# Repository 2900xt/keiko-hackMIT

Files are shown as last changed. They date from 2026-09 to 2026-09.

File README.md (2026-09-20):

<div align="center">

# 🐋 Keiko

**Hydrophones in Boston Harbor that turn underwater sound into a live, searchable stream of what's happening on the water** — whale species, where they are, how the soundscape is drifting, and an alert when a right whale is heard.





Built by [Moby Labs](https://github.com/2900xt) · Taha Rawjani ([@2900xt](https://github.com/2900xt)) · Matthew Li ([@Mallhw](https://github.com/Mallhw))

</div>

---

```mermaid
flowchart LR
    subgraph nodes["Nodes  ·  piezo hydrophone → ADC → UDP"]
        direction TB
        UNOQ["Arduino UNO Q<br/>STM32U585 → Bridge → Linux<br/>3.3 kHz · 14-bit"]
        ESP["ESP32-S3 DevKitC-1<br/>hw-timer ISR → USB-CDC / Wi-Fi<br/>8 kHz · 12-bit"]
        NRF["nRF7002 DK<br/>nRF5340 SAADC → nRF70 Wi-Fi<br/>8.2 kHz · 12-bit"]
    end

    nodes -- "KEIK datagrams :5005" --> PIPE

    PIPE["pipeline/keiko_pipeline.py<br/>3 s windows @ 1.5 s hop → whale CNN v2 (22 classes)<br/>→ abstain rule → event = run of whale windows"]

    PIPE -- always --> OUT["pipeline/out/<br/>WAV clips + events.jsonl"]
    PIPE -- "--archive" --> SITE["site/data/<br/>clip + spectrogram + CSV/JSON<br/>→ GitHub Pages"]
    PIPE -- "--server" --> SRV["server/keiko_server.py<br/>TDOA fix + tracks<br/>→ WebSocket → Live map"]
    PIPE -- "--elastic" --> ES["Elasticsearch<br/>keiko-windows · keiko-detections<br/>geo_point · 512-d vector · ELSER · ML anomaly"]

    ES --> KIB["Kibana dashboard<br/>ES|QL alert → Discord/Slack<br/>ask.py (Claude ⇄ ES|QL / kNN / ELSER)"]
```

```mermaid
flowchart LR
    DS["training/dataset<br/>126k clips · 9 sources"] --> CNN["whale CNN v2<br/>(laptop, width 32)"]
    CNN --> VOLO["Voloridge AWS GPU<br/>width 64 · 5 seeds · Charles fine-tune"]
    ISD["NOAA ISD<br/>s3://noaa-isd-pds"] --> JOIN["⋈ buoy noise floor<br/>how much of the background is weather?"]
```

## Table of contents

| | |
|---|---|
| [How it works](#how-it-works) | capture → classify → fan out → ask |
| [Sponsor integrations](#sponsor-integrations) | Arduino · Espressif · Nordic / Hackster · Elastic · Voloridge |
| [Wire protocols](#wire-protocols) | `KEIK` · `KBLK` · WebSocket · detection database |
| [Models](#models) | whale CNN v2 · Moby right-whale ensemble · location table |
| [Repository layout](#repository-layout) | what lives where |
| [How to run](#how-to-run) | no-hardware demo → full stack → each node → Elastic → Voloridge |
| [Tests](#tests) | one command per subsystem |

## How it works

1. **Capture.** A piezo-disc hydrophone (three 27 mm discs in parallel, potted in epoxy — `hardware/hydrophone-cup/`) feeds
   an analog front end into a microcontroller ADC. Three node designs exist (UNO Q, ESP32-S3, nRF7002 DK); each samples in a
   timer-paced thread into 256-sample blocks and ships them as identical `KEIK` UDP datagrams, so the pipeline does not care
   which board is on the other end. Node id, sample rate and timestamps travel in the header.
2. **Classify.** `pipeline/keiko_pipeline.py` reassembles the stream per node, resamples to 32 kHz, cuts 3 s log-mel windows
   (128 mel, 10 Hz–16 kHz, n_fft 1024, hop 320) every 1.5 s and runs the whale CNN v2 (~1.2 M params, ~15 ms/window on an
   M-series CPU). An abstain rule (`P(any whale) − P(no_whale) > margin` **and** top whale class `≥ min_conf`) turns the 22-way
   softmax into whale / no-whale; ≥ 2 consecutive whale windows open an *event*, 2 no-whale windows close it, 30 s hard cap.
3. **Fan out.** Every event lands in `pipeline/out/` as a WAV clip + JSONL line. Flags add sinks: `--archive` writes the
   detection database the website reads, `--server` streams telemetry/audio/windows/events to the central server (TDOA
   localization + tracks + WebSocket to browsers), `--elastic` indexes every window and event into Elasticsearch.
4. **Ask.** Kibana dashboards, an ES|QL alert rule, kNN "sounds like" over the CNN embedding, ELSER semantic search over
   generated descriptions, an ML anomaly job on the soundscape, and `ask.py` — a Claude agent that writes and runs ES|QL.

## Sponsor integrations

| Sponsor | Track | What we built | Where |
|---|---|---|---|
| **Arduino** | Touch Grass | UNO Q node — the one that went in the water. Zephyr MCU sampler → Bridge → Linux Python forwarder, hot-reloadable config, USB relay | [`firmware/unoq/`](firmware/unoq/) |
| **Espressif** | Best Use of Espressif Hardware | ESP32-S3 wideband node, USB-CDC `KBLK` frames or standalone Wi-Fi `KEIK`; parametric buoy hull | [`firmware/esp32-s3/`](firmware/esp32-s3/) |
| **Nordic** | Hackster "Create What's Next" | nRF7002 DK node — sampler + Wi-Fi entirely on the nRF5340, Kconfig-driven, host simulator | [`firmware/nrf7002/`](firmware/nrf7002/) |
| **Elastic** | Find the Signal | Two indices (geo, dense_vector, ELSER), ES\|QL library, kNN + semantic search, ML anomaly job, alert rule, Claude ⇄ ES\|QL agent | [`elastic/`](elastic/) |
| **Voloridge** | Signal in the Noise | GPU training runs on their AWS + NOAA ISD ⋈ hydrophone noise-floor analysis | [`training/voloridge/`](training/voloridge/) |

<details>
<summary><b>Arduino — UNO Q</b> (Touch Grass) · <code>firmware/unoq/</code></summary>

The UNO Q is the node we actually ran in the water. It is two computers on one board and we use both:

- **MCU side (STM32U585, Zephyr via `arduino:zephyr:unoq`).** `sketch/hydro.cpp` runs a cooperative thread paced by a kernel
  timer, reads `A0` with the 14-bit ADC at 3333 Hz (`SAMPLE_PERIOD_US` must be a multiple of the 100 µs Zephyr tick), fills
  a ring of 256-sample blocks, and pushes each block over **Bridge** with `Bridge.notify("hydro/block", …)`. The `.ino` is an
  empty stub so the prototype generator never touches the code.
- **Linux side (Python in an App Lab container).** `python/main.py` receives the notifications, measures the true sample
  rate from MCU timestamps, prints a health line once a second (`fs= 3333.3Hz blocks/s= 13 dc=1.71V rms= 4.2mV …
  mcu_drops=0 missing=0`), forwards every block as a `KEIK` datagram to `KEIKO_UDP_HOST:5005`, and optionally appends a WAV.
  Outside App Lab it speaks MessagePack-RPC to `/var/run/arduino-router.sock` directly.
- **Configuration without restarts.** App Lab's `app.yaml` has no env section, so settings live in `python/keiko.env`; the
  node re-reads it every second, so `make retarget UDP_HOST=<ip>` redirects the stream with no restart (a restart re-flashes
  the MCU over SWD, so hot reload is the normal path).
- **Analog front end (3.3 V, not 5 V tolerant).** Two PN2222 as a Darlington emitter follower, ~1 MΩ input impedance, mid-rail
  bias, output idling at ~1.7 V (`dc=` on the health line must read 1.5–1.9 V or the follower is miswired).
- **Deployment over USB (adb).** A fresh board has SSH off; `make start` rsyncs the app to `~/ArduinoApps/keiko-unoq` over
  `adb push` and runs `arduino-app-cli app restart`, which compiles the sketch *on the board*, flashes the MCU, and starts
  the container. `make wifi SSID=… PSK=…` joins a hotspot over USB (`nmcli`). `VIA=ssh` switches every target to SSH.
- **USB fallback for the audio.** Venue Wi-Fi isolates clients, and adb cannot forward UDP, so `pipeline/usb_relay.py`
  wraps each datagram in a length prefix on the board, sends it down `adb reverse tcp:5006`, and unwraps it onto UDP on the
  laptop (`VIA=usb make live`). ~7 kB/s, no drops.

> [!WARNING]
> The Bridge UART runs at 115200 baud (~11 kB/s), which caps 16-bit audio at ~3.3 kHz (Nyquist 1.67 kHz): fine for
> baleen whales and boats, not dolphin clicks — hence the two wideband nodes below. The front end is **3.3 V, not
> 5 V tolerant**.

</details>

<details>
<summary><b>Espressif — ESP32-S3-DevKitC-1 (N8R8)</b> (Best Use of Espressif Hardware) · <code>firmware/esp32-s3/</code></summary>

The wideband, laptop-optional node. Same analog front end as the UNO Q, on **GPIO1 = ADC1_CH0** (ADC2 is shared with the
Wi-Fi radio and returns garbage while it is on).

- **Sampler.** A 1 MHz hardware timer ISR wakes a FreeRTOS task that `analogRead`s at 8 kHz (12-bit, 11 dB attenuation →
  0–3.1 V) into a ring of 256-sample blocks. `analogRead` costs ~25 µs, so the period can drop to ~50 µs (20 kHz) before
  ticks are missed.
- **Two transports, selected at compile time.**
  - *USB mode:* frames go out over the **native USB-Serial-JTAG** port (~1 MB/s, so no UART bottleneck) as `KBLK` frames with a
    CRC-16/CCITT-FALSE, resynchronised on the magic if a byte is lost. `python/main.py` on the laptop validates the CRC,
    re-emits each frame as a `KEIK` datagram, and prints the health line (adds `crc_bad=`).
  - *Wi-Fi mode:* copy `sketch/wifi_config.h.example` → `wifi_config.h` (gitignored) with SSID/PSK/pipeline address and
    reflash. The board then builds the `KEIK` datagram itself (`fs` measured on-board, `t_ns` = `esp_timer_get_time()` × 1000)
    and sends it straight to the pipeline. Serial frames still flow when a host is attached; unplugged, the sender skips
    serial so a stalled USB write can never block the Wi-Fi path.
- **Build.** `sketch.yaml` profile `esp32:esp32:esp32s3` with native USB CDC, 8 MB flash, octal PSRAM; `make flash`
  auto-detects `/dev/cu.usbmodem*`. First flash over native USB may need BOOT-held + RESET.
- **Buoy.** `hardware/buoy-v2/` is a parametric OpenSCAD hull sized for exactly this DevKitC plus a 5,000 mAh bank, antenna
  ~31 mm above the waterline, reviewed adversarially by OpenAI Codex (`codex_*.md`).

</details>

<details>
<summary><b>Nordic Semiconductor — nRF7002 DK</b> (Hackster "Create What's Next") · <code>firmware/nrf7002/</code></summary>

A port of the UNO Q sampler to the nRF5340 app core with **no Linux side at all**: the MCU owns the Wi-Fi link.

- **Stack.** Zephyr / nRF Connect SDK v3.0 (`nrf7002dk/nrf5340/cpuapp`, `CONFIG_WIFI_NRF70`), IPv4 + DHCP + UDP sockets,
  `CONFIG_DNS_RESOLVER` so the UDP target can be a hostname. `src/main.c` has the same kernel-timer-paced sampler thread and
  ring as the UNO Q, then a sender loop on `main` and a health line on the J-Link VCOM0 console. LED1 blinks with the
  sampler, LED2 is on while Wi-Fi is up. Wi-Fi drops reconnect with the same `seq` counter; the sampler never stops.
- **ADC.** SAADC channel 0 on AIN0 (`P0.04`, the DK's "A0"), gain 1/3 with the internal 0.6 V reference → 0–1.8 V, 12-bit,
  10 µs acquisition. Period is in RTC ticks (32768 Hz), so rates are `32768/N` — default N=4 → 8192 Hz; N=2 → 16 kHz for
  dolphin clicks. `fs` is measured from block timestamps and written into the header, so the receiver never needs N.
- **Analog front end (1.8 V rail).** The Darlington follower does not fit two Vbe drops in 1.8 V and the SAADC does not need
  it (accepts sources ≤ ~200 kΩ at 10 µs; the piezo stack is ~3.5 kΩ at 500 Hz), so it is passive: 10k/10k mid-rail divider
  + 10 µF, 470k bias into the piezo, 10k series into AIN0 with the pin clamps absorbing knocks. `dc=` should read 0.8–1.0 V.
- **Configuration.** `keiko.conf` is Kconfig (`CONFIG_KEIKO_WIFI_SSID`, `_PSK`, `_UDP_HOST` — default `255.255.255.255`
  subnet broadcast so any laptop on the hotspot just listens — `_UDP_PORT`, `_NODE_ID`, `_SAMPLE_PERIOD_TICKS`). Overridable
  per build: `make flash SSID=hotspot PSK=secret UDP_HOST=10.0.0.5`. `Kconfig` declares the options; the packed header
  struct has a `BUILD_ASSERT` on its 26-byte size and `host/test_node.py` checks the Python side against the same layout.
- **No board yet?** `make sim` emits the identical stream from a Mac (`host/sim_node.py`); `make test` checks the packet
  format offline. `make sdk` installs nrfutil + the toolchain (~4 GB); the Makefile wraps `west` in
  `nrfutil sdk-manager toolchain launch` if it is not on PATH.

</details>

<details>
<summary><b>Elastic — Find the Signal</b> · <code>elastic/</code></summary>

Elasticsearch is where the stream stops being audio and becomes something you can ask questions of. Everything below is
provisioned by one script (`setup.py`) against an Elastic Cloud trial and fed live by `pipeline … --elastic`.

**Indices** (index templates in `mappings/`):

| index | one doc per | notable fields |
|---|---|---|
| `keiko-windows` | classifier window (every 1.5 s) | `label`, `whale`, `confidence`, dynamic `probs.*` (22 class probabilities), `audio.rms_db/peak_hz/centroid_hz/bandwidth_hz/flatness`, `net.*` packet loss, `location` `geo_point`, `in_event` |
| `keiko-detections` | event | `species`, `confidence`, `duration_s`, `location` + `buoy_location` `geo_point`, `fix.{err_m,method,arrivals[]}` from the TDOA solve, `embedding` `dense_vector` 512-d cosine, `description` `semantic_text` (ELSER), `track_id` |

**Write path.** `keiko_es.py` builds the docs (`window_doc`, `detection_doc`, `describe`) and bulk-writes through a buffered
writer so the pipeline's 1.5 s loop never blocks on the network. `features.py` computes the spectral descriptors per window and
takes the CNN's pooled 512-d activations (mean‖max over the last conv block) as the embedding — the same tensor the classifier
uses, so "sounds like" is in the model's own feature space. `describe` writes a plain-English paragraph per event for
ELSER to embed ("Confident humpback whale call (0.91) at buoy KEIKO-01 Saturday 20 September 2026 07:35 UTC in the early
morning. Lasted 4.5 s over 3 classifier windows. Low frequency, tonal sound: peak 410 Hz, centroid 520 Hz, level −38 dBFS."),
so "long low moan at night" finds it.
`backfill.py` replays `pipeline/out/events.jsonl` + `site/data/detections.csv` through the same path, re-running the CNN on
each clip for the embedding.

**Read paths.**
- **ES|QL** — `queries.esql` holds 11 queries: what's on the water now, detections per 15 min per buoy, soundscape floor vs
  whale share, hour-of-day, the right-whale question, per-buoy stream loss, the classifier's second guesses, sound character per
  species, centroid of fixes and distance from the harbour entrance, low-confidence windows, field vs synthetic.
- **kNN** — `ask.py --similar <id>` runs a `knn` query on `embedding` to find the events that sound most like a given one.
- **Semantic** — `ask.py --semantic "long low tonal call at night"` runs a `semantic` query on `description` (ELSER).
- **ML** — `setup.py` creates the `keiko-soundscape` anomaly-detection job + datafeed over `keiko-windows` (level jumps,
  unusual spectral character); `ask.py --anomalies` lists its records.
- **Alerting** — an ES|QL rule every minute: `FROM keiko-detections | WHERE species == "North Atlantic right whale" AND
  confidence >= 0.7 …` → webhook connector to Discord/Slack ("slow to 10 kn"). NOAA's seasonal management areas are the reason
  the buoys exist; this is the *action*.
- **Kibana** — `kibana/dashboard.md` is the six-panel Lens recipe (all ES|QL panels) plus data views created by `setup.py`.
- **Agent** — `ask.py "<question>"` gives Claude (`claude-opus-5`) both index schemas, an ES|QL cheat sheet and three tools
  (`esql`, `similar_sounds`, `semantic_search`); it writes the query, runs it, and answers. Guarded to read-only `FROM keiko-*`
  queries. `-v` prints every query it tries.

> [!TIP]
> Without ML nodes (`setup.py --no-elser --no-ml`) `description` degrades to `text` and `--semantic` to a `match` query.
> Unit + integration tests: `test_elastic.py`.

</details>

<details>
<summary><b>Voloridge — Signal in the Noise</b> · <code>training/voloridge/</code></summary>

Two uses of what Voloridge hands out: their AWS instances for training, and NOAA ISD from their curated dataset list for
the insight.

**1. Training on Voloridge compute.** The whale CNN's laptop run is width 32 at ~25 s/epoch over the 5.1 GB v2 tensor set.
On a Voloridge `g5` (Amazon Linux 2023, `us-east-1`) `configs/pretrain_gpu.json` scales this to width 64,
40 epochs, batch 256, then 4 more seeds for a seed-variance estimate, a
`--no_merge_rare` run that gives the 4 rare species their own classes, and `train/finetune.py` transfers the
pretrained model to our own Charles River / Boston Harbor recordings (`data/charles_v2`: motorboat / crew shell / ambient /
rain / unknown; stem + blocks 0–1 frozen). `infra/` is the plumbing: `check.sh` (ssh, `nvidia-smi`, disk, IAM role),
`bootstrap_instance.sh` (dnf, venv, torch cu12, boto3, Voloridge's tools), `sync_up.sh` / `sync_down.sh` (rsync code + tensors
up, `runs/` + `models/` down), `remote.sh run <name> <cmd>` (detached tmux per run, `make logs RUN=…`). Outputs are the same
`runs/<name>/{best.pt,test_metrics.json}` + `models/*.pt` layout as `training/whale_cnn/train.py`, so
`keiko_pipeline.py --model` takes any of them unchanged. Everything is `voloridge.env` (host, user, key — not committed).

**2. NOAA ISD ⋈ hydrophone noise floor.** Boston Logan (USAF 725090 / WBAN 14739, 6 km from the buoy) reports wind,
pressure, precip hourly. The question: how much of the underwater background is weather?
- `data/fetch_isd.sh` uses Voloridge's own `noaa_isd/fetch.py` (synced from `s3://voloridge-hack-mit-2026/src`, read for free
  through the instance's `AmazonS3ReadOnlyAccess` role + S3 gateway endpoint) to pull the station's years from `s3://noaa-isd-pds`.
- `data/parse_isd.py` parses the fixed-width records — mandatory section (wind dir/speed, temp, dew point, SLP, visibility) +
  the `AA1` precipitation group — drops rows with failing QC codes, resamples to the hour.

> [!NOTE]
> **Two sources, one table.** The public ISD archive trails the present by months (ISD is the *archive* of the ASOS/METAR
> reports the NWS API serves live), so `data/fetch_nws.py` pulls
> `api.weather.gov/stations/KBOS/observations` for the recording window, maps it onto the same columns, and merges with a
> `source` column (`isd` / `nws`) — same instrument, same station, hours old instead of a year.

- `analysis/noise_floor.py` computes the 30th-percentile band level in 10–1000 Hz per recording (the same `floor` statistic
  the live pipeline reports) and buckets it hourly UTC; `analysis/join_isd.py` inner-joins on the hour and reports Spearman
  correlation of floor vs wind speed, precip, and pressure tendency, plus a partial residual after removing the diurnal
  boat-traffic cycle → `analysis/out/noise_vs_weather.{csv,png}` + `summary.json`.
- The join requires ≥ 4 overlapping buoy-hours before it reports statistics, so a single short deployment cannot produce a
  spurious correlation; the analysis is designed for recordings spanning a wind change.

</details>

## Wire protocols

<details>
<summary><b>KEIK</b> — node → pipeline UDP datagram (all three nodes)</summary>

One datagram per block, little-endian, 26-byte header followed by `n × int16` samples:

| field | type | value |
|---|---|---|
| `magic` | `4s` | `"KEIK"` |
| `ver` | `B` | `1` |
| `node` | `B` | 0 = UNO Q, 1 = ESP32-S3 / nRF7002 |
| `fmt` | `B` | `0` = int16 raw ADC |
| `bits` | `B` | ADC resolution: 14 / 12 / 12 |
| `fs` | `f` | sample rate in Hz, **measured** by the sender |
| `seq` | `I` | block sequence number |
| `t_ns` | `Q` | timestamp, ns |
| `n` | `H` | samples in this block (256) |

`node`: 0 = UNO Q, 1 = ESP32-S3 / nRF7002 (`KEIKO_NODE_ID`). `bits`: 14 / 12 / 12. `fs` is *measured* by the sender from MCU
timestamps, so the receiver never needs the nominal period. `t_ns` is host arrival time on the UNO Q and node uptime on the
Wi-Fi nodes; multi-node TDOA uses a shared clock (SNTP over the same link). The pipeline keys streams by `node`, detects gaps from `seq`, and reports loss as `net.dropped_packets`.

</details>

<details>
<summary><b>KBLK</b> — ESP32-S3 → laptop serial frame (USB mode only)</summary>

| field | type | value |
|---|---|---|
| `magic` | `4s` | `"KBLK"` |
| `seq` | `I` | frame sequence number |
| `t0_us` | `I` | first-sample time, µs |
| `dropped` | `I` | blocks dropped so far |
| `n` | `H` | samples in frame |
| samples | `n × int16` | raw ADC 0..4095 |
| `crc` | `H` | CRC-16/CCITT-FALSE over everything before it |

Resynchronised on the magic if a byte is lost; `python/main.py` re-emits each valid frame as a `KEIK` datagram with `bits=12`.

</details>

<details>
<summary><b>WebSocket</b> — pipeline → server → browsers (<code>server/keiko_server.py</code>, <code>site/lib/feed.ts</code>)</summary>

Clients send `{"role": "node"}` (pipeline) or `{"role": "browser"}` first. Node → server messages carry a `type`:
`telemetry`, `audio` (256 samples + 80 spectrogram bins, ~15/s), `window` (one per classifier window), `detection`.
Server → browser: the same plus `hello` (buoys, recent detections, tracks), `buoys`, `track`, `status`; `detection` gains a
`fix` (`lat`, `lon`, `err_m`, `arrivals[]`, `simulated_buoys[]`) and a `track_id`.

**Localization.** One physical buoy cannot fix a position, so the server completes the array with two *virtual* buoys
(`KEIKO-02`/`-03`, ~350 m up- and down-channel, flagged `simulated` everywhere — dashed on the map, `SIM` in the arrivals
table). A hidden source (random walk, 1–2 m/s) gives true arrival times; the real buoy's arrival is the event time, the virtual
ones get 2 ms jitter. The fix itself is a genuine TDOA solve: multi-start Gauss-Newton on the hyperbolic residuals at 1480 m/s,
with a 2σ error radius from timing noise mapped through the geometry. Over 300 simulated calls: median 3.7 m from the hidden
source, truth inside the radius 96 % of the time. Consecutive fixes of one species within 10 min form a track (`T001`, …).

</details>

<details>
<summary><b>Detection database</b> — <code>site/data/</code> (plain files, published with the site)</summary>

`detections.csv` is the source of truth (`id, buoy_id, timestamp_utc, latitude, longitude, confidence, species, peak_hz,
duration_s, sample_rate_hz, clip_path, spectrogram_path, source ∈ {field, replay, synthetic}, notes`), `detections.json` the typed
copy the site reads, `buoys.csv` the registry, `clips/<id>.wav` 16-bit mono PCM, `spectrograms/<id>.png` a 0–1 kHz mel
spectrogram in the site's colour ramp with quiet bins transparent, `schema.json` a JSON Schema. `site/tools/keiko_data.py add|rebuild|synth`
maintains it; `pipeline … --archive` calls `add` per event. Readable straight from
`https://raw.githubusercontent.com/2900xt/keiko-hackMIT/main/site/data/detections.csv`.

</details>

## Models

<details>
<summary><b>Whale CNN v2</b> — the classifier the pipeline runs · <code>training/whale_cnn/</code></summary>

- **Data.** `training/dataset/` is a unified SQLite of 126,563 clips / ~99 h / 59 species from nine public sources (Watkins
  WHOI, ReefSet, ToadFishFinder, Cornell/Kaggle right-whale challenge, BEANS HICEAS minke, Orcasound Pod.Cast, three Zenodo
  fish sets) plus a literature-derived catalogue of 75 datasets and 122 call types. `scripts/extract_features_v2.py` makes
  71,522 × (128 × 301) float16 log-mel windows in 22 classes: species for baleen + non-dolphin toothed whales, **genus** for
  dolphins, `other_baleen` / `other_toothed`, `no_whale_noise` (ambient, vessels, detector negatives), `no_whale_biophony`
  (fish, seals, reef). Splits are by **recording group** (tape / fold / site / date), so no session leaks; big classes capped
  at 6k windows spread across up to 147 groups; z-scored per recording.
- **Model.** Stem (avg-pool 2 + 5×5 stride-2 conv) → 4 blocks (32→64→128→256, 2× conv3×3 + BN + ReLU + max-pool) → mean‖max
  global pool → dropout 0.5 → linear. ~1.2 M params, input `(B,1,128,301)`. Class-balanced sampling, SpecAugment, **random
  bandwidth masking** (so recorder sample rate cannot be used as a cue for species), mixup,
  label smoothing, AdamW + one-cycle, early stop on val macro-F1. Exported as `.pt` + `.onnx` (`log_mel` → `logits`).
- **Numbers (test).** Window macro-F1 0.45, clip-level 0.44, hierarchy (baleen / toothed / no-whale) 0.87. Right whale 0.96,
  common minke 0.88, fin 0.83, bowhead 0.82, blue 0.80, orca 0.80, humpback 0.62.
- **Abstain rule** (`predict.py`, used by the pipeline at `--min_conf 0.8 --margin 0.2`): false alarms on no-whale windows
  0.02 — the pipeline additionally needs ≥ 2 consecutive windows. `0.6 / 0.2` trades a higher false-alarm rate (0.19) for
  higher recall on live calls.

</details>

<details>
<summary><b>Moby / Keiko right-whale ensemble</b> · <code>training/moby/</code></summary>

PyTorch port of the ISEF *MobyGlobal* two-branch model: a 2D branch (Conv2d 1→16→32→64→128 + CBAM on a 103×126 stack of
log-mel‖MFCC‖chroma‖spectral-contrast) and a 1D branch (Conv1d 7→64→128 + BiLSTM(64) over RMS, centroid, bandwidth, rolloff,
flatness, ZCR, YIN f0), concat 384 → 256 → 64 → 2, K-fold ensemble by mean softmax. ~358k params per fold. Trained on the
30,000 Cornell/Kaggle clips (2 s @ 2 kHz, 7,027 NARW upcalls): test AUROC **0.9766** (poster 0.977, Cornell baseline 0.72).
`models/keiko.pt` adds 3,073 Watkins baleen windows grouped by tape: AUROC 0.9816 overall, 0.9750 Kaggle-only, recall 1.0 on
held-out Watkins tapes. Exported as one ONNX graph (`x2d`, `x1d` → `p_whale`).

</details>

<details>
<summary><b>Whale location table</b> · <code>training/location/</code></summary>

`whale_locations.csv`: 48k real detection events with sensor position + UTC time, from Watkins (11,225 cuts → 214
recording-day events, note-parsed positions cross-checked to 2°), DCLDE 2027 killer-whale annotations (34,423 calls at 23 fixed
hydrophones, ecotype labels), and the AAD Antarctic blue/fin library (77,080 calls at 10 moorings). Plus `whale_presence_daily.csv`
(site × species × date) and `sites.csv` (170 sensors). Presence-only; supports occupancy / seasonal models, not trajectories.

</details>

## Repository layout

| path | what |
|---|---|
| `firmware/unoq/` | Arduino UNO Q node: Zephyr sketch (MCU) + App Lab Python (Linux), `keiko.env`, Makefile over adb/ssh |
| `firmware/esp32-s3/` | ESP32-S3 DevKitC-1 node: USB-CDC `KBLK` frames or Wi-Fi `KEIK` datagrams, laptop forwarder |
| `firmware/nrf7002/` | nRF7002 DK node: nRF Connect SDK app, Kconfig settings, simulator, host tools |
| `firmware/uno-q-hydrophone/` | the first App Lab experiment: `analogRead(A0)` loudness bar (superseded by `unoq/`) |
| `pipeline/` | `keiko_pipeline.py` (UDP → CNN → events → sinks), `replay_wav.py`, `live.sh`/`demo.sh`, `usb_relay.py`, `netinfo.py`, tests |
| `server/` | `keiko_server.py`: WebSocket hub, TDOA localization, tracks, `--inject` fake detections |
| `elastic/` | Elasticsearch layer: index templates (geo, dense_vector, ELSER), `--elastic` ingest, ML anomaly job + alert rule setup, ES\|QL library, kNN/semantic search, `ask.py` (Claude ⇄ ES\|QL agent) |
| `site/` | Next.js 16 static export: landing, live map (Leaflet), waveform + spectrogram canvases, detection database UI; `data/` is the database; `tools/keiko_data.py` |
| `training/dataset/` | marine sound database builder (SQLite + audio), feature extractors, literature survey |
| `training/whale_cnn/` | the classifier: `train.py`, `predict.py`, `models/whale_cnn_v2.*` |
| `training/moby/` | right-whale two-branch ensemble |
| `training/voloridge/` | GPU training on Voloridge AWS + NOAA ISD noise-floor join |
| `training/location/` | real whale detection × position × time table |
| `hardware/` | `hydrophone-cup/` potting mold, `buoy-v2/` OpenSCAD hull for the ESP32 + Codex reviews, `buoy-3d/`, `buoy-sla/` STLs |
| `.github/workflows/pages.yml` | builds `site/` (with `data/`) and deploys to GitHub Pages on push to `main` |

## How to run

> [!TIP]
> **Fastest path to a whale on screen:** `cd pipeline && make venv && make test && make demo` — no hardware, no cloud.

All Python except the firmware-local venvs uses one repo venv at `.venv/` (torch, librosa, soundfile, scipy, …, ~2 GB):

```bash
cd pipeline && make venv
```

<details open>
<summary><b>No hardware: test + demo</b></summary>

```bash
cd pipeline && make test          # ~15 s: white noise → 0 events, humpback sample → a humpback event
```

```bash
cd pipeline && make demo          # loops 38 s of NPS humpback song through replay_wav.py as if a node were streaming
```

Expect `WHALE Megaptera_novaeangliae` every 1.5 s during song and `EVENT … humpback whale` when a bout ends.
`CLIP=path make demo` for any WAV/FLAC/MP3. `make demo ARGS="--archive --source replay"` also writes the events into
`site/data/`; `ARGS="--elastic"` indexes them; `ARGS="--server ws://127.0.0.1:8765"` feeds the map.

</details>

<details>
<summary><b>Full local stack: server + site + demo</b></summary>

```bash
cd pipeline && make server                                # ws://0.0.0.0:8765 (or `make server ARGS="--inject 6"` for fake detections)
```

```bash
cd site && npm install && npm run dev                     # http://localhost:3000 · /app/ is the live map + database
```

```bash
cd pipeline && make demo ARGS="--server ws://127.0.0.1:8765"
```

The Live tab falls back to a synthetic feed after 4 s without a server and switches to the real one when it appears. The
static build (GitHub Pages) has no server; set `NEXT_PUBLIC_KEIKO_WS` at build time to point a deployed site at one.

The **Ask** button (bottom right) is a chat over the Elasticsearch data: `elastic/ask_server.py` (`http://localhost:8766`)
runs `ask.py`'s Claude ⇄ ES|QL / kNN / ELSER loop per question. Same deal as the WebSocket: `NEXT_PUBLIC_KEIKO_ASK`
points a deployed site at one, and the button is hidden when it is unset.

</details>

<details>
<summary><b>Arduino UNO Q node (USB-C, no Wi-Fi needed)</b></summary>

```bash
cd firmware/unoq && make core     # once: arduino-cli + arduino:zephyr core (~1 GB, includes adb)
```

```bash
cd firmware/unoq && make start && make logs     # push app over adb, compile + flash on the board, start Python; first run ~2 min
```

Health line should show `fs= 3333.3Hz … dc=1.71V`. Then, on a phone hotspot shared by board and laptop:

```bash
make -C firmware/unoq wifi SSID='<hotspot>' PSK='<password>'
```

```bash
cd pipeline && make live          # netinfo.py picks the laptop IP, retargets the node (hot reload, no restart), runs the pipeline
```

No usable network at all: `VIA=usb make live` relays the stream over the USB cable. `make record DURATION=30` pulls a WAV
to `recordings/`; `make -C firmware/unoq retarget UDP_HOST=auto` sends the stream back to the board itself.

</details>

<details>
<summary><b>ESP32-S3 node</b></summary>

```bash
cd firmware/esp32-s3 && make core          # once: arduino-cli + esp32:esp32 core (~600 MB)
```

```bash
cd firmware/esp32-s3 && make flash && make start   # port labelled USB (not UART); health line, blocks → udp 127.0.0.1:5005
```

```bash
cd pipeline && ../.venv/bin/python keiko_pipeline.py --port 5005     # in another terminal
```

Wi-Fi mode (no laptop): `cp sketch/wifi_config.h.example sketch/wifi_config.h`, fill in SSID/PSK/pipeline IP, `make flash`.
`make start UDP_HOST=<ip>` forwards to another machine in USB mode.

</details>

<details>
<summary><b>nRF7002 DK node</b></summary>

```bash
cd firmware/nrf7002 && make sdk            # once: nrfutil + nRF Connect SDK v3.0 toolchain into ~/ncs (~4 GB)
```

```bash
cd firmware/nrf7002 && make flash SSID='<hotspot>' PSK='<password>' && make monitor   # J-Link USB port; console shows wifi: up, ip …
```

```bash
cd pipeline && make live-nrf               # the node broadcasts to the subnet by default; this just listens on :5005 as KEIKO-02
```

No board: `make sim` in one terminal, `make live-nrf` in another. `make retarget UDP_HOST=<ip>` is a reflash here.

</details>

<details>
<summary><b>Elastic</b></summary>

1. Elastic Cloud trial → create a deployment (ML on by default) → API key with write access.
2. `cp elastic/.env.example elastic/.env`; fill `ELASTIC_URL` (or `ELASTIC_CLOUD_ID`), `ELASTIC_API_KEY`, `KIBANA_URL`,
   `ANTHROPIC_API_KEY` (for `ask.py`), optionally `KEIKO_WEBHOOK_URL`.

```bash
.venv/bin/pip install -r elastic/requirements.txt
```

```bash
cd elastic && ../.venv/bin/python setup.py && ../.venv/bin/python backfill.py && ../.venv/bin/python setup.py --status
```

```bash
cd pipeline && make demo ARGS="--elastic"           # or make live ARGS="--elastic"; combine with --server / --archive freely
```

```bash
cd elastic && ../.venv/bin/python ask.py -v "is the noise floor at KEIKO-01 higher tonight than this afternoon?"
```

`ask.py --similar <id>` · `--semantic "…"` · `--anomalies` · `--esql '<query>'` run without an LLM. Dashboard recipe:
`elastic/kibana/dashboard.md`. Self-hosted without ML: `setup.py --no-elser --no-ml`.

</details>

<details>
<summary><b>Voloridge</b></summary>

GPU box (instance details from the booth into `training/voloridge/voloridge.env`):

```bash
cd training/voloridge && make check && make bootstrap && make sync-up && make pretrain && make logs RUN=volo_w64
```

```bash
cd training/voloridge && make finetune && make sync-down     # after pretrain; needs `make charles-features` first
```

ISD + noise floor (no GPU, runs anywhere; needs `boto3 matplotlib` on top of the pipeline venv):

```bash
cd training/voloridge && make all-local    # = tools → isd → isd-parse → nws → noise-floor → join  → analysis/out/noise_vs_weather.*
```

</details>

<details>
<summary><b>Training from scratch</b></summary>

```bash
cd training/dataset && ./fetch_data.sh && python3 scripts/build_db.py && python3 scripts/extract_features_v2.py   # ~20 GB raw, 5.1 GB tensors
```

```bash
cd training/whale_cnn && python train.py --features ../dataset/features/v2_32k_mel128_3s --epochs 25 --patience 5 --export models/whale_cnn_v2
```

```bash
cd training/moby && python3 features.py && python3 train.py --features ../dataset/features/moby_narw_watkins.npz --out models/keiko.pt
```

`python predict.py file.wav --min_conf 0.8` in either folder classifies any recording (resamples itself).

</details>

<details>
<summary><b>Site deploy</b></summary>

Push to `main` touching `site/**` runs `.github/workflows/pages.yml`: `npm ci && npm run build` (which copies `data/` into
`public/data/` first) with `NEXT_PUBLIC_BASE_PATH` set from `configure-pages`, then uploads `site/out/`. Locally:
`npm run build && npm start`.

</details>

## Tests

| what | command |
|---|---|
| pipeline regression (noise → 0 events, humpback → event) | `cd pipeline && make test` |
| Elastic doc shapes, features, query guard + cluster round-trip | `cd elastic && ../.venv/bin/python test_elastic.py` |
| UNO Q Python side with synthetic blocks | `cd firmware/unoq && make venv && make test` |
| ESP32-S3 Python side with synthetic frames | `cd firmware/esp32-s3 && make venv && make test` |
| nRF7002 packet layout via the simulator | `cd firmware/nrf7002 && make test` |
| firmware compile checks without a board | `make check` (unoq, esp32-s3) · `make build` (nrf7002) |
| site types | `cd site && npm run typecheck` |

---

<div align="center">
<sub>Keiko · HackMIT 2026 · <a href="https://2900xt.github.io/keiko-hackMIT/">live site</a> · <a href="site/data/">detection database</a></sub>
</div>

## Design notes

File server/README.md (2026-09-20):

# Keiko central server

One Python process between the pipeline and the website: it takes each detection the pipeline hears, localizes
it across the buoy array, groups fixes into tracks, and streams everything (telemetry, live audio, "hearing now",
detections with fixes, tracks) to every open browser over a WebSocket.

```
pipeline ──ws──►  keiko_server.py  ──ws──►  site (Live tab)
 --server                │
                    TDOA fix + tracks
```

## Run

```bash
cd pipeline && make server                     # ws://0.0.0.0:8765 (needs the pipeline venv: websockets)
cd pipeline && make live ARGS="--server ws://127.0.0.1:8765"    # or make demo ARGS=... without a board
cd site && npm run dev                          # the Live tab connects to ws://localhost:8765 in dev
```

`make server ARGS="--inject 6"` fakes a detection every 6 s so the map can be worked on without a pipeline: a
humpback in the harbor, a motorboat or crew shell on the Charles. `--site charles` (default) or `--site harbor`
picks the buoy position and channel axis from `site/data/sites.json`, the same file the website's `?site=` reads.

The site's static build (GitHub Pages) has no server and keeps its synthetic feed; set `NEXT_PUBLIC_KEIKO_WS`
at build time to point a deployed site at a reachable server. In `npm run dev` the page falls back to the
synthetic feed after 4 s without a server and switches to the real one when it appears.

## Localization — what is real and what is not

One physical buoy cannot fix a position. The server completes the array with two **virtual buoys**
(`KEIKO-02`, `KEIKO-03`, ~350 m up- and down-channel on the far side, flagged `simulated` everywhere they
appear — dashed on the map, `SIM` in the arrivals table, named in the rail's footnote).

For each detection a hidden source position (a random walk in the channel, 1–2 m/s) gives the true arrival
time at each buoy; the real buoy's arrival is the event time, the virtual ones get 2 ms of jitter. The **fix
is a genuine TDOA solve** — multi-start Gauss-Newton on the hyperbolic residuals at 1480 m/s, with an error
radius from the timing noise mapped through the geometry (2σ). Only two of the three arrival times are made up.
Over 300 simulated calls the solve lands a median 3.7 m from the hidden source and the truth is inside the
reported radius 96 % of the time.

Tracks: consecutive fixes of the same species within 10 min form one track (`T001`, …), drawn as a polyline.

## Protocol

Clients send `{"role": "node"}` (pipeline) or `{"role": "browser"}` first. Node → server messages carry a
`type`: `telemetry`, `audio` (256 samples + 80 bins, ~15/s), `window` (one per classifier window), `detection`.
Server → browser: the same plus `hello` (buoys, recent detections, tracks), `buoys`, `track`, `status`;
`detection` gains a `fix` object (`lat`, `lon`, `err_m`, `arrivals[]`, `simulated_buoys[]`) and a `track_id`,
and its `lat`/`lon` become the fix. `site/lib/feed.ts` documents the browser-side shapes.

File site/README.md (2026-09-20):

# Keiko buoy site

Website + detection database for the Keiko buoys. The database is the `data/` folder (see `data/README.md`); the site reads it directly, so publishing this folder with GitHub Pages gives one URL for both.

Next.js (App Router, TypeScript), exported as a static site. `/` is the landing page; the app (live map + database) lives at `/app/`. One buoy, on synthetic data, at one of two demo sites from `data/sites.json`: the Charles River off the MIT Sailing Pavilion (default; the simulated feed sounds like river traffic, motorboats and crew shells, not whales) or Boston Harbor at President Roads (whale-like tonal calls). `/app/?site=harbor` or the Site toggle in the Live rail switches; the choice is remembered in the browser.

```sh
npm install
npm run dev      # http://localhost:3000 (landing) · http://localhost:3000/app/ (live map)
npm run build    # static export to out/, data/ included
```

- `app/` — `layout.tsx` (metadata, whale favicon, fonts — IBM Plex for the app, Geist for the landing), `page.tsx` (landing), `app/page.tsx` (the app, at `/app/`), `globals.css` (dark navy, blue accent, IBM Plex Sans + Mono via `next/font`)
- `components/`
  - `Landing.tsx` — landing page: one hero, a statline, links to the app and the repo
  - `KeikoApp.tsx` — owns the feed, the detection list, the `#live` / `#db` hash route, and table state
  - `LiveView.tsx` — map cell + buoy rail; `MapView.tsx` (Leaflet, client-only), and two translucent panels floating over the bottom of the map: `Waveform.tsx` (raw-signal oscilloscope) and `Spectrogram.tsx` (scrolling mel canvas, quiet bins transparent)
  - `Ask.tsx` — the "Ask Keiko" chat panel (bottom right): posts questions to `elastic/ask_server.py` at `NEXT_PUBLIC_KEIKO_ASK` (dev: `http://localhost:8766`), hidden when unset
  - `DatabaseView.tsx` — summary tiles, `DetectionsChart.tsx` (14-day SVG bars), filter chips, sortable table of `DetectionRow.tsx` (time, location, confidence, spectrogram thumbnail, audio clip); clicking a row opens `DetectionDetail.tsx`, a dialog with the full spectrogram, clip, every field, and a jump to the map
- `lib/`
  - `feed.ts` — synthetic feed: `telemetry` every 2 s, `audio` (spectrogram column) 20×/s, `window` ("hearing now") every 1.5 s, `detection` when an event ends; one soundscape per site (`whale`: tonal sweeps, `river`: motorboat / crew shell passes over lapping water); `feed.synthetic` is true, and the buoy rail says so
  - `sites.ts` — the demo sites (`data/sites.json`), `?site=` / localStorage resolution, the 5 km rule that assigns an archived row to a site
  - `detections.ts` — detection types, archive + buoy loaders, time helpers
  - `dsp.ts` — the "sea" colour ramp (shared with `tools/keiko_data.py`), mel scale, and the thumbnail / WAV a live row renders from its call parameters
  - `hooks.ts` — `useFeedEvent`, `useNow`, `useAudioLevel`, `useElementSize`, `usePlayer`
- `public/data` — copy of `data/` made by `npm run dev` and `npm run build` (gitignored), so the dev server and the static export both serve the database
- `data/` — the detection database: CSV + JSON, one WAV clip and one PNG spectrogram per detection
- `tools/keiko_data.py` — add a detection from a WAV, rebuild the JSON, or generate synthetic rows (`synth --site charles|harbor`)

Deployment: `.github/workflows/pages.yml` builds with `NEXT_PUBLIC_BASE_PATH` set to the Pages base path (`/keiko-hackMIT` for the project site, empty for a custom domain) and uploads `out/`.

To go live, replace `createFeed()` in `lib/feed.ts` with a WebSocket client that emits the same three events. Detection rows render their spectrogram and WAV clip from the call parameters (`f0`, `sweep`, `duration_s`); a real backend would ship a clip URL and a precomputed thumbnail instead.

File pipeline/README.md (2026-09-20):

# Keiko pipeline (MVP)

Turns a hydrophone node's UDP stream into whale detections on the website, in one process:

```
node UDP (KEIK packets) ─► 3 s windows, 50% overlap ─► whale CNN v2 ─► event (run of whale windows)
                                                                          ├─► out/<id>.wav + out/events.jsonl
                                                                          └─► --archive: site/data via keiko_data.py add
```

| | |
|---|---|
| `keiko_pipeline.py` | the receiver + classifier + event logic (`--wav` runs it over a file instead of the network) |
| `replay_wav.py` | streams any WAV as node packets, for demos and tests without a board |
| `requirements.txt` | torch, librosa, soundfile … (same as `training/whale_cnn`, plus scipy/matplotlib/pillow for `--archive`) |
| `Makefile`, `live.sh`, `demo.sh`, `netinfo.py`, `usb_relay.py` | `make test` / `make demo` / `make live` (see below) |
| `test_pipeline.py` | offline regression: noise → no events, humpback sample → humpback event |
| `samples/humpback_nps.mp3` | 38 s of humpback song, National Park Service, public domain — the demo and test input |

## Setup

```bash
cd pipeline && make venv          # once: ../.venv with torch, librosa, ... (a few minutes)
```

## Test (no hardware)

```bash
make test
```

Runs the pipeline over 20 s of white noise at the UNO Q's 3333 Hz (must give no events) and over
`samples/humpback_nps.mp3` (must give a humpback event). Takes ~15 s. Run it after touching thresholds or the model.

## Demo (no hardware)

```bash
make demo                         # ctrl-c stops it
```

`demo.sh` loops the humpback sample through `replay_wav.py` as if a node were streaming it, and runs the pipeline on
it with `--min_conf 0.6`. Expect a `WHALE Megaptera_novaeangliae` line every 1.5 s during song and an `EVENT …
humpback whale` line when each bout ends. `make demo ARGS="--archive --source replay"` also writes the events into
`site/data/` so the website's Database tab shows them (revert or commit that folder afterwards).

The sample is a National Park Service recording from the Glacier Bay hydrophone (public domain, via
[archive.org](https://archive.org/details/HumpbackWhalesSongsSoundsVocalizations)). Any WAV/FLAC/MP3 works:
`CLIP=path make demo`.

## Live against the UNO Q

Board plugged into this machine over USB-C (control goes over adb), board and machine on the same Wi-Fi (the audio
comes over UDP). Venue Wi-Fi usually will not do — MIT GUEST puts the board behind a captive portal and isolates
clients — so use a phone hotspot: join this machine to it, then join the board with

```bash
make -C ../firmware/unoq wifi SSID='<hotspot name>' PSK='<password>'
make live                         # add ARGS="--archive" to write detections to the site database
```

`live.sh` does what you would do by hand:

1. `netinfo.py` asks the board for its addresses over adb and picks this machine's IP on the same subnet
   (override with `UDP_HOST=<ip> make live`).
2. `make -C ../firmware/unoq retarget UDP_HOST=<ip>` pushes a `keiko.env` with that address. The node re-reads the
   file every second and switches its UDP destination — no app restart (restarts re-flash the MCU and have wedged
   the board's router).
3. If the app is not running it runs `make start` there (first time: ~2 min).
4. Prints the node's health line and starts the pipeline. Within a couple of seconds you should see
   `receiving from 192.168.x.y` (or whatever the hotspot hands out), then one line per 1.5 s.

If the pipeline prints `no packets for N s`: check `make -C ../firmware/unoq logs` shows `fs=…` lines (if it stops at
"App started", power-cycle the board), and that both machines really share a network (`netinfo.py` warns when they do
not; `make -C ../firmware/unoq ip` shows the board's). `make -C ../firmware/unoq retarget UDP_HOST=auto` sends the
stream back to the board itself.

No usable network at all? `VIA=usb make live` carries the stream over the USB cable instead: adb cannot forward
UDP, so `usb_relay.py node` on the board wraps each datagram in a length prefix and sends it down
`adb reverse tcp:5006`, and `usb_relay.py host` here unwraps it onto UDP 127.0.0.1:5005 (you then see
`receiving from 127.0.0.1`). ~7 kB/s, no drops; Ctrl-C removes the relay again.

Offline over a recording (`make record` in `firmware/unoq` makes one):

```bash
../.venv/bin/python keiko_pipeline.py --wav ../firmware/unoq/recordings/<utc>.wav
```

What the output means: one line per window (`WHALE` marks windows that pass the abstain rule), then `EVENT …` when a
run of whale windows ends. Events always land in `pipeline/out/` (gitignored) as a clip WAV plus a line in
`events.jsonl`; with `--archive` they also go through `site/tools/keiko_data.py add` (clip, spectrogram,
CSV + JSON row) — commit that folder and the site shows them.

## Knobs

- `--min_conf 0.8 --margin 0.2` — `predict.py`'s abstain rule. The v2 model calls 25–36 % of non-whale windows a
  whale at its defaults (0.5 / 0.1), and on the UNO Q's floating input it said "sperm whale 0.56", so the pipeline
  defaults are stricter. Lower them for a demo with real calls.
- `--min_windows 2` consecutive whale windows to open an event, `--patience 2` no-whale windows to close it,
  `--max_s 30` hard cap. Clip = event ± 0.5 s at the node's own sample rate.
- `--buoy KEIKO-01` looks up position in `site/data/buoys.csv`; `--lat/--lon` override.
- `--hop 1.5` seconds between classifications (~15 ms of CPU per window on an M-series Mac; the model is small).

## Caveats

- The UNO Q node samples at 3.3 kHz (Nyquist 1.67 kHz). The model was trained on 32 kHz audio with bandwidth masking,
  so low-frequency species (right, fin, minke, blue, bowhead) are in band; dolphins and clicks are not.
- Species names shown on the site are common names mapped from the model's classes (`COMMON` in the script);
  dolphin genera are lumped by the model itself.
- `--elastic` ships every window and event to Elasticsearch (embeddings, spectral descriptors, packet loss);
  see `elastic/README.md` for setup, the dashboard, kNN/ELSER search and the ES|QL agent.
- Not yet: running on the board (no torch there — the ONNX model + onnxruntime would fit).

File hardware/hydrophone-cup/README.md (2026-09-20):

# Hydrophone potting cup

Lost-mold cup for potting three 20 mm piezo discs (Cheerock leaded discs, wired in parallel)
in epoxy or hot glue. The PLA is a mold, not a housing; the resin is the seal.

- `hydrophone_cup.scad` — OpenSCAD source (50 mm ID, 35 mm tall, 1.2 mm walls)
- `hydrophone_cup.stl` — export
- `hydrophone_cup_A1.3mf` — sliced for Bambu A1, 0.4 nozzle, PLA, 0.28 mm: **19 min, 12 g**, no supports

Features: floor standoffs so resin flows under the discs, inner pour-line ridge at 25 mm,
three rim tabs with 3 mm holes for tying off the cable, rim notch for the cable during the pour.

Pour: 2–3 mm floor layer, let it gel, discs ceramic-side down on the standoffs, cable tied to a
tab, fill to the pour line, then top off. Keep resin over the disc face under 3 mm.

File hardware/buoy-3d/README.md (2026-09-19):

# Buoy hull 3D prints

Hull from the [T3chFlicks Smart Buoy](https://github.com/sk-t3ch/smart-buoy) (`src/buoy/3d/`), re-oriented for printing.

| File | Orientation | Footprint | Height |
|---|---|---|---|
| `top_zup_100pct.stl` | flat cut face on bed, dome up | 188 mm | 114 mm |
| `bottom_zup_100pct.stl` | rounded apex on bed, open end up | 188 mm | 155 mm |
| `top_zup_70pct.stl` / `bottom_zup_70pct.stl` | same | 132 mm | 80 / 109 mm |
| `top.stl` / `bottom.stl` | originals (Y-up) | | |

## Print settings (PLA, 0.4 nozzle)

- 0.28 mm layers, 3 walls, 10% gyroid infill (mesh already has ~4 mm solid walls)
- Top: tree supports, 45° threshold (only inside the dome crown)
- Bottom: tree supports + brim (apex needs support for its bottom ~25 mm)
- Not watertight and doesn't need to be; it's a prop. Original used PETG, 0.3 mm, 4 perimeters, 15%, ~24 h per half on an Ender.

## Time estimates, Bambu/Prusa class

| Scale | Per half | Filament per half |
|---|---|---|
| 100% | 5–7 h | ~250–300 g |
| 70% | 2–2.5 h | ~100 g |

Too big for desktop SLA (188 mm exceeds Form 3/4 beds). Halves mate via a 160 mm lip on the bottom; no snap fit, tape or glue the seam.

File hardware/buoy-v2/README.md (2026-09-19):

# Buoy v2 (Charles Ear)

Parametric OpenSCAD buoy for one ESP32-S3 DevKitC + USB power bank, with a piezo hydrophone on a tether below.
Designed for two Bambu/Prusa-class PLA printers, one plate each. Reviewed adversarially by OpenAI Codex
(round-1 reports in `codex_*.md`, round 2 in `codex_round2.md`).

## Parts

| File | Print orientation | Size | PLA | Est. time (0.28 mm, Bambu class) |
|---|---|---|---|---|
| `hull.stl` | as exported, floor on bed | 130 mm OD x 100 mm | ~160 g | 3.5–4.5 h (plate A) |
| `lid.stl` | as exported, top face on bed | 139 mm OD x 19 mm | ~88 g | ~2 h (plate B) |
| `head.stl` | as exported, floor on bed | 44 mm OD x 72 mm | ~50 g | ~1.2 h (plate B) |

Regenerate: `openscad --backend=manifold -o hull.stl -D 'part="hull"' buoy_v2.scad` (parts: hull, lid, head, plate_b, all).

## Slicer settings

- PLA, 0.4 nozzle, 0.28 mm layers. **Walls: 5 lines** (2.0 mm hull wall is solid perimeters, no infill in the shell). Floor 6 layers.
- No supports anywhere. Brim on the hull (the two lugs are the widest point).
- Hull is 130 mm across plus 22 mm of lugs; needs a 160 mm bed (fine on 220/250/256 mm beds).
- Lid prints upside down. The internal thread groove is left-handed in the file so it becomes right-handed once flipped onto the hull.

## Assembly

1. **Gasket:** lay a 2 mm rubber cord or two stacked rubber bands in the groove on the neck rim. Screw the lid on 2 turns. Wrap the lid/hull seam with waterproof duct tape before launch (the thread is not a seal; the gasket + tape are).
2. **Power bank** (5,000 mAh, ~95 x 62 x 15 mm, ~115 g; edit the payload block if yours differs) lies flat on the floor between the two rails. **ESP32** stands vertical in the side pocket, antenna end UP, rubber band to the rail. Its antenna sits ~23 mm above the design waterline.
3. **Cable gland:** the hydrophone cable passes through the 3.5 mm hole in the lid. Slide marine adhesive heat shrink over the cable, push it down over the 8 mm boss on the inside of the lid, shrink. Do this with the cable UNTERMINATED, then connect inside. Leave a 120 mm service loop inside.
4. **Bridle:** one line through each bottom lug, equal lengths, joined to a single ring 100–150 mm below the hull. Hang the hydrophone head from that ring. Moor to the same ring, never to the hull top.
5. **Head:** tape 1" fender washers into a stack, drop into the floor pocket. Sealed piezo (balloon/oil or coating, ~24 mm) sits on the three posts under the three tabs. Cable up through the apex hole; zip tie across the two parallel slots for strain relief. Drop line through the eye plate.

## Design numbers (from the file's echo; edit the payload block to match your parts)

Total afloat ~545 g with a 115 g 5,000 mAh bank and 100 g effective tether load. Draft 41 mm, freeboard 45 mm to the neck shoulder and 59 mm to the rim, GM +7 mm before the bridle's pendulum effect (the tether load hanging from a ring 100-150 mm below the hull adds most of the real righting moment). ESP32 antenna top ~31 mm above the waterline.

## Known limits

- Freeboard to the neck is 45 mm, just under the 50 mm the reviewers wanted. Tape the seam. Raising `hull_h` to 110 adds ~8% hull mass if you want more margin.
- Static GM is small (+7 mm). Keep the bridle ring 100-150 mm below the hull with the head hanging from it; that pendulum is what keeps it upright in a wake.
- Printed PLA threads with a rubber-band gasket are splash-tight, not dive-tight. Dunk-test the empty sealed hull for 30 min before loading electronics.
- USB-C from the bank to the ESP32 needs a short right-angle or thin flexible cable; test-fit before printing the second hull.

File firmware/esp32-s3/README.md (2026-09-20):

# ESP32-S3 hydrophone node

Piezo hydrophone captured by an ESP32-S3-DevKitC-1 (N8R8) and shipped as sample blocks over USB to
a laptop, which forwards them to the pipeline over UDP -- same role as the UNO Q node in
`../unoq`, with the laptop standing in for the UNO Q's Linux side (the S3 has none). Or, with
Wi-Fi credentials compiled in, the board sends the UDP stream itself and needs no laptop at all.

```
piezos ─► PN2222 Darlington follower ─► GPIO1 (ADC1_CH0, 12-bit, 8 kHz)
                                          │  hw timer ISR → FreeRTOS sampler task, 256-sample blocks
                                          ▼
                              Serial.write("KBLK" frame)   USB-Serial-JTAG (native USB, ~1 MB/s)
                                          │
                                          ▼
                              python/main.py (laptop) ─► UDP 127.0.0.1:5005 (pipeline) ─► optional WAV
```

## Files

| | |
|---|---|
| `sketch/hydro.cpp` | MCU: hardware-timer-paced sampler task, ring of blocks, framed serial sender |
| `sketch/sketch.ino` | empty stub -- all code is in the `.cpp` so it never touches the `.ino` prototype generator |
| `sketch/sketch.yaml` | build profile (`esp32:esp32:esp32s3`, native USB CDC, 8 MB flash, octal PSRAM) |
| `sketch/wifi_config.h.example` | copy to `wifi_config.h` (gitignored) for Wi-Fi mode: SSID, PSK, pipeline address |
| `python/main.py` | laptop: reads frames from the serial port, health line, UDP forward, WAV log |
| `python/test_node.py` | offline test of the Python side with synthetic blocks (`make test`) |
| `python/keiko.env` | settings: UDP destination, node id, serial port |
| `python/udp_listen.py` | receiver that prints what the UDP stream delivers (`make listen`) |
| `Makefile` | `make core` / `check` / `flash` / `start` / `record` … |

## Analog front end (3.3 V -- ESP32 pins are not 5 V tolerant)

Identical to the UNO Q node's: two PN2222 as a Darlington emitter follower, input impedance ≈ 1 MΩ.
The only wiring difference is the ADC pin -- **GPIO1** (ADC1 channel 0) instead of A0. Stay on ADC1:
ADC2 on the ESP32 family is shared with the Wi-Fi radio and returns garbage while it is on.

```
 3V3 ───┬──────────────┬─── Q1 C ─── Q2 C        Q1, Q2 = PN2222
        │              │
      [1k]           piezos ─── Q1 B                 disks in parallel, twisted pair
        │              │
      Vb ≈ 3.0V ──[1M]─┘        Q1 E ── Q2 B
        │
      [10k]                     Q2 E ──┬── GPIO1
        │                              │
       GND      100nF Vb→GND         [4.7k]  (5.1k from the kit is fine)
                                       │
                                      GND
```

Output idles at ~1.7 V. The health line prints `dc=…V`; if it isn't 1.5-1.9 V the follower is wired wrong.
The S3's ADC at 11 dB attenuation covers 0-3.1 V, so the follower's swing fits with margin.

## Run

One-time on the Mac (installs arduino-cli + the `esp32:esp32` core, ~600 MB):

```bash
make core
```

Compile check without a board (Apple Silicon: `brew install universal-ctags` first -- Arduino's bundled ctags is x86-only):

```bash
make check
```

Offline test of the Python side (`make venv` once to get numpy + pyserial):

```bash
make venv && make test
```

Flash the board -- plug the DevKitC's port labelled **USB** (not UART) into the Mac, then:

```bash
make flash            # auto-detects /dev/cu.usbmodem*; PORT=/dev/cu.xxx to pick one
```

If esptool cannot find the board, hold BOOT, tap RESET, release BOOT, retry (the S3 only needs this
the first time it is flashed over native USB). Then start the host side:

```bash
make start            # health line once a second; blocks go to udp 127.0.0.1:5005
```

Expect a line per second like:

```
fs= 8000.0Hz blocks/s= 31 dc=1.71V rms=  4.2mV peak= 31.0mV mcu_drops=0 missing=0 crc_bad=0
```

The pipeline itself is started by hand -- `pipeline/`'s `make live` is UNO Q-specific (it drives the
board over adb); `keiko_pipeline.py` just listens on 5005 and keys streams by node id, so:

```bash
cd ../../pipeline && ../.venv/bin/python keiko_pipeline.py --port 5005     # in another terminal (make venv there once)
```

To run the pipeline on another machine, `make start UDP_HOST=<its ip>`.

### Record a clip and run it through the whale CNN

```bash
make record DURATION=30                      # -> recordings/<utc>.wav (8000 Hz, 16-bit mono)
```

```bash
../../training/whale_cnn/.venv/bin/python ../../training/whale_cnn/predict.py recordings/*.wav --min_conf 0.8
```

The model resamples to 32 kHz itself. Same caveat as the UNO Q: with nothing wired to GPIO1 it still
reports a species at ~0.5 on pure electrical noise, so check `dc` is 1.5-1.9 V before believing a detection.

### Wi-Fi mode: no laptop

For a buoy in the water. Put the network and the pipeline's address in `sketch/wifi_config.h`
(copy the `.example`; the file is gitignored) and flash again:

```bash
cp sketch/wifi_config.h.example sketch/wifi_config.h && $EDITOR sketch/wifi_config.h && make flash
```

The board joins the network, and for every block sends the same `KEIK` datagram `python/main.py`
would have built -- `fs` measured on the board, `t_ns` = board µs since boot × 1000 -- straight to
`KEIKO_UDP_HOST:KEIKO_UDP_PORT`. `keiko_pipeline.py` needs no change. The serial
frames keep flowing whenever a host is attached, so `make start` still works for a health line during
setup; unplugged, the sender skips serial so a stalled USB write can never hold up the Wi-Fi path.
Venue Wi-Fi usually isolates clients from each other -- a phone hotspot is the reliable choice
(`python3 ../../pipeline/netinfo.py` or `ipconfig getifaddr en0` gives the laptop's address on it).
`make check-wifi` compiles this variant without touching your `wifi_config.h`.

### Settings

`python/keiko.env` -- read by `main.py` at startup; real environment variables and command-line flags
override it. Keys: `KEIKO_SERIAL_PORT` (default `auto`: the first Espressif USB device),
`KEIKO_UDP_HOST` (default `127.0.0.1`), `KEIKO_UDP_PORT` (5005), `KEIKO_NODE_ID` (1 -- the UNO Q is 0),
`KEIKO_WAV`, `KEIKO_QUIET`.

## Serial frame (board → laptop)

One frame per block, little-endian, resynchronised on the magic if a byte is lost:

```
magic 4s "KBLK" | seq I | t0_us I | dropped I | n H | n×int16 raw ADC 0..4095 | crc H (CRC-16/CCITT-FALSE over everything before it)
```

`python/main.py` re-emits each frame as a KEIK datagram (format in `../unoq/README.md`; `bits`=12).

## Limits and knobs

- **Sample rate**: native USB CDC moves ~1 MB/s, so the UART bottleneck the UNO Q has is gone. The
  default is 8 kHz (Nyquist 4 kHz: baleen calls, boat noise, the lower half of dolphin whistles).
  `analogRead` on the S3 takes ~25 µs, so `SAMPLE_PERIOD_US` can go down to ~50 (20 kHz) before the
  sampler task starts missing ticks; raise `BLOCK`/`NBLOCKS` alongside.
- The timer runs at 1 MHz, so `SAMPLE_PERIOD_US` is exact -- the Python side still measures the real
  rate from MCU timestamps and puts that in the UDP header.
- `mcu_drops` > 0 means the sender fell behind (the sampler keeps its timing and overwrites).
  `missing` > 0 means a frame was lost on the wire; `crc_bad` > 0 means a frame arrived corrupted.
  Both should stay 0 on a direct USB connection -- if not, try another cable or skip the hub.
- Block timestamps are `esp_timer_get_time()` (µs since boot); host arrival time goes in the UDP
  header. Fine for single-node work; TDOA between nodes needs a shared clock.

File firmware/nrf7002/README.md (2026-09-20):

# nRF7002 DK hydrophone node

Piezo hydrophone captured by the nRF7002 DK's nRF5340 (SAADC) and sent to the pipeline over Wi-Fi as UDP —
same packets as the UNO Q node, but with no Linux side: the MCU owns the network link. Ported from
`firmware/unoq/` (same sampler thread, ring and header); only the transport changed.

```
piezos ─► passive bias + protection ─► AIN0 / P0.04 (12-bit SAADC, 8192 Hz)
                                          │  Zephyr timer thread, 256-sample blocks
                                          ▼
                                    sender loop (main) ─► UDP 5005 over Wi-Fi (nRF7002) ─► pipeline
                                          │
                                          └─► health line on the J-Link serial console (`make monitor`)
```

## Files

| | |
|---|---|
| `src/main.c` | MCU: kernel-timer-paced SAADC sampler in a cooperative thread, ring of blocks, Wi-Fi bring-up, UDP sender + health line |
| `boards/nrf7002dk_nrf5340_cpuapp.overlay` | SAADC channel 0 on AIN0: gain 1/3, internal 0.6 V ref → 0..1.8 V, 12-bit |
| `prj.conf` | build config: ADC, nRF70 Wi-Fi driver, IPv4/UDP/DHCP, buffers |
| `keiko.conf` | settings: Wi-Fi SSID/PSK, UDP destination, node id, sample rate (the `keiko.env` of this node — baked in at build time) |
| `Kconfig` | declares the `CONFIG_KEIKO_*` options `keiko.conf` sets |
| `host/udp_listen.py` | receiver that prints what the UDP stream delivers (`make listen`) and can record it to a WAV (`make record`); identical to the UNO Q's |
| `host/sim_node.py` | stand-in for the DK: emits the same stream from this Mac (`make sim`) |
| `host/test_node.py` | offline test of the packet format via the simulator (`make test`) |
| `Makefile` | `make build` / `flash` / `monitor` / `listen` / `record` … |

## Analog front end (1.8 V — the nRF7002 DK's I/O rail; the ADC input must never exceed VDD)

The UNO Q's Darlington follower does not fit a 1.8 V rail (two Vbe drops eat most of it), and the SAADC does not
need one: with a 10 µs acquisition it accepts sources up to ~200 kΩ, and three 27 mm disks in parallel (~90 nF)
are ~3.5 kΩ at 500 Hz. So the front end is passive — a mid-rail bias and a series resistor for protection.

```
 VDD (1.8V) ───[10k]───┬─── Vmid ≈ 0.9 V ───[470k]───┬─── piezos (+)      disks in parallel, twisted pair,
                       │                              │                    (−) to GND
                     [10k]         10µF Vmid→GND    [10k]
                       │                              │
                      GND                           AIN0  (P0.04, Arduino header "A0" on the DK)
```

Low-frequency cutoff 1/(2π·470k·90nF) ≈ 4 Hz. The 10k in series with AIN0 plus the pin's own clamp diodes soak up
the tens of volts a knocked piezo can produce. Output idles at ~0.9 V; the health line prints `dc=…V` and it
should read 0.8–1.0 V. Meter the DK's `VDD` header pin first: if it reads 3.0 V your DK is strapped differently —
the divider still lands at VDD/2 but change the overlay to `ADC_GAIN_1_6` and `CONFIG_KEIKO_ADC_FULL_SCALE_MV=3600`.

## Run

One-time on the Mac (nrfutil + the nRF Connect SDK toolchain and tree, ~4 GB):

```bash
make sdk
```

Put the Wi-Fi name/password and, unless the subnet broadcast default is fine, the pipeline machine's IP in
`keiko.conf`. Then, DK plugged in by its J-Link USB port (the one nearest the corner, not the nRF USB):

```bash
make flash
```

(`make build` alone is the compile check.) `make flash` compiles and programs the app core; the first build takes a
few minutes, later ones ~30 s. Then:

```bash
make monitor     # serial console: wifi: up, ip 10.0.0.42 / keiko nrf7002 node 1 -> udp ... / health lines
```

LED1 blinks once a second while the sampler runs, LED2 is on while the Wi-Fi link is up.

Offline test of the packet format, no SDK or board needed:

```bash
make test
```

### Record a clip and run it through the whale CNN (the MVP loop, by hand)

```bash
make record DURATION=30                      # -> recordings/<utc>.wav on this Mac (8192 Hz, 16-bit mono); node keeps running
```

```bash
../../training/whale_cnn/.venv/bin/python ../../training/whale_cnn/predict.py recordings/*.wav --min_conf 0.8
```

Same caveats as the UNO Q: the model resamples to 32 kHz itself, an unwired AIN0 still gets a species at ~0.5 on
noise, so keep `--min_conf` high and check `dc` is 0.8–1.0 V before believing a detection. Archiving a detection on the
website is the same `site/tools/keiko_data.py add …` line as in `firmware/unoq/README.md` (use `--buoy KEIKO-02`).

Expect a line per second on the console like:

```
fs= 8192.0Hz blocks/s= 32 dc=0.91V rms=  2.6mV peak= 19.4mV mcu_drops=0 send_err=0
```

### Feeding the pipeline

The pipeline listens on `0.0.0.0:5005`, so with the default broadcast destination any laptop on the same Wi-Fi as
the DK just runs it: `cd ../../pipeline && make live-nrf`. There is no USB fallback like the UNO Q's `adb reverse`
relay — the node only speaks Wi-Fi — so on a network that isolates clients (MIT GUEST does) put the DK and the laptop
on a phone hotspot. To try the pipeline before the board exists: `make sim` in one terminal, `make live-nrf` in another.

### Settings

`keiko.conf` — Kconfig values compiled into the image; there is no Linux side to re-read a file, so a change is
`make flash` (~1 min). Keys: `CONFIG_KEIKO_WIFI_SSID` / `_PSK`, `CONFIG_KEIKO_UDP_HOST` (default `255.255.255.255`
= the whole subnet; or one IP; a hostname works too since `CONFIG_DNS_RESOLVER` is on, but mDNS `.local` names do
not), `CONFIG_KEIKO_UDP_PORT` (5005), `CONFIG_KEIKO_NODE_ID` (1; the UNO Q is 0), `CONFIG_KEIKO_SAMPLE_PERIOD_TICKS`
(4 = 8192 Hz; 10 = 3277 Hz to match the UNO Q's rate).

Per-build overrides without editing the file: `make flash SSID=hotspot PSK=secret UDP_HOST=10.0.0.5`, or
`make retarget UDP_HOST=<laptop ip>` (the UNO Q's `retarget` is a 1 s hot reload; here it is a reflash).

## UDP packet (same as every node)

One datagram per block, little-endian:

```
magic 4s "KEIK" | ver B 1 | node B | fmt B 0=int16 raw ADC | bits B 12 | fs f Hz | seq I | t_ns Q node uptime | n H | n×int16
```

`src/main.c` has the header as a packed struct with a `BUILD_ASSERT` on its 26-byte size; `host/test_node.py` checks
the Python side against the same layout. `t_ns` is the node's uptime, where the UNO Q put host arrival time.

## Limits and knobs

- **Sample rate is not UART-bound here** (the UNO Q's 115200-baud Bridge capped it at ~3.3 kHz). 8192 Hz is
  16 kB/s of UDP; `CONFIG_KEIKO_SAMPLE_PERIOD_TICKS=2` gives 16 kHz if dolphin clicks matter. Above that the
  10 µs acquisition + conversion (~2 µs) starts to crowd the 61 µs period — drop the acquisition time to 5 µs
  in the overlay (fine for a source under 100 kΩ).
- The period is in RTC ticks (32768 Hz), so rates are 32768/N Hz, never round numbers. fs is measured from block
  timestamps and put in the header, so the receiver never needs to know N.
- `mcu_drops` > 0 means the sender fell behind the sampler (the ring keeps its timing and overwrites).
  `send_err` > 0 means the link was down or `sendto` failed — it counts up while the node is reconnecting; a
  steadily rising value with the link up means the destination is unreachable (wrong subnet, client isolation).
  `missing` on the receiver side (`make listen`) is packets lost in the air.
- Wi-Fi drops are handled: the node reconnects and resumes with the same `seq` counter, the sampler never stops.
- Block timestamps are 30.5 µs RTC resolution and node-local. TDOA between nodes needs a shared clock (SNTP
  over the same link is the obvious next step; not done).
- `boards/*.overlay` and `prj.conf` target nRF Connect SDK v3.0 (`nrf7002dk/nrf5340/cpuapp`, `CONFIG_WIFI_NRF70`).
  On an SDK before v2.7 the driver symbols are the older `CONFIG_WIFI_NRF700X` names. Neither the firmware nor the
  SDK install has been built on this Mac yet — `make build` is the first thing to run when the SDK lands.

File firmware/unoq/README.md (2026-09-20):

# UNO Q hydrophone node

Piezo hydrophone captured by the UNO Q's own MCU (STM32U585) and handed to the Linux side,
which forwards blocks to the pipeline over UDP — same role as the ESP32-S3 / nRF7002 nodes.

```
piezos ─► PN2222 Darlington follower ─► A0 (14-bit ADC, ~3.3 kHz)
                                          │  Zephyr timer thread, 256-sample blocks
                                          ▼
                              Bridge.notify("hydro/block", …)   UART 115200 + RTS/CTS
                                          │
                                          ▼
                              python/main.py ─► UDP 127.0.0.1:5005 (pipeline) ─► optional WAV
```

## Files

| | |
|---|---|
| `sketch/hydro.cpp` | MCU: kernel-timer-paced sampler in a cooperative thread, ring of blocks, Bridge sender |
| `sketch/sketch.ino` | empty stub — all code is in the `.cpp` so it never touches the `.ino` prototype generator |
| `sketch/sketch.yaml` | build profile (`arduino:zephyr:unoq`) |
| `python/main.py` | Linux: receives blocks, health line, UDP forward, WAV log |
| `python/test_node.py` | offline test of the Python side with synthetic blocks (`make test`) |
| `python/keiko.env` | settings: UDP destination, node id, WAV log (app.yaml can't carry env vars) |
| `python/udp_listen.py` | receiver that prints what the UDP stream delivers (`make listen`) and can record it to a WAV (`make record`) |
| `app.yaml` | App Lab / `arduino-app-cli` manifest |
| `Makefile` | `make start` / `logs` / `stop` … over USB (adb) or Wi-Fi (ssh) |

## Analog front end (3.3 V — the UNO Q is not 5 V tolerant)

Two PN2222 from the Elegoo kit as a Darlington emitter follower. Input impedance ≈ 1 MΩ, so with
three 27 mm disks in parallel (~90 nF) the low-frequency cutoff is ~2 Hz.

```
 3V3 ───┬──────────────┬─── Q1 C ─── Q2 C        Q1, Q2 = PN2222
        │              │
      [1k]           piezos ─── Q1 B                 disks in parallel, twisted pair
        │              │
      Vb ≈ 3.0V ──[1M]─┘        Q1 E ── Q2 B
        │
      [10k]                     Q2 E ──┬── A0
        │                              │
       GND      100nF Vb→GND         [4.7k]  (5.1k from the kit is fine)
                                       │
                                      GND
```

Output idles at ~1.7 V. The health line prints `dc=…V`; if it isn't 1.5–1.9 V the follower is wired wrong.

## Run

One-time on the Mac (installs arduino-cli + the `arduino:zephyr` core, ~1 GB; that core also brings `adb`):

```bash
make core
```

Compile check without a board (Apple Silicon: `brew install universal-ctags` first — Arduino's bundled ctags is x86-only):

```bash
make check
```

Offline test of the Python side (`make venv` once to get numpy + msgpack):

```bash
make venv && make test
```

Deploy and run on the board — plug the UNO Q into the Mac with USB-C (directly, no hub), wait for the
heartbeat on the LED matrix, then:

```bash
make start
```

That pushes this folder to `~/ArduinoApps/keiko-unoq` on the board over adb and runs `arduino-app-cli app restart`
there, which compiles the sketch on the board, flashes the MCU over SWD, and starts `python/main.py` in a container.
First run takes ~2 min (numpy install); later runs ~20 s.

```bash
make logs      # last 30 lines        make follow   # stream
make stop      make shell             make ip
```

### Record a clip and run it through the whale CNN (the MVP loop, by hand)

```bash
make record DURATION=30                      # -> recordings/<utc>.wav on this Mac (3333 Hz, 16-bit mono); app keeps running
```

```bash
../../training/whale_cnn/.venv/bin/python ../../training/whale_cnn/predict.py recordings/*.wav --min_conf 0.8
```

(`python3 -m venv .venv && .venv/bin/pip install torch numpy pandas scikit-learn librosa soundfile` once in
`training/whale_cnn/`.) The model resamples to 32 kHz itself. With nothing wired to A0 it still reports a species
at ~0.5 on pure electrical noise, so keep `--min_conf` high and check `dc` is 1.5–1.9 V (front end connected) before
believing a detection. To archive a detection on the website:

```bash
../../site/tools/keiko_data.py add --wav recordings/<utc>.wav --buoy KEIKO-01 --time <utc> --lat 42.34 --lon -70.97 --confidence 0.87 --species "Eubalaena glacialis"
```

then commit and push (`site/tools/requirements.txt` lists its deps; the whale_cnn venv already has them).

Expect a line per second like:

```
fs= 3333.3Hz blocks/s= 13 dc=1.71V rms=  4.2mV peak= 31.0mV mcu_drops=0 missing=0
```

Over Wi-Fi instead of USB: a fresh board has SSH off. Run `make enable-ssh` once over USB, then add
`VIA=ssh BOARD=<ip or name.local>` to any target (`make ip` prints the address).

### Settings

`python/keiko.env` — read by `main.py` at startup; real environment variables override it. App Lab's `app.yaml`
cannot carry environment variables, so this file is the configuration. Keys: `KEIKO_UDP_HOST` (default `auto`),
`KEIKO_UDP_PORT` (5005), `KEIKO_NODE_ID` (0), `KEIKO_WAV` (path on the board, e.g. `/app/python/hydro.wav`),
`KEIKO_QUIET`.

App Lab runs the Python side in a Docker container on its own bridge network, so `127.0.0.1` in there is the
container, not the board. `KEIKO_UDP_HOST=auto` sends to the container's default gateway, which is the board's
Linux side — a pipeline running on the UNO Q listens on `0.0.0.0:5005` and gets every block. To receive on a
laptop instead, put the laptop's IP there (same network as the board), `make start`, then `make listen`
(`python/udp_listen.py`, prints packets/s, sample rate, and missing sequence numbers).

To stream to a laptop instead: `make retarget UDP_HOST=<laptop ip>` (same network as the board). It rewrites the
staged copy of `keiko.env` and pushes it; the node re-reads the file every second, so no restart — restarts re-flash
the MCU and have wedged the board's router. `make retarget UDP_HOST=auto` puts it back. `pipeline/`'s `make live`
does this for you and picks the right IP.

The Python side also runs outside App Lab (`python3 python/main.py` on the board) — it falls back to
speaking MessagePack-RPC to `/var/run/arduino-router.sock` directly, and `auto` then means `127.0.0.1`.

## UDP packet (proposal for all nodes)

One datagram per block, little-endian:

```
magic 4s "KEIK" | ver B 1 | node B | fmt B 0=int16 raw ADC | bits B | fs f Hz | seq I | t_ns Q host mono | n H | n×int16
```

## Limits and knobs

- **Sample rate is capped by the Bridge UART** (115200 baud ≈ 11 kB/s). 16-bit × 3333 Hz = 6.7 kB/s.
  Nyquist 1.67 kHz: fine for baleen calls and boat noise, not for dolphin clicks. For wideband use the
  ESP32-S3/nRF nodes, or pack 12-bit samples (1.5 B/sample → ~7 kHz).
- `SAMPLE_PERIOD_US` must be a multiple of 100 µs (Zephyr tick). The Python side measures the real rate
  from MCU timestamps, so an off-by-a-tick period only changes the number it prints.
- `mcu_drops` > 0 means the Bridge couldn't drain blocks fast enough (the sampler keeps its timing and
  overwrites). `missing` > 0 means the router or Python dropped a notification. If nothing arrives at all,
  halve `BLOCK` first.
- Block timestamps are MCU `micros()`; host arrival time goes in the UDP header. Good enough for
  single-node work; TDOA between nodes needs the shared clock the ESP32/nRF nodes use.

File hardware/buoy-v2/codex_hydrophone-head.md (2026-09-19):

1. **Blocker — the drop-line eye will print in mid-air and will be weak even if rescued with support.** At [lines 143–144](/Users/mallhw/.claude/jobs/c05f918e/tmp/HackMIT/hardware/buoy-v2/buoy_v2.scad:143), the eye is centered at `z=head_h=50`, radius 7 mm, so its lower arc begins at about `z=43`. The cage interior is empty through `z=47` ([line 127](/Users/mallhw/.claude/jobs/c05f918e/tmp/HackMIT/hardware/buoy-v2/buoy_v2.scad:127)); the first ~4 mm of the eye is an unsupported island. Its resulting STL is 57 mm high, confirming the 7 mm protrusion. Supports would be trapped in the cage. Also, the crossed zip-tie cut removes most of the eye’s central attachment.

   Fix: move the eye to the outer rim, with two 3–4 mm thick, gusseted legs that begin on the roof/wall, and put the loop center at `head_h + 7` so the entire loop is above the roof. Keep the 6 mm opening, but do not attach it through the cable/zip-tie boss.

2. **Blocker — the piezo is only balanced on three posts; it is not retained.** The posts run from `z≈11` to `z≈16` ([line 142](/Users/mallhw/.claude/jobs/c05f918e/tmp/HackMIT/hardware/buoy-v2/buoy_v2.scad:142)). A nominal 20 mm disc rests on their tops, with only `0.75 mm` radial overlap: post centers are at 11 mm radius, and their inner edges reach 9.25 mm while the disc edge is at 10 mm. There is no upper lip, clamp, or captured seat. A knock, inversion during handling, or tether jerk can lift/tilt the disc off the supports; its lead wires then become the retainer.

   Fix: add a `piezo_pack_d` parameter for the *sealed* assembly, not bare `piezo_d`; use at least 22–24 mm for a balloon/nail-polish envelope. Add three 1.2 mm radial retaining tabs, 0.4–0.6 mm above that assembly, or a removable printed retaining ring. Set post radius to `piezo_pack_d/2 + 1` and retain at least 0.75–1.0 mm radial overlap.

3. **Major — the sinker will rattle, contaminating the hydrophone and defeating TDOA quality.** The ring is an 8 mm-tall, 26 mm-ID pocket ([lines 38, 140](/Users/mallhw/.claude/jobs/c05f918e/tmp/HackMIT/hardware/buoy-v2/buoy_v2.scad:38)); ordinary washers/M8 hardware will have substantial radial clearance inside it, and no axial preload. Waves, line motion, and the printed cage will generate metal-on-PLA impacts immediately beside the piezo.

   Fix: set `sinker_d` to the actual stack OD plus only 0.5–0.8 mm, set `sinker_h` to the measured stack height plus 0.3–0.5 mm, and add a printed cap/retainer that also serves as the piezo seat. At minimum, wrap the washer stack tightly in electrical tape before insertion.

4. **Major — the cable is not strain-relieved.** The 5 mm hole is merely a pass-through ([line 135](/Users/mallhw/.claude/jobs/c05f918e/tmp/HackMIT/hardware/buoy-v2/buoy_v2.scad:135)). The purported zip-tie slots are two full 3 × 18 mm cuts rotated 90° from each other ([lines 136–137](/Users/mallhw/.claude/jobs/c05f918e/tmp/HackMIT/hardware/buoy-v2/buoy_v2.scad:136)). They form a cross through the cable hole rather than a pair of slots that traps a tie around the cable; they also turn the boss into thin fragments. Pull load transfers to the piezo solder joints.

   Fix: use two **parallel**, non-intersecting 3.5 × 7 mm slots centered roughly 5–6 mm to either side of the cable hole, then route one zip tie through them across a short heat-shrink-covered cable section. Add a 2–3 mm-high printed saddle below the hole and round/chamfer the hole entrance.

5. **Major — it floods adequately, but the acoustic arrangement is uncontrolled.** Water reaches the disc elevation: slots start at `z=3+8+4=15 mm` and end at 42 mm ([line 130](/Users/mallhw/.claude/jobs/c05f918e/tmp/HackMIT/hardware/buoy-v2/buoy_v2.scad:130)); the supported disc is at about `z=16 mm`. Six 6 mm-wide slots provide about `6×6×27 = 972 mm²` of opening, roughly 29% of the 123 mm inner circumference over that band. There is no sealed cage-air pocket.

   The problem is that a horizontal piezo has one face only 5 mm above a loose, reflective sinker and the other face open to the cage. That produces unit-to-unit-dependent loading and flexure, plus washer/cage vibration. An oil balloon also risks trapped air and a different acoustic impedance per build. It may detect sound, but two heads should not be assumed matched enough for reliable bearing estimates.

   Fix: make each head geometrically identical; immobilize the sinker; keep the disc’s water-facing surface open; and give its rear a defined backing—e.g. a shallow, sealed air/foam-backed chamber—or use a repeatable thin flexible coating rather than a variably oil-filled balloon. Mark a consistent disc orientation for both units.

6. **Minor — the top itself is a bridge-heavy print.** The cage cavity is cut up to `z=47 mm` ([line 127](/Users/mallhw/.claude/jobs/c05f918e/tmp/HackMIT/hardware/buoy-v2/buoy_v2.scad:127)); the 3 mm top/spokes begin over that void ([lines 131–133](/Users/mallhw/.claude/jobs/c05f918e/tmp/HackMIT/hardware/buoy-v2/buoy_v2.scad:131)). The spokes will bridge roughly 14 mm from wall toward the center. That is plausible on a tuned printer, but sag here further weakens the already compromised cable/eye region.

   Fix: either add three slender vertical ribs under the spoke roots, or print the top/eye as a separate cap and mechanically join it after installing the piezo and sinker.

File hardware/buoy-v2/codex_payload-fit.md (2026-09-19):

1. **Blocker — the modeled ESP32 does not fit in the stated position.**  
   Bore radius is `hull_r - wall = 50 - 2.4 = 47.6 mm` ([lines 12–14, 77]). The ESP32 preview occupies `x = ±10 mm`, `y = 22.9…48.9 mm` ([line 153]). At `x = ±10`, the circular bore permits only `|y| ≤ √(47.6²−10²) = 46.5 mm`; the board penetrates the wall by **2.4 mm**. It also overlaps the “stop” geometry at `x = -11.2…-8.8 mm`, `y = 20.5…32.5 mm` ([line 91]).  
   Fix: place the board fully outboard of the bank ribs, with `y = 16.5…42.5 mm` (center `y = 29.5 mm`) and move the stop accordingly. This leaves ~4 mm radial clearance at the board’s outer corners. Do this before printing.

2. **Blocker — the ESP32 antenna is only about 5.6 mm above the calculated waterline, and its orientation is not constrained.**  
   The model places the ESP32 from `z = 3` to `73 mm` ([line 153]). Its own displacement calculation gives a **67.4 mm** draft: `529 g / (π·50²/1000) = 67.4 mm` ([lines 157–163]). If the antenna end is at the intended top of the vertical board, it is only `73 − 67.4 = 5.6 mm` above still water. If assembled upside-down, it is submerged. A small heel, wake, or extra water/payload load puts the antenna at the waterline; 2.4 GHz through PLA is workable, but water beside the antenna is not.  
   Fix: define an antenna-up orientation mechanically and raise its end to at least **95 mm from the hull floor**—target **25–30 mm above the 67 mm waterline**. Mount the ESP32 vertically on a printed/foam-board standoff or strap it higher, and keep the antenna facing the upper dry wall, not the bank.

3. **Major — the power-bank rib slot has exactly zero assembly clearance.**  
   The bank is modeled as exactly `25 mm` thick ([line 8]), while the inner rib faces are exactly `y = −12.5` and `+12.5 mm` ([lines 87–89]): a **25.0 mm slot**. A real “25 mm” power bank plus PLA elephant-foot, rib roughness, label seams, and dimensional variation will not reliably slide in at 3 AM. The ribs are also only `55 mm` tall, while the bank is `100 mm` tall ([lines 8, 87]), so they constrain only its lower half.  
   Fix: make `bank_slot = 28 mm`; place rib inner faces at `±14 mm` (e.g. parameterize the translation from `bank_slot/2`). Add a removable top retaining strap across the bank—rubber band/zip tie through two printed slots is sufficient.

4. **Major — no USB-C route has been dimensioned or proven to bend.**  
   The bank top is at `z = 103 mm`; the ESP top is `z = 73 mm`, so their ports may be **30 mm apart vertically** if both are placed at their upper ends. There is 29 mm to the nominal hull rim above the bank, but no port locations, plug envelope, channel, or specified bend radius in the design. A typical 3–5 mm USB-C lead needs roughly **12–20+ mm** static bend radius; a straight plug also consumes ~8–12 mm before the bend. This might work with a thin right-angle cable, but it is not an assemblable design as drawn—especially after moving the ESP to a non-colliding location.  
   Fix: require a **right-angle, ≤4 mm OD USB-C cable** and reserve a **30 mm-high × 30 mm-wide** routing void. Orient the bank and ESP ports toward that void, preferably vertically aligned, and keep the cable’s first bend at **R ≥ 12 mm**. Test-fit the actual cable before committing both hulls.

5. **Major — the lid gland is not compatible with closing a threaded lid after the ESP connection is made.**  
   The lid needs `turns = 2.4`, i.e. **864° of rotation**, to close ([lines 18–20, 104]). The cable hole is only `6 mm` ([line 29, 109]); a terminated connector cannot pass through it. If the hydrophone lead is already attached to the ESP, screwing the lid on twists that lead by 2.4 turns; if it is attached to the hydrophone outside, it twists the 1–2 m drop cable. The 13 mm internal boss ([lines 30, 111–113]) provides no strain-relief or rotation isolation.  
   Fix: close the lid with the gland lead **unterminated**, then terminate/connect it inside; or replace the threaded closure with 6–8 M3 insert/screw locations so the lid closes without rotation. If keeping threads, add a detachable inline connector inside the buoy and leave at least 150 mm of service loop.

6. **Major — the ESP-to-gland run is not physically allocated.**  
   The gland center is at radius `lid_bore_r − 14 = 36.35 mm` ([lines 46, 109, 112]); after the 45° rotation it is approximately `(25.7, 25.7)`. Its 8 mm boss intrudes downward from the lid ([lines 30, 111–113]). The current ESP position is already invalid, and after moving it to the valid outboard location, the hydrophone wire must run roughly 55–65 mm upward plus laterally around the bank, with no channel or service-loop provision. It can be made to fit, but not reliably without pinching against the bank/ribs when closing.  
   Fix: add a **10 mm-wide, 65 mm-high open cable chase** from the board’s connector area to the gland-side wall, and reserve **100–120 mm** of flexible lead as a loop below the boss. Do not route it between the bank and a rib.

7. **Minor — the claimed 111 mm lid OD is not the modeled lid OD.**  
   `lid_od = 2 × (50 + 1.5 + 0.35 + 2.4) = 108.5 mm` ([lines 44–48]), not 111 mm. This does not stop the payload fitting, but it changes grip/overhang expectations and should be corrected in the build notes before the team judges a printed part against the stated dimensions.

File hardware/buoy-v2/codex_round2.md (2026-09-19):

1. **Lid thread wrong-handed after flip — NOT FIXED.** Hull uses `hand=1` at [line 86](./buoy_v2.scad:86); lid uses `hand=-1` at [line 116](./buoy_v2.scad:116). A 180° rotation about X is a proper rotation, not a mirror: it reverses both axial direction and angular coordinate, preserving screw handedness. The lid’s resulting global helix is still opposite the hull’s, so the threads do not mate.

2. **Gasket groove through the 2.4 mm neck wall — FIXED.** The neck cavity is radius `65 - 2 - 2.4 = 60.6 mm` ([line 91](./buoy_v2.scad:91)). The groove runs from radius `61.8` to `63.8 mm` ([lines 93–95](./buoy_v2.scad:93)), leaving 1.2 mm both inside and outside. It is at z=99.1–100 mm, inside the land.

3. **Piezo posts and head eye were floating islands — FIXED geometrically.** Posts overlap the sinker ring: post centers are r=13 mm, with radius 2.25 mm, while the ring is r=12.75–14.35 mm ([lines 137, 156, 159](./buoy_v2.scad:137)). They also have radial ribs ([line 160](./buoy_v2.scad:160)). The eye plate overlaps the roof by 0.5 mm at z≈55.5–56 mm ([lines 165–168](./buoy_v2.scad:165)). It introduces a new blocking interference below.

4. **60 mm lid-panel bridge — FIXED.** This is a 1.6 mm-wide, 0.6 mm-deep engraved ring, not a recessed panel ([lines 37, 120–124](./buoy_v2.scad:37)).

5. **Upper mooring lug unprintable / capsize lever — FIXED.** Only the two bottom `eye_lug(0, …)` calls remain ([line 87](./buoy_v2.scad:87)); no upper lug is present.

6. **Bottom-lug holes cut into cavity — FIXED.** Lug centers are at ±67 mm ([line 73](./buoy_v2.scad:73)), while the hull outer radius is 65 mm. Hole centers are ±70.15 mm and their inner edges are ±66.15 mm ([line 76](./buoy_v2.scad:76)), at least 1.15 mm outside the hull shell.

7. **Negative GM with vertical power bank — NOT FIXED.** The preview places the bank as `cube([bank_l, bank_t, bank_w])` ([line 177](./buoy_v2.scad:177)): 100 × 25 mm footprint and **65 mm vertical height**. It is on its side, not flat. The stability formula nevertheless assigns its CG using `bank_t/2 = 12.5 mm` ([line 189](./buoy_v2.scad:189)), rather than the modeled `bank_w/2 = 32.5 mm`.

8. **ESP32 antenna too close to waterline — FIXED, under the stated mass model.** ESP top is z=72.4 mm ([line 178](./buoy_v2.scad:178)). Calculated draft is 49.65 mm, so the quoted antenna clearance is 22.75 mm.

9. **Bank slot zero clearance — FIXED.** `slot=27 mm` ([line 82](./buoy_v2.scad:82)); rail inner faces are y=±13.5 mm ([line 101](./buoy_v2.scad:101)). A 25 mm bank spans y=±12.5 mm: 1.0 mm clearance per side.

10. **6 mm cable hole unsealable — FIXED geometrically, with a parameter mismatch.** The hole is 3.5 mm and has an 8 mm × 10 mm internal boss ([lines 38–39, 126, 129](./buoy_v2.scad:38)). But `cable_d` is also 3.5 mm ([line 49](./buoy_v2.scad:49)), so the comment “cable OD + 0.5” is false for the modeled cable.

11. **Cage slots clipped post tips — FIXED.** Posts end at z=16 mm ([lines 138, 159](./buoy_v2.scad:138)); slots begin at z=16 mm and are 30° off the posts ([lines 147–149](./buoy_v2.scad:147)). At r=13 mm their nearest lateral distance is 6.5 mm, exceeding the 3 mm slot half-width.

12. **Zip-tie slots crossed — FIXED.** The two slots are parallel, x=−7.75…−4.25 and +4.25…+7.75 mm ([line 153](./buoy_v2.scad:153)). The eye plate now blocks the left one.

New findings:

1. **BLOCKER — the head eye plate blocks the cable bore and left zip slot.** The cable bore is cut from the main head body before the eye plate is added ([lines 142–154](./buoy_v2.scad:142), [165–168](./buoy_v2.scad:165)). The plate occupies x=−16…0, y=−2…2, z≈55.5…72 mm; the cable bore occupies x/y within r=1.75 at z=52…62 mm. Thus the plate closes roughly the negative-X half of the cable passage. It also fills the left zip slot at x=−7.75…−4.25, z=55.5…57 mm. Cut the cable bore and both zip slots after unioning the eye plate, or move the eye plate clear of both features.

2. **BLOCKER — the printed “trapezoid thread” has effectively no axial tooth width.** `helix_thread()` extrudes a radial/tangential polygon while twisting it ([lines 62–70](./buoy_v2.scad:62)). Its stated `base=2.6 mm` is tangential, not axial. At r≈65 mm and 5 mm pitch, that corresponds to an axial width of only `2.6 × 5 / (2π × 65) = 0.032 mm`, not 2.6 mm. This produces knife-thin helical sheets spaced 5 mm apart, not a 45° trapezoidal screw thread. Use a true axial thread profile / a proven thread library, then generate its mating subtraction from the same profile.

3. **MAJOR — claimed 0.45 mm clearance is radially adequate, but the thread remains non-mating.** Hull crest is r=66.2 mm ([lines 28–31, 86](./buoy_v2.scad:28)); lid groove reaches r=66.65 mm (`65 + 1.2 + 0.45`, [line 116](./buoy_v2.scad:116)), giving 0.45 mm radial clearance. Axially, hull spans z=87.5–98.5 mm ([lines 59, 86](./buoy_v2.scad:59)); flipped lid cut spans z=86.0–98.5 mm, so it covers the hull length. Neither fact repairs the handedness failure. Set the lid to `hand=1` if retaining the current flipped assembly convention, after replacing the thread construction.

4. **MAJOR — both “lead-in chamfers” miss the mating thread start.** Hull thread is z=87.5–98.5 mm; its chamfer is z=99–100 mm ([lines 86, 97](./buoy_v2.scad:86)), 0.5 mm above the thread end. The flipped lid mouth chamfer is global z≈84–85 mm ([lines 114–118](./buoy_v2.scad:114)), 2.5–3.5 mm below the hull thread start. Neither provides an entry ramp into the first engaged thread. Put a lead-in on the hull’s upper thread end and/or the lid’s actual entering groove end, based on a corrected mating thread.

5. **MAJOR — ESP pocket ribs intentionally intersect the modeled board.** The ESP is x=−13…13 mm ([line 178](./buoy_v2.scad:178)); ribs occupy x=13.3…15.7 and −15.7…−13.3 mm ([line 104](./buoy_v2.scad:104)). Each rib cuts 0.3 mm into the board envelope through z=2.4–14.4 mm. Move rib inner faces to ±(13 + clearance), e.g. ±13.8 mm for 0.8 mm clearance, and preserve their gap from the positive bank rail (currently only 2.8 mm).

6. **MAJOR — head retaining tabs do not retain the stated 8 mm piezo pack.** The sinker pocket is z=3–11 mm ([line 156](./buoy_v2.scad:156)); an 8 mm pack placed on it occupies z=11–19 mm. Tab underside begins at z=24.6 mm ([lines 138–139, 162](./buoy_v2.scad:162)), leaving a 5.6 mm gap. Lower the tab underside to approximately z=19–19.5 mm, allowing only intended insertion clearance.

7. **MAJOR — reported stability is materially overstated.** From the code: hull mass ≈172.9 g, lid ≈84.1 g, total ≈659.0 g; draft ≈49.65 mm; KM≈46.10 mm; reported KG≈35.53 mm and GM≈10.57 mm ([lines 182–190](./buoy_v2.scad:182)). With the bank in its actual modeled orientation, bank CG is 34.9 rather than 14.9 mm. Corrected KG is ≈42.51 mm and GM≈3.59 mm. That is positive only marginally, before uncertainty in shell mass, lugs, rails, retained water, and actual tether force. Either model the bank flat as `[bank_l, bank_w, bank_t]` and redesign the layout, or use `bank_w/2` in KG and state the reduced GM.

8. **MINOR — the neck land and gasket placement themselves are coherent.** The main cavity ends at z≈84.01 mm, the land cavity starts at z=84 mm, and the thread starts at 87.5 mm ([lines 59, 90–91](./buoy_v2.scad:59)). The 4.4 mm land supports the thread; the gasket is above the thread end with 1.2 mm remaining wall. No overlap defect found there.

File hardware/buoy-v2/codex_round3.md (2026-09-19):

## (a) Thread sweep

Not correct as stated.

- The axial base is 2.6 mm: profile endpoints are at ±1.3 mm ([line 66](file:///Users/mallhw/.claude/jobs/c05f918e/tmp/HackMIT/hardware/buoy-v2/buoy_v2.scad:66), [line 69](file:///Users/mallhw/.claude/jobs/c05f918e/tmp/HackMIT/hardware/buoy-v2/buoy_v2.scad:69)).
- The exposed outer radius is 65 → 66.2 mm, so the intended exposed radial height is 1.2 mm ([lines 64–69](file:///Users/mallhw/.claude/jobs/c05f918e/tmp/HackMIT/hardware/buoy-v2/buoy_v2.scad:64)).
- But the actual closed polygon root is at `r - 0.3 = 64.7`, making each flank span 1.5 mm radially over 1.2 mm axially. That is a 51.3° flank, not 45°. The 0.3 mm embedding may be intentional for unioning to the shell, but then it must not be counted as part of the 45° tooth profile.

Pitch is 5 mm and 2.2 turns gives 11 mm helical rise ([lines 28–31](file:///Users/mallhw/.claude/jobs/c05f918e/tmp/HackMIT/hardware/buoy-v2/buoy_v2.scad:28)); the 2.6 mm axial tooth width leaves 2.4 mm between same-phase turns. The 106 hull segments (`ceil(2.2×48)`) overlap at their common slice, so the union should be closed/watertight and does not self-intersect from turn-to-turn ([lines 74–80](file:///Users/mallhw/.claude/jobs/c05f918e/tmp/HackMIT/hardware/buoy-v2/buoy_v2.scad:74)).

However, the ramp does **not** shrink the tooth to zero. At `hscale=0`, its radial span remains 64.7–65.0 mm because only `hh` scales; the root offset `-0.3` remains ([lines 64–69](file:///Users/mallhw/.claude/jobs/c05f918e/tmp/HackMIT/hardware/buoy-v2/buoy_v2.scad:64)). It remains manifold, but has a finite radial stub at each end.

## (b) Lid groove and handedness

The hand is now right. Flipping around X negates both helix angle and axial direction, so `hand=1` in the unflipped lid becomes the same physical hand as the hull after the assembly transform ([lines 121–128](file:///Users/mallhw/.claude/jobs/c05f918e/tmp/HackMIT/hardware/buoy-v2/buoy_v2.scad:121), [line 188](file:///Users/mallhw/.claude/jobs/c05f918e/tmp/HackMIT/hardware/buoy-v2/buoy_v2.scad:188)).

At the seated height:

- Hull thread envelope: nominal centerline z = 87.5–98.5; including the 1.3 mm axial half-base, z = **86.2–99.8 mm** ([lines 59, 66–69, 98](file:///Users/mallhw/.claude/jobs/c05f918e/tmp/HackMIT/hardware/buoy-v2/buoy_v2.scad:59)).
- Lid-cut envelope after flip: z = **84.45–100.95 mm**, using lid top 3.2, offset 0.8, 2.6 turns, and expanded profile half-base 1.75 mm ([lines 35, 66–69, 126–128, 188](file:///Users/mallhw/.claude/jobs/c05f918e/tmp/HackMIT/hardware/buoy-v2/buoy_v2.scad:35)).
- Radially, hull is 64.7–66.2 mm; the groove cut is 64.25–66.65 mm. It contains the tooth with 0.45 mm clearance.

This is conditional on the lid being rotated to its thread engagement phase. At the preview’s arbitrary zero rotation, the tracks are phase-shifted by 122.4°. A rotation of 122.4° aligns them; actual screw engagement should establish that orientation.

## (c) Lead-in

The ramp itself is not a lead-in because it leaves the finite 0.3 mm root stub noted above. The hull rim chamfer does intersect the high end of the thread: it runs z = 99–100 mm while the tooth reaches z = 99.8 mm ([line 109](file:///Users/mallhw/.claude/jobs/c05f918e/tmp/HackMIT/hardware/buoy-v2/buoy_v2.scad:109)). The lid-mouth chamfer is also at the engagement end after flipping ([line 130](file:///Users/mallhw/.claude/jobs/c05f918e/tmp/HackMIT/hardware/buoy-v2/buoy_v2.scad:130)). But neither fixes the finite ramp stub at the other end.

## (d) Bank / rails

The bank is flat: 100 × 65 × 25 mm at z = 2.4–27.4 mm ([lines 15, 190](file:///Users/mallhw/.claude/jobs/c05f918e/tmp/HackMIT/hardware/buoy-v2/buoy_v2.scad:15)).

Rails occupy y = −35.9…−33.5 and +33.5…+35.9 mm, leaving a 67 mm inside gap ([lines 94, 112–113](file:///Users/mallhw/.claude/jobs/c05f918e/tmp/HackMIT/hardware/buoy-v2/buoy_v2.scad:94)). The 65 mm bank has 1.0 mm side clearance to each rail.

At bank corners, radius is `sqrt(50² + 32.5²) = 59.63 mm`; inner bore radius is 63 mm. Corner-to-wall clearance is **3.37 mm**.

## (e) ESP board / ribs / draft

Board envelope is x = ±13, y = 26.7–46.7, z = 2.4–72.4 mm ([lines 16, 115, 191](file:///Users/mallhw/.claude/jobs/c05f918e/tmp/HackMIT/hardware/buoy-v2/buoy_v2.scad:16)). Its outer upper corners are at radius `sqrt(13² + 46.7²) = 48.48 mm`, leaving **14.52 mm** to the 63 mm bore.

Ribs are x = ±13.8…16.2, so they clear the board sides by **0.8 mm** ([line 116](file:///Users/mallhw/.claude/jobs/c05f918e/tmp/HackMIT/hardware/buoy-v2/buoy_v2.scad:116)). Their outer corner is radius 57.05 mm, leaving **5.95 mm** to the bore.

The board nevertheless intersects the bank: the board occupies y = 26.7–46.7 while the bank occupies y = −32.5…32.5, creating a **5.8 mm y-overlap** across x = ±13 and z = 2.4–27.4.

Recomputed draft is **49.65 mm**; antenna top at z = 72.4 is **22.75 mm above water**.

## (f) Head

The post tops are z = 16; an 8 mm pack rests from z = 16 to 24 ([lines 46, 149–151](file:///Users/mallhw/.claude/jobs/c05f918e/tmp/HackMIT/hardware/buoy-v2/buoy_v2.scad:46)). Tab underside is z = 24.6, thus 0.6 mm vertically clear. But the tabs’ nearest radial edge is 16.9 mm, versus the pack radius 12 mm: a **4.9 mm radial gap**. They do not retain the pack ([line 169](file:///Users/mallhw/.claude/jobs/c05f918e/tmp/HackMIT/hardware/buoy-v2/buoy_v2.scad:169)).

Cable bore radius is 1.75 mm. Zip slots are x = −3.5…3.5 and y = ±4.25…7.75:

- Cable-to-slot edge clearance: **2.5 mm**.
- Slot-to-slot edge clearance: **8.5 mm**.
- Eye plate reaches x = −6 mm; nearest slot edge is x = −3.5, giving **2.5 mm** clearance. Cable-bore-to-plate clearance is **4.25 mm**.

Those are cut after the eye-plate union ([lines 154, 171–181](file:///Users/mallhw/.claude/jobs/c05f918e/tmp/HackMIT/hardware/buoy-v2/buoy_v2.scad:154)), so Boolean order is safe.

The six radial side slots end at z = 33.15 mm; the inner cone begins at z = 35.15 mm, leaving **2.0 mm** of roof clearance ([lines 152, 160–161](file:///Users/mallhw/.claude/jobs/c05f918e/tmp/HackMIT/hardware/buoy-v2/buoy_v2.scad:152)).

The two nominal zip slots are blind pockets, not through-slots. Their floor is z = 52.99 mm. The cone’s inside surface beneath them is z ≈ 50.5 mm at the nearest point and lower elsewhere, leaving 2.5–6.7 mm of material. A zip tie cannot pass through them.

## (g) Stability

The flat-bank CG term is correctly `bank_t/2`, placing its CG at z = 14.9 mm ([line 202](file:///Users/mallhw/.claude/jobs/c05f918e/tmp/HackMIT/hardware/buoy-v2/buoy_v2.scad:202)).

Using the file’s mass model:

| Quantity | Result |
|---|---:|
| hull mass | 172.92 g |
| lid mass | 84.10 g |
| total mass | 659.02 g |
| draft | 49.65 mm |
| KB | 24.83 mm |
| BM | 21.27 mm |
| KM | 46.10 mm |
| KG | 35.53 mm |
| GM | **10.57 mm** |

## New defects

1. **Blocker — ESP and bank occupy the same volume.**  
   Move the ESP outward until its inner y edge exceeds 32.5 mm, or relocate/rotate it. Preserve wall clearance after moving it.

2. **Major — “retaining” tabs do not reach the 24 mm pack.**  
   Move their inner edge inward to approximately r ≤ 11.5 mm, or replace them with tabs attached to the post/ring geometry above the pack perimeter.

3. **Major — zip slots are blind and cannot accept a zip tie.**  
   Extend the cuts down through the roof into the head interior, with a defined roof/slot reinforcement strategy.

4. **Major — thread flanks are not 45° in the generated solid.**  
   Keep the 0.3 mm shell-overlap as a separate root/union feature, or make the profile’s radial and axial flank runs both 1.2 mm.

5. **Minor — height ramp never reaches zero tooth height.**  
   Scale/root-collapse the entire profile, or explicitly taper both root and crest to a common radius at each end.

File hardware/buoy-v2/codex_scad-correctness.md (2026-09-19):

1. **Blocker — the lid’s internal thread is opposite-handed after the lid is flipped.** `helix_ridge()` twists `-360*turns` ([lines 51–55](/Users/mallhw/.claude/jobs/c05f918e/tmp/HackMIT/hardware/buoy-v2/buoy_v2.scad:51)); both hull and lid call it with that hand ([72](/Users/mallhw/.claude/jobs/c05f918e/tmp/HackMIT/hardware/buoy-v2/buoy_v2.scad:72), [104](/Users/mallhw/.claude/jobs/c05f918e/tmp/HackMIT/hardware/buoy-v2/buoy_v2.scad:104)). But `assembly()` rotates the lid 180° about X ([150](/Users/mallhw/.claude/jobs/c05f918e/tmp/HackMIT/hardware/buoy-v2/buoy_v2.scad:150)), reversing its axial direction while preserving its angular direction. The physical lid groove therefore rises at `+360°/5 mm`; the hull ridge rises at `-360°/5 mm`. It cannot screw on. Add a handedness argument and use the opposite twist for the lid groove, e.g. `helix_ridge(..., handed=1)` for the hull and `handed=-1` for the lid.

2. **Blocker — the neck gasket groove cuts completely through the 2.4 mm wall and opens the hull.** At [80–84](/Users/mallhw/.claude/jobs/c05f918e/tmp/HackMIT/hardware/buoy-v2/buoy_v2.scad:80), the groove spans radii `47.5–50.1 mm`: `50 - 2.4/2 ± 2.6/2`. The cavity extends to `47.6 mm` ([78](/Users/mallhw/.claude/jobs/c05f918e/tmp/HackMIT/hardware/buoy-v2/buoy_v2.scad:78)), and the exterior is at `50 mm`; the cutter overlaps both. This creates an annular water path at `z=130.6–132 mm`. A 2.6 mm radial groove cannot fit in a 2.4 mm rim. At minimum, change to `groove_w = 1.4` (leaves 0.5 mm material on each side); preferably move the groove into the lid’s 3.9 mm radial sealing land and retain an uncut hull rim.

3. **Blocker — all three piezo retaining posts are disconnected floating solids, so they will print as islands.** The sinker ring ends at `z=10.99` ([140](/Users/mallhw/.claude/jobs/c05f918e/tmp/HackMIT/hardware/buoy-v2/buoy_v2.scad:140)); the posts begin at exactly `z=10.99` ([142](/Users/mallhw/.claude/jobs/c05f918e/tmp/HackMIT/hardware/buoy-v2/buoy_v2.scad:142)). More importantly, the ring occupies `r=13–14.6 mm`, while each post at radius 11 mm extends only to `r=12.75 mm`: a 0.25 mm radial gap. The cavity has already removed everything inside `r=19.6 mm` above `z=3` ([127](/Users/mallhw/.claude/jobs/c05f918e/tmp/HackMIT/hardware/buoy-v2/buoy_v2.scad:127)). Add real, overlapping bridges from the ring to each post—at least `0.4 mm` overlap—or redesign the ring with three inward tabs beneath the posts.

4. **Major — the lid groove’s axial offset leaves the bottom of the hull ridge ungrooved even aside from handedness.** Hull ridge: `z=116+2=118` through `130 mm` ([72](/Users/mallhw/.claude/jobs/c05f918e/tmp/HackMIT/hardware/buoy-v2/buoy_v2.scad:72)). In the assembled, inverted lid, the groove from [104](/Users/mallhw/.claude/jobs/c05f918e/tmp/HackMIT/hardware/buoy-v2/buoy_v2.scad:104) occupies `118.35–131.35 mm`: its `2-clr` start uses radial clearance as an axial shift. Thus the ridge’s lower 0.35 mm is not relieved. Once the lid hand is corrected, replace `translate([0,0,2 - clr])` with `translate([0,0,2])`; this gives a physical groove range `118–131 mm`. Keep `clr` only in diameters/radii.

5. **Major — the shown assembly is unseated by 1 mm, so it does not validate gasket compression or thread engagement.** The transform on [150](/Users/mallhw/.claude/jobs/c05f918e/tmp/HackMIT/hardware/buoy-v2/buoy_v2.scad:150) simplifies to an inverted lid whose underside is at `z=133 mm`; the hull rim is at `z=132 mm`. The displayed 1 mm air gap can hide an interference or falsely imply clearance. Replace the expression with the direct seated transform:
   ```scad
   translate([0,0,hull_h + lid_top_t])
     rotate([180,0,0]) lid_body();
   ```
   This puts the lid underside at `z=hull_h`. Remove the no-op `mirror([0,0,0])`.

6. **Major — the ESP32 “stop” intersects the displayed ESP32 rather than stopping it, and it is not tied to the bank-rib geometry.** The positive bank rib ends at `y=14.9 mm` ([89](/Users/mallhw/.claude/jobs/c05f918e/tmp/HackMIT/hardware/buoy-v2/buoy_v2.scad:89)). The stop begins at `y=20.5 mm` and occupies `x=-11.2..-8.8 mm` ([91](/Users/mallhw/.claude/jobs/c05f918e/tmp/HackMIT/hardware/buoy-v2/buoy_v2.scad:91)). The assembled ESP model is `x=-10..10`, `y=22.9..48.9` ([153](/Users/mallhw/.claude/jobs/c05f918e/tmp/HackMIT/hardware/buoy-v2/buoy_v2.scad:153)), so the rib penetrates it by 1.2 mm in X over most of its height. Move the stop outside the ESP envelope, e.g. to `x=-esp_h/2 - 1.2 .. -esp_h/2`, or make it a transverse end-stop at the actual board bottom.

7. **Major — the power-bank model does not fit the hull ID, and the ribs do not have clearance.** Hull ID is `2*(50-2.4)=95.2 mm`; the assembly’s bank is 100 mm wide ([152](/Users/mallhw/.claude/jobs/c05f918e/tmp/HackMIT/hardware/buoy-v2/buoy_v2.scad:152)), so it penetrates the wall by 2.4 mm on both sides. The bank-rib inside faces are exactly 25 mm apart, equal to `bank_t`, with zero assembly tolerance. This invalidates the internal layout. Either orient the real bank so its 65 mm dimension spans the hull, or set the actual packed envelope and make rib inside-face spacing `bank_t + 1–1.5 mm`.

8. **Major — the vertical cage slots clip the last ~1 mm of every piezo post.** Posts run `z=10.99–15.99` ([142](/Users/mallhw/.claude/jobs/c05f918e/tmp/HackMIT/hardware/buoy-v2/buoy_v2.scad:142)); slots begin at `z=15` ([130](/Users/mallhw/.claude/jobs/c05f918e/tmp/HackMIT/hardware/buoy-v2/buoy_v2.scad:130)). Slot angles include `0°, 120°, 240°`, exactly the post angles, so each post’s upper ~0.99 mm is cut. The slots do **not** cut the sinker ring (`ring z=2.99–10.99`) or top spokes (`slots end z=42`, top openings start `46.99`), but they do weaken/delete the post tips. Start slots at `head_floor + sinker_h + 5` (16 mm) or rotate slot angles by 30°.

I could not run the requested Manifold check because this environment’s `openscad` binary fails at startup with a Qt CPU-feature error; the findings above are from the evaluated source geometry.

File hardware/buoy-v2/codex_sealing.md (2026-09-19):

1. **Blocker — the two bottom “solid” bridle lugs cut into the flooded cavity.** In `eye_lug()` the hole’s center is at radial position `hull_r - 2 + lug_r*0.35 = 51.15 mm`; its 8 mm hole reaches inward to `47.15 mm` ([lines 57–62](</Users/mallhw/.claude/jobs/c05f918e/tmp/HackMIT/hardware/buoy-v2/buoy_v2.scad:57>)). The cavity extends to `hull_r - wall = 47.6 mm` from `z=3 mm` upward ([line 78](</Users/mallhw/.claude/jobs/c05f918e/tmp/HackMIT/hardware/buoy-v2/buoy_v2.scad:78>)). Therefore each bottom lug hole intersects the cavity by about 0.45 mm over `z=3–6 mm`. They will be submerged at the estimated 67 mm draft, so these are direct hull holes, not solid loops. The top lug has the same defect, albeit normally above the waterline.

   Fix: move every lug outward. Change the translate in `eye_lug()` from `hull_r - 2` to at least `hull_r + 2`; then the hole’s inner edge is about 51.15 mm, leaving ~1.15 mm outside the 50 mm hull OD while the lug body still overlaps the hull. Re-export and inspect the cross-section before printing.

2. **Blocker — the 6 mm cable hole has no realizable seal with the stated hardware.** `gland_hole = 6` ([line 29](</Users/mallhw/.claude/jobs/c05f918e/tmp/HackMIT/hardware/buoy-v2/buoy_v2.scad:29>)) is a large annulus around a typical hydrophone cable. The internal 13 mm boss ([lines 111–113](</Users/mallhw/.claude/jobs/c05f918e/tmp/HackMIT/hardware/buoy-v2/buoy_v2.scad:111>)) guides it but does not compress it. Hot glue is unavailable, and an internal heat-shrink sleeve only works if it fits over the 13 mm boss, shrinks tightly onto the actual cable, and is installed before termination. The cable runs down into the river, so this point stays wet and can wick water.

   Fix: make `gland_hole` cable-OD + 0.5 mm—likely `3.0–3.5 mm`, not 6 mm. Add an **external** cylindrical boss, e.g. OD 10–12 mm and 6 mm tall, and use correctly sized adhesive-lined marine heat shrink over that boss and cable. Slide the heat shrink on before attaching/soldering the hydrophone. As an immediate backup, wrap the completed external penetration and lid seam with waterproof duct tape.

3. **Major — the thread is a water path; the rim gasket is entirely responsible for stopping it, but the specified gasket is indeterminate.** The single-start 3 mm round thread (`ridge_d=3`, `pitch=5`, `turns=2.4`, [lines 17–20](</Users/mallhw/.claude/jobs/c05f918e/tmp/HackMIT/hardware/buoy-v2/buoy_v2.scad:17>)) has 0.35 mm radial clearance ([line 17](</Users/mallhw/.claude/jobs/c05f918e/tmp/HackMIT/hardware/buoy-v2/buoy_v2.scad:17>)); it is not a seal. Water can follow its continuous ~12 mm axial helical gap to the rim. The groove is only `2.6 × 1.4 mm` ([lines 22–23](</Users/mallhw/.claude/jobs/c05f918e/tmp/HackMIT/hardware/buoy-v2/buoy_v2.scad:22>)), but “foam or rubber band” does not define a continuous, adequately proud compression gasket. Open-cell foam can wick; a rubber-band joint leaves a leak point; a ~1.4 mm band seated in a 1.4 mm-deep groove has essentially no designed squeeze.

   Fix: use one continuous 1.8–2.0 mm closed-cell/rubber cord gasket and set `groove_d = 0.9–1.1` and `groove_w = 3.0–3.2`, giving roughly 0.7–1.1 mm proud material before closure. If no suitable gasket can be sourced, treat the threaded lid as non-watertight and tape the entire lid/hull seam after tightening. Verify by submerging the sealed empty hull for at least the intended deployment duration.

4. **Major — the cable opening lies inside the solar recess, leaving only 1.6 mm of top material at the most stressed sealing point.** The hole center is at radius `lid_bore_r - 14 = 36.35 mm` ([line 109](</Users/mallhw/.claude/jobs/c05f918e/tmp/HackMIT/hardware/buoy-v2/buoy_v2.scad:109>)). At 45°, its coordinates are about `(25.7, 25.7)`, inside the 60 × 60 mm recess spanning ±30 mm ([line 107](</Users/mallhw/.claude/jobs/c05f918e/tmp/HackMIT/hardware/buoy-v2/buoy_v2.scad:107>)). Thus the 3.2 mm lid top ([line 26](</Users/mallhw/.claude/jobs/c05f918e/tmp/HackMIT/hardware/buoy-v2/buoy_v2.scad:26>)) is locally reduced to 1.6 mm around the cable port, contrary to the comment that it clears the recess.

   Fix: exclude a 20–24 mm circular pad around the cable port from the solar-recess subtraction, retaining the full `lid_top_t = 3.2` there; pair that pad with the external heat-shrink boss above.

5. **Minor, but verify before river use — “2.4 mm walls, 3 perimeters at 0.42 mm” is arithmetically inconsistent.** The comment at [line 13](</Users/mallhw/.claude/jobs/c05f918e/tmp/HackMIT/hardware/buoy-v2/buoy_v2.scad:13>) claims three 0.42 mm perimeters make a solid 2.4 mm wall. They total only 1.26 mm. Depending on slicer gap-fill behavior, the remaining width may be filled, may be a sparse/weak region, or the printed wall may be much thinner than intended. At only ~0.66 kPa hydrostatic pressure at 67 mm draft, sound PLA should not seep appreciably for a few hours, but under-extrusion, seams, and unfilled wall gaps can.

   Fix: explicitly configure a watertight shell: five 0.48 mm lines or six 0.42 mm lines for the modeled 2.4 mm wall, zero sparse infill in shell regions, and align/check the Z seam. Fill the finished hull with water and leave it on dry paper for the planned deployment duration before loading electronics.

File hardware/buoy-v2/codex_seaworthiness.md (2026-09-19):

1. **Blocker — the upright configuration has negative metacentric stability and will not self-right.**  
   Lines 156–163 estimate \(m=529\) g and draft \(T=67.3\) mm. For a 100 mm circular waterplane:

   \[
   A=\pi(50)^2=7{,}854\ {\rm mm^2}
   \]
   \[
   I=\frac{\pi r^4}{4}=4.91\times10^6\ {\rm mm^4}
   \]
   \[
   KB=T/2=33.7\ {\rm mm},\quad BM=I/\nabla=4.91e6/(529000)=9.3\ {\rm mm}
   \]

   So \(KM=43.0\) mm above the hull bottom. The code places the 230 g bank vertically from \(z=3\) to 103 mm (lines 152, 8), so its CG alone is at 53 mm. A reasonable mass moment from the code’s own parts is: hull ≈172 g at 66 mm, lid ≈55 g at ~130 mm, bank 230 g at 53 mm, ESP 12 g at 38 mm, and 60 g miscellaneous at ~65 mm. That gives:

   \[
   KG \approx 66.5\ {\rm mm};\quad GM=KM-KG\approx -23.5\ {\rm mm}
   \]

   It is statically unstable: a small heel will tend to increase, not recover. The vertical bank is the dominant practical issue, but the tall PLA shell/lid also raise CG.

   **Fix:** do not launch this form factor upright without real low ballast or a much wider waterplane. For merely neutral stability, add about **170 g of effective submerged hanging ballast** acting at \(z\approx5\) mm; that yields draft ≈89 mm and \(GM\approx0\). For a still-modest \(GM\approx10\) mm, use about **250–260 g effective ballast at the keel**, but then draft is ≈100 mm and functional freeboard is only ≈16 mm. The better fix is increase `hull_od` from `100` to at least **140–150 mm**, keep ballast low, and keep the battery as low as packaging permits. A 100 mm × 132 mm upright cylinder is a poor river buoy hull.

2. **Blocker — the claimed 49 mm freeboard omits the tethered hydrophone’s effective weight.**  
   `payload_g` is only `230 + 12 + 60` (line 160). It does not include the printed `head_body()`, its washers/nuts, or the 1–2 m wet cable. The suspended assembly pulls downward by its **submerged effective weight**, not its dry mass, and must be included in the buoy displacement calculation.

   Each additional 100 g effective downward load adds:

   \[
   100/7.854=12.7\ {\rm mm}
   \]

   of draft. Therefore:

   | Effective suspended load | Draft | Freeboard to 116 mm shoulder |
   |---:|---:|---:|
   | 0 g (code estimate) | 67 mm | 49 mm |
   | 100 g | 80 mm | 36 mm |
   | 200 g | 93 mm | 23 mm |
   | 250 g | 99 mm | 17 mm |

   The very ballast needed to make this hull righting-stable nearly eliminates its wave margin. The 16 mm threaded neck is geometrically still above that shoulder, but it is not a safe, dry freeboard reserve once wakes wet the threads and cable entry.

   **Fix:** weigh the complete dry buoy and weigh the fully submerged hydrophone/washer/cable assembly in water; use the latter as added load. Change line 160 to include a measured `tether_effective_g`. Do not accept less than roughly **50 mm freeboard to the lowest credible ingress path** after that load is included; with this diameter, that means materially reducing mass or increasing `hull_od`.

3. **Major — the two “bottom” tether lugs do not by themselves guarantee a stabilizing bridle; their geometry needs to carry the hanging load centrally.**  
   `eye_lug(0, 0)` and `eye_lug(0, 180)` (line 74) put the hole centers approximately 51 mm from the centerline and around \(z=3\) mm. This can be excellent *if* the bridle legs are equal and join at a central point below the buoy: the combined vertical tether force then acts near the bottom center and supplies the low “ballast” moment assumed above.

   But a single cable tied through one lug, unequal bridle legs, or a snagged cable makes the force off-axis. A 100 g downward tether load acting 51 mm off-center produces:

   \[
   0.981\ {\rm N}\times0.051\ {\rm m}=0.050\ {\rm N\,m}
   \]

   — far more than this unballasted hull’s nonexistent restoring moment. It will heel hard toward the loaded lug.

   **Fix:** use a fixed, equal-length two-leg bridle to a single ring **at least 100–150 mm below the hull**, then attach the hydrophone line at that ring. Add a centered underside attachment point if printing can be changed. Do not tie the hydrophone cable/line directly to either edge lug.

4. **Major — the top “mooring” eye is a capsize lever under horizontal line load.**  
   The top lug is generated at `eye_lug(hull_h - neck_h - lug_t - 4, 90)` (line 75), i.e. its hole is about \(z=109\) mm, while the nominal waterline is \(z=67\) mm. A mooring pull therefore acts about 42 mm above the waterline. At only 10 m/s wind, the exposed nominal 100 mm × 49 mm projected area gives approximately:

   \[
   F_{\rm wind}\approx \tfrac12(1.2)(1.1)(0.100)(0.049)(10^2)
   \approx0.32\ {\rm N}
   \]

   A comparable mooring-line force at the top lug applies about:

   \[
   0.32 \times 0.042 = 0.013\ {\rm N\,m}
   \]

   overturning moment. With the current negative \(GM\), essentially any sustained sideways line load makes this worse. Even with only 10 mm positive GM, that force corresponds to roughly 15° heel before accounting for gusts/wakes.

   **Fix:** eliminate the top mooring lug for anchoring. Attach any anchor/mooring line to the same **low central bridle ring** as the hydrophone, or move the towing/mooring point to approximately the loaded waterline, `z ≈ 60–70 mm`, with a sealed attachment. The existing top lug is suitable only as a carry/recovery feature, not a mooring point.

5. **Major — wake and splash tolerance is inadequate once the real hanging load/ballast is added.**  
   At the stated no-tether-load condition, 49 mm to the neck shoulder is already little margin for a 100 mm-diameter object in boat wake. At 100–200 g effective tether load it becomes 36–23 mm. A short wake can readily wash over the lid, wet the external thread, and immerse the cable penetration. Repeated splash is more concerning than a single static submersion because it creates pumping through imperfect threads/gaskets.

   The cable hole is `gland_hole = 6` mm (line 29; cut at line 109). The design comment calls for hot glue / heat shrink on the boss (line 111), but hot glue is explicitly unavailable. A plain 6 mm hole around a cable is not splashproof.

   **Fix:** use the available **marine adhesive heat-shrink** as the actual cable gland: shrink it onto the cable, pass it through a tighter hole sized to the recovered sleeve OD, and tape/strain-relieve it to the boss. Add a drip loop below the lid. For tomorrow, wrap the fully tightened lid/thread circumference with waterproof duct tape as a secondary splash barrier. This is not a substitute for restoring freeboard.

6. **Major — wind drift is unavoidable without an anchor; an anchor on the top lug is worse than drift.**  
   The same projected wind calculation gives about 0.08 N at 5 m/s and 0.32 N at 10 m/s. With no anchor, the buoy will drift downriver/downwind; the 1–2 m submerged hydrophone and line add current drag, so it will not remain near the intended listening location. With an anchor on the current top lug, the line’s high attachment converts that lateral load into heel/capsize moment.

   **Fix:** either operate it as a closely attended drifting device with recovery planned, or use a low bridle attachment and enough line/weight to hold station. Do not rely on Wi‑Fi range as recovery control. A short tether to a shore-side fixed point should also attach through the low bridle, not the top eye.

7. **Minor — the code’s “freeboard” naming understates the distinction between hull shoulder and sealed top.**  
   Line 163 prints draft “of `hull_h - neck_h` mm sidewall,” i.e. 116 mm, yielding the quoted 49 mm. But the hull remains 100 mm OD through the 16 mm neck (lines 69–72), so the geometric distance from nominal waterline to rim is \(132-67=65\) mm. The 49 mm figure is appropriately conservative only if the start of the threaded neck is treated as the practical splash/ingress threshold. That should be explicit, because buoyancy calculations otherwise look more favorable than the actual splash-safe design.

   **Fix:** report both values: `freeboard_to_neck_mm = hull_h-neck_h-draft_mm` and `freeboard_to_rim_mm = hull_h-draft_mm`, and calculate both using the measured effective hydrophone load.

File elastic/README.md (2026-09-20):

# Keiko on Elastic

Elasticsearch is where the hydrophone stream stops being audio and becomes something you can ask questions of.
Built for the HackMIT 2026 **Elastic — Find the Signal** challenge (*best use of Elasticsearch to turn complex,
messy data into insights, answers or actions*).

```
pipeline --elastic ──► keiko-windows      every 1.5 s: label, 22 class probs, level/peak/centroid/flatness, packet loss
                   └─► keiko-detections   every event: species, confidence, geo_point, TDOA fix, 512-d CNN embedding,
                                          a sentence for ELSER
                              │
        ┌─────────────────────┼──────────────────────┬─────────────────────┬──────────────────┐
   ES|QL (queries.esql)   kNN "sounds like"    semantic_text / ELSER   ML anomaly job     alert rule → webhook
   Kibana Lens + Maps     ask.py --similar     ask.py --semantic       keiko-soundscape   "right whale: slow to 10 kn"
                                     ask.py  — Claude writes the ES|QL, runs it, answers
```

**Messy in:** a 3.3 kHz ADC stream over lossy UDP from a buoy, a classifier that is wrong a quarter of the time on
noise, synthetic and field recordings mixed in one CSV. **Insight out:** what species, when, where, how the
soundscape is drifting, which windows are *unusual*, in plain English.

| | |
|---|---|
| `keiko_es.py` | client, doc shapes (`detection_doc`, `window_doc`, `describe`), buffered bulk writer, ES\|QL / kNN / semantic reads |
| `features.py` | spectral descriptors per window; the CNN's pooled 512-d activations as the embedding |
| `mappings/*.json` | index templates: `geo_point`, `dense_vector` (cosine), `semantic_text`, dynamic `probs.*` floats |
| `setup.py` | provisions everything: templates, indices, ML job + datafeed, Kibana data views, ES\|QL alert rule (+ webhook) |
| `backfill.py` | loads `pipeline/out/events.jsonl` + `site/data/detections.csv`, re-running the CNN on each clip |
| `ask.py` | the agent (Claude ⇄ ES\|QL / kNN / ELSER tools) and the no-LLM `--esql` `--similar` `--semantic` `--anomalies` modes |
| `ask_server.py` | HTTP front for `ask.py` (`POST /ask`), the website's "Ask Keiko" chat panel |
| `queries.esql` | 11 ES\|QL queries: the dashboard panels and the demo questions |
| `kibana/dashboard.md` | the six-panel dashboard recipe + alerting |
| `test_elastic.py` | unit tests (docs, features, guard) + an integration round-trip against a real cluster |

## Setup

1. Elastic Cloud trial (sponsor credit): <https://www.elastic.co/cloud/cloud-trial-overview/30-days>. Create a
   deployment (any size; ML is on by default), then *Manage → API keys → create* with write access.
2. `cp .env.example .env` and fill in `ELASTIC_URL` (the Elasticsearch endpoint), `ELASTIC_API_KEY`, `KIBANA_URL`,
   `ANTHROPIC_API_KEY` (for `ask.py`), optionally `KEIKO_WEBHOOK_URL` (Discord/Slack) for the alert.
3. Python: the pipeline venv plus two packages.

```bash
cd ../pipeline && make venv                         # once, if not done
../.venv/bin/pip install -r ../elastic/requirements.txt
cd ../elastic
../.venv/bin/python setup.py                        # indices, ML job, data views, rule
../.venv/bin/python backfill.py                     # what we already recorded, with embeddings
../.venv/bin/python setup.py --status
```

Without ML nodes (self-hosted basic): `setup.py --no-elser --no-ml`; `description` becomes plain `text` and
`--semantic` falls back to a match query.

## Live

```bash
cd ../pipeline && make demo ARGS="--elastic"        # humpback loop -> windows + events into Elastic every few seconds
cd ../pipeline && make live ARGS="--elastic"        # the buoy
```

Both also accept `--server ws://…` (the map) and `--archive` (the site) at the same time.

## Ask

```bash
../.venv/bin/python ask.py "what has been on the hydrophone in the last hour, and how sure are we?"
../.venv/bin/python ask.py -v "is the noise floor at KEIKO-01 higher tonight than this afternoon?"
../.venv/bin/python ask.py "find three calls that sound like KEIKO-01-20260920T073538 and say what they have in common"
../.venv/bin/python ask.py --similar KEIKO-01-20260920T073538       # kNN, no LLM
../.venv/bin/python ask.py --semantic "long low tonal call at night"  # ELSER, no LLM
../.venv/bin/python ask.py --anomalies                                # ML job records
../.venv/bin/python ask.py --esql 'FROM keiko-windows | STATS n = COUNT(*), db = AVG(audio.rms_db) BY buoy_id'
../.venv/bin/python ask_server.py -v      # the same agent behind http://localhost:8766/ask for the site's Ask panel
```

`ask_server.py` is the website's chatbot: `POST /ask {question, session}` runs `ask()` and keeps one conversation per
`session`, so follow-ups work. The site posts to `NEXT_PUBLIC_KEIKO_ASK` (`http://localhost:8766` in `npm run dev`; unset
in the static build, which hides the button — set it at build time to a tunnel to this server for a deployed demo).

`ask.py` gives Claude (`claude-opus-5`) the two index schemas and an ES|QL cheat sheet, and three tools. It only
runs `FROM keiko-*` queries. `-v` prints every query it tries — good for the demo.

## What the judges should see (5 min)

1. `make demo ARGS="--elastic"` running; Kibana Discover on `keiko-windows` auto-refreshing: the raw, noisy stream.
2. Dashboard: detections by species, the map, soundscape level vs whale share, stream loss.
3. `ask.py --similar <id>`: kNN over the CNN embedding finds the same song bout's other events.
4. `ask.py --semantic "…"`: ELSER finds calls by how they were described, not by keyword.
5. Anomaly Explorer: the job flags the moment the loop started (level jump) — the "unlabelled sound" story.
6. `ask.py "…"`: the agent answers a question none of the panels were built for, with the ES|QL it wrote.
7. The right-whale rule firing to Discord: an *action*, the reason the buoys exist.

## Tests

```bash
../.venv/bin/python test_elastic.py                # unit tests always; integration when .env points at a cluster
```

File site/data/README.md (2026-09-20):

# Keiko detection database

Every whale detection the Keiko buoys report, kept in plain files in this folder so it can be cloned, diffed, cited, and opened in a spreadsheet without any tooling.

| file | what it is |
|---|---|
| `detections.csv` | one row per detection, the source of truth |
| `detections.json` | the same rows with typed values, read by the website |
| `buoys.csv` | buoy registry: id, name, position, hydrophone, sample rate |
| `sites.json` | the two demo sites for simulated data (Charles River, Boston Harbor): buoy position, channel axis, soundscape |
| `clips/<id>.wav` | 16-bit mono PCM audio of the call |
| `spectrograms/<id>.png` | mel spectrogram of the clip, 0–1 kHz, RGBA: the site's blue ramp with quiet bins transparent |
| `schema.json` | JSON Schema for a detection row |

## Columns

`id`, `buoy_id`, `timestamp_utc`, `latitude`, `longitude`, `confidence` (0–1), `species`, `peak_hz`, `duration_s`, `sample_rate_hz`, `clip_path`, `spectrogram_path`, `source` (`field`, `replay` or `synthetic`), `notes`.

Timestamps are ISO-8601 UTC. Paths are relative to this folder.

## Load it

```python
import pandas as pd
df = pd.read_csv("detections.csv", parse_dates=["timestamp_utc"])
df = df[df.source != "synthetic"]      # drop the generated demo rows
```

```r
df <- read.csv("detections.csv")
```

Or straight from GitHub without cloning:

```python
base = "https://raw.githubusercontent.com/2900xt/keiko-hackMIT/main/site/data/"
df = pd.read_csv(base + "detections.csv")
```

## Add a detection

```sh
pip install -r ../tools/requirements.txt
python3 ../tools/keiko_data.py add --wav call.wav --buoy KEIKO-01 \
    --time 2026-09-20T14:03:11Z --lat 42.3572 --lon -71.0868 --confidence 0.87 --species humpback
```

That copies the clip, renders its spectrogram, appends the CSV row, and regenerates the JSON. Commit the result. If you edit the CSV by hand, run `python3 ../tools/keiko_data.py rebuild` afterwards.

## Status

`source` says where a row came from: `field` = recorded at sea by a buoy; `replay` = a real recording (NPS humpback song) played through `pipeline/replay_wav.py` into the live pipeline, so the clip, species and confidence are the classifier's own output; `synthetic` = generated by `tools/keiko_data.py synth` to demonstrate the format.

Synthetic rows exist for both demo sites in `sites.json`, and the website shows the ones near the site it is set to (`/app/?site=charles`, the default, or `?site=harbor`; also a toggle in the Live rail). The Charles rows sound like the river, not like whales: motorboat passes (engine/prop hum with harmonics, pitch falling as the boat goes by) and crew shells (a broadband catch every 1.7–2 s), `species` = `motorboat` / `crew shell`. The harbor rows are the older whale-like tonal sweeps, `species` = `unknown`. `synth --site <key> --replace` regenerates one site's rows without touching the other's.

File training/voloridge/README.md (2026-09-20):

# Voloridge — Signal in the Noise

Keiko's training + analysis track for the Voloridge challenge. Two things happen here:

1. **Train on Voloridge compute.** The whale CNN pretrains on the 30k+ clip public corpus (Watkins, Cornell/Kaggle,
   NOAA, ReefSet, ...) on a Voloridge AWS GPU instance, then fine-tunes on our own Charles River / Boston Harbor
   hydrophone recordings. Laptop training is ~25 s/epoch at width 32; the GPU box lets us run width 64, 5 seeds,
   and the full 24-class set in the same wall-clock.
2. **Join NOAA ISD to the hydrophone noise floor.** NOAA's Integrated Surface Database (one of Voloridge's curated
   datasets, `s3://noaa-isd-pds`) gives hourly wind / pressure / precip at Boston Logan (`725090-14739`, 6 km from the
   buoy). We join it to the buoy's hourly noise floor and ask: how much of the underwater background is weather?
   That number is the "insight" slide.

```
public corpus (S3 / HF) ──┐                                 ┌── models/whale_cnn_volo.pt ──> pipeline/ (UNO Q)
                          ├── Voloridge GPU (g5, us-east-1) ─┤
Charles recordings ───────┘        train/pretrain.sh         └── models/whale_cnn_charles.pt
                                   train/finetune.py

s3://noaa-isd-pds ── data/fetch_isd.sh ── data/parse_isd.py ──┐
                                                              ├── analysis/join_isd.py ──> analysis/out/noise_vs_weather.*
pipeline/out/*.wav ── analysis/noise_floor.py ────────────────┘
```

## What Voloridge gives us

From their [challenge materials](https://voloridge-hack-mit-2026.s3.us-east-1.amazonaws.com/index.html):

- EC2 instances (CPU and GPU), **Amazon Linux 2023, `us-east-1`**, handed out at the booth after you pitch the project.
- The instances carry an `AmazonS3ReadOnlyAccess` role, so the public data buckets (`noaa-isd-pds`, etc.) read for free
  through the S3 gateway endpoint — same region, no egress.
- Per-dataset fetch tools: `aws s3 sync --no-sign-request s3://voloridge-hack-mit-2026/src ./vendor/voloridge`
  (`data/fetch_voloridge_tools.sh`). We use `noaa_isd/fetch.py` as-is instead of rolling our own.

Nothing here assumes anything else about the box: it is SSH + a GPU + Python, and everything runs inside a venv under
`~/keiko` on the instance.

## Layout

| Path | What |
|---|---|
| `voloridge.env.example` | copy to `voloridge.env`: instance host, SSH user/key. **Not committed.** |
| `Makefile` | every step below as a target |
| `configs/` | training hyperparameters for the GPU box, ISD station list |
| `infra/` | bootstrap the instance, rsync code up, pull models/runs down, run a command in a detached tmux session |
| `data/` | fetch Voloridge's tools, fetch + parse ISD, build features from the Charles recordings |
| `train/` | `pretrain.sh` (whale_cnn on the GPU), `finetune.py` (transfer to Charles classes) |
| `analysis/` | hourly noise floor from the recordings, join to ISD, correlations + plot |
| `vendor/` | Voloridge's `src/` tree (gitignored) |
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

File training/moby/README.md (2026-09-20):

# Moby: two-branch ensemble right-whale detector

PyTorch version of the ISEF poster model (*MobyGlobal: Real-Time Right Whale Detection Network Powered by a Two-Branch
Ensemble Learning Model*, Figure 8), trained on the 30,000 Cornell / Kaggle Whale Detection Challenge clips
(2 s @ 2 kHz, 7,027 North Atlantic right whale upcalls vs 22,973 noise). Right whale only for now.

## Pipeline

```
whale-detection-challenge.zip ──features.py──▶ ../dataset/features/moby_narw.npz ──train.py──▶ models/moby_narw.pt (+ .json, .onnx)
                                                                                                        │
                                                                                   predict.py file.wav ◀┘
```

```bash
pip install torch numpy librosa soundfile scikit-learn onnx
python3 features.py      # ~5 min on 8 cores: 11 librosa features per clip (poster Figure 6)
python3 train.py         # 2-fold ensemble, ~8 min on an M-series GPU (--folds 5 --epochs 20 for the full poster setup)
python3 predict.py some_hydrophone_recording.wav
```
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

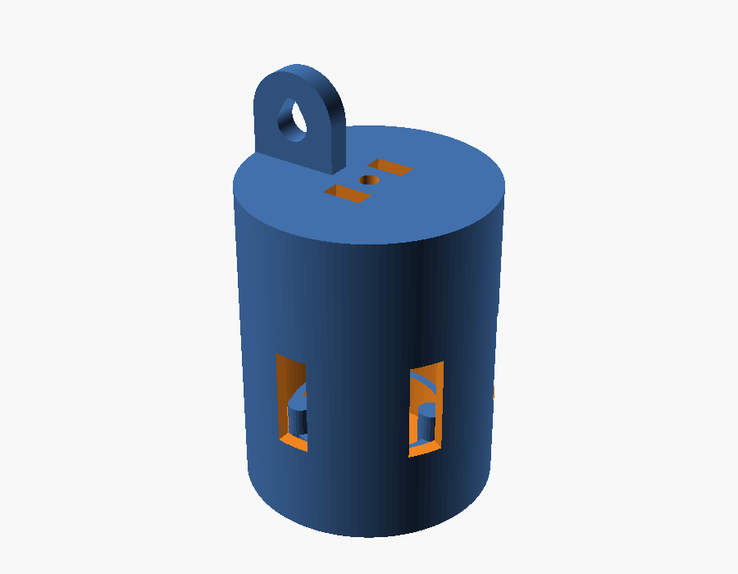
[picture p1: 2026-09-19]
hardware/buoy-v2/preview_head.png

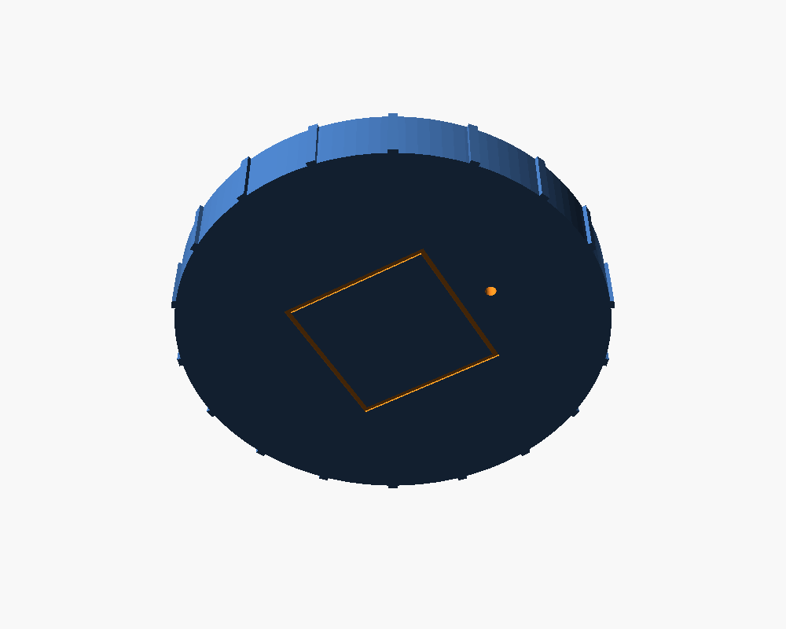
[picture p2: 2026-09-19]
hardware/buoy-v2/preview_lid.png

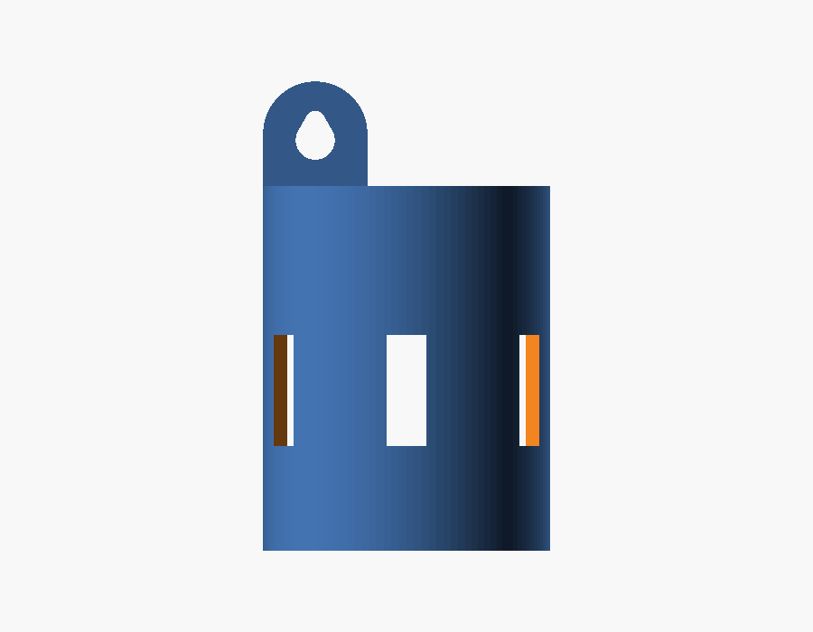
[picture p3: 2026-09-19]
hardware/buoy-v2/preview_head_cut.png

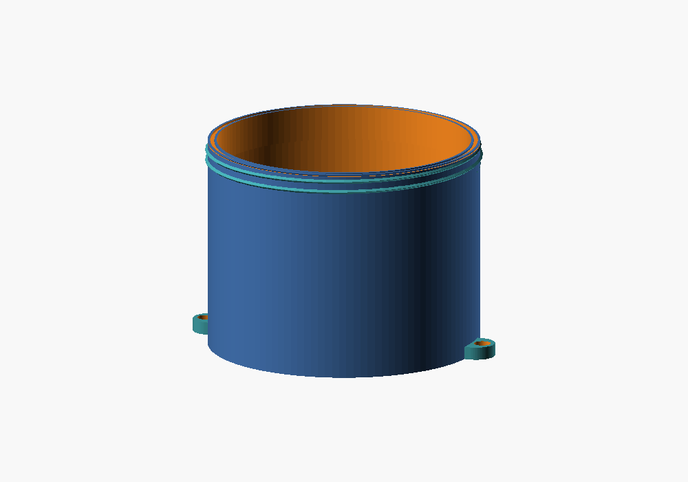
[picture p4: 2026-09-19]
hardware/buoy-v2/preview_thread.png

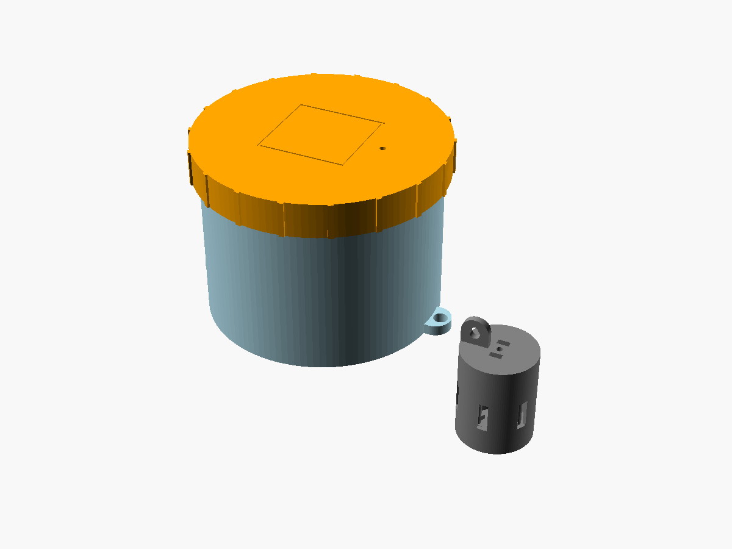
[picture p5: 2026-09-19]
hardware/buoy-v2/preview_all.png

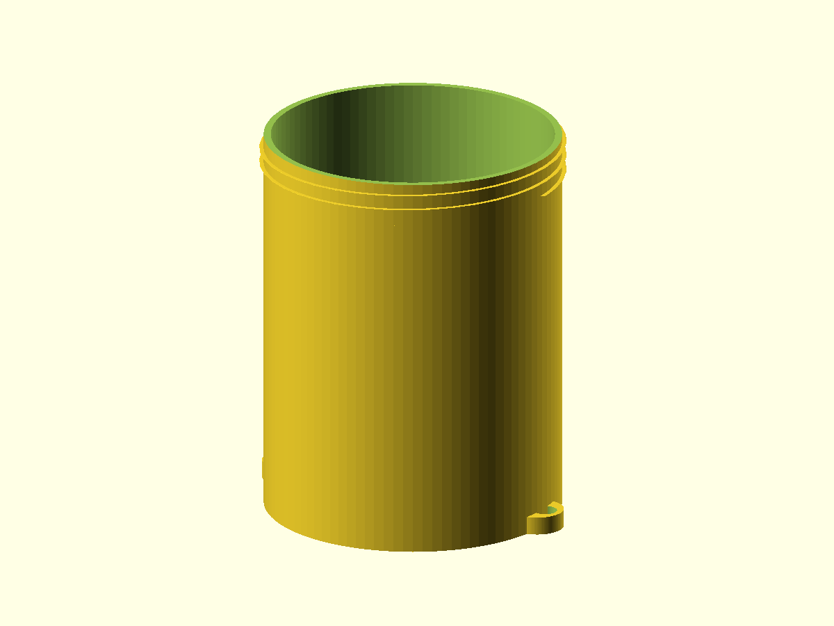
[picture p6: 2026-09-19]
hardware/buoy-v2/preview_hull_cut.png

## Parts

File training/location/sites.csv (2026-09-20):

site_id | source | provider | name | lat | lon | coord_precision_km
watkins:-45.0,167.0 | watkins | WHOI Watkins | 5 to 6 miles southeast of Kaikoura Head, New Zealand | -45.0 | 167.0 | 60.0
watkins:-52.0,-70.0 | watkins | WHOI Watkins | Straits of Magellan | -52.0 | -70.0 | 60.0
watkins:-77.0,169.0 | watkins | WHOI Watkins | Cape Crozier, Antarctica | -77.0 | 169.0 | 60.0
watkins:10.0,-86.0 | watkins | WHOI Watkins | Costa Rica | 10.0 | -86.0 | 60.0
watkins:13.0,-61.0 | watkins | WHOI Watkins | 11 mi. WSW West Cay, Bequia | 13.0 | -61.0 | 60.0
watkins:14.0,-61.0 | watkins | WHOI Watkins | Dominica | 14.0 | -61.0 | 60.0
watkins:15.0,-61.0 | watkins | WHOI Watkins | N end of Dominica | 15.0 | -61.0 | 60.0
watkins:15.232,-61.54 | watkins | WHOI Watkins | Dominica | 15.232 | -61.5398 | 2.0
watkins:15.233,-61.46 | watkins | WHOI Watkins | SW of Scott Head, Dominica | 15.233 | -61.4605 | 2.0
watkins:15.302,-61.458 | watkins | WHOI Watkins | Dominica | 15.3022 | -61.4583 | 2.0
watkins:15.306,-61.54 | watkins | WHOI Watkins | Dominica | 15.3057 | -61.54 | 2.0
watkins:15.309,-61.454 | watkins | WHOI Watkins | Dominica | 15.309 | -61.4537 | 2.0
watkins:15.381,-61.465 | watkins | WHOI Watkins | Dominica | 15.3813 | -61.4647 | 2.0
watkins:15.384,-61.468 | watkins | WHOI Watkins | Dominica | 15.3842 | -61.4677 | 2.0
watkins:15.398,-61.515 | watkins | WHOI Watkins | Dominica | 15.3982 | -61.5152 | 2.0
watkins:15.401,-61.518 | watkins | WHOI Watkins | Dominica | 15.4012 | -61.5182 | 2.0
watkins:15.404,-61.52 | watkins | WHOI Watkins | Dominica | 15.4045 | -61.52 | 2.0
watkins:15.407,-61.53 | watkins | WHOI Watkins | Dominica | 15.407 | -61.5303 | 2.0
watkins:15.419,-61.491 | watkins | WHOI Watkins | Dominica | 15.4194 | -61.4911 | 2.0
watkins:15.43,-61.493 | watkins | WHOI Watkins | Dominica | 15.4298 | -61.4933 | 2.0
watkins:15.465,-61.498 | watkins | WHOI Watkins | Dominica | 15.465 | -61.4983 | 2.0
watkins:15.503,-61.484 | watkins | WHOI Watkins | Dominica | 15.5027 | -61.4845 | 2.0
watkins:15.521,-61.545 | watkins | WHOI Watkins | Dominica | 15.5213 | -61.5452 | 2.0
watkins:15.535,-61.514 | watkins | WHOI Watkins | Dominica | 15.5348 | -61.5138 | 2.0
watkins:15.535,-61.528 | watkins | WHOI Watkins | Dominica | 15.535 | -61.5282 | 2.0
watkins:15.543,-61.509 | watkins | WHOI Watkins | Dominica | 15.543 | -61.509 | 2.0
watkins:16.0,-61.0 | watkins | WHOI Watkins | Dominica | 16.0 | -61.0 | 60.0
watkins:18.0,-64.0 | watkins | WHOI Watkins | 1-1.5 miles North of Tortola, British Virgin Islands | 18.0 | -64.0 | 60.0
watkins:18.0,-68.0 | watkins | WHOI Watkins | Tortola, British Virgin Islands | 18.0 | -68.0 | 60.0
watkins:19.0,-156.0 | watkins | WHOI Watkins | Kealakekua Bay, Hawaii | 19.0 | -156.0 | 60.0
watkins:19.0,-66.0 | watkins | WHOI Watkins | 3 miles N of San Juan, Puerto Rico | 19.0 | -66.0 | 60.0
watkins:19.467,-155.917 | watkins | WHOI Watkins | Kealakekua Bay, Hawaii | 19.4667 | -155.9167 | 2.0
watkins:19.5,-156.0 | watkins | WHOI Watkins | Kealakekua Bay, Hawaii | 19.5 | -156.0 | 2.0
watkins:21.0,-157.0 | watkins | WHOI Watkins | Off Maui, HI | 21.0 | -157.0 | 60.0
watkins:24.0,-112.0 | watkins | WHOI Watkins | Magdalena Bay, Baja, California | 24.0 | -112.0 | 60.0
watkins:25.0,-77.0 | watkins | WHOI Watkins | NW arm of Tongue of the Ocean, Northern Bahamas | 25.0 | -77.0 | 60.0
watkins:25.0,-79.0 | watkins | WHOI Watkins | 11 miles NW of Bimini, Northern Bahamas | 25.0 | -79.0 | 60.0
watkins:25.0,-80.0 | watkins | WHOI Watkins | Biscayne Bay, Florida | 25.0 | -80.0 | 60.0
watkins:28.0,-13.0 | watkins | WHOI Watkins | 4 mi. NE Isla de Lobo, Canary Islands | 28.0 | -13.0 | 60.0
watkins:29.0,-13.0 | watkins | WHOI Watkins | Lower end of Lanzarote Is., Canary I. | 29.0 | -13.0 | 60.0
watkins:29.0,-14.0 | watkins | WHOI Watkins | W of Lanzarote, Canary Islands | 29.0 | -14.0 | 60.0
watkins:31.0,-65.0 | watkins | WHOI Watkins | Plantagenet Bank, Bermuda | 31.0 | -65.0 | 60.0
watkins:31.967,-65.167 | watkins | WHOI Watkins | over Plantagenet Banks, Bermuda | 31.9667 | -65.1667 | 2.0
watkins:32.0,-117.0 | watkins | WHOI Watkins | 1 mi. off Point Loma, San Diego, Calif. | 32.0 | -117.0 | 60.0
watkins:32.0,-64.0 | watkins | WHOI Watkins | Bermuda | 32.0 | -64.0 | 60.0
watkins:32.267,-64.717 | watkins | WHOI Watkins | off Gibbs Hill Light, Bermuda | 32.2667 | -64.7167 | 2.0
watkins:32.367,-64.633 | watkins | WHOI Watkins | St. David's Island, Bermuda | 32.3667 | -64.6333 | 2.0
watkins:33.0,-118.0 | watkins | WHOI Watkins | San Pedro Channel, Santa Catalina Island, California | 33.0 | -118.0 | 60.0
watkins:33.0,-119.0 | watkins | WHOI Watkins | 10 mi. SE of San Pedro Light, Santa Cruz Island, California | 33.0 | -119.0 | 60.0
watkins:33.0,-17.0 | watkins | WHOI Watkins | Madeira | 33.0 | -17.0 | 60.0
watkins:36.0,-4.0 | watkins | WHOI Watkins | 90 miles E of Gibraltar | 36.0 | -4.0 | 60.0
watkins:36.0,15.0 | watkins | WHOI Watkins | 50 mi. NE Malta | 36.0 | 15.0 | 60.0
watkins:37.7,-73.017 | watkins | WHOI Watkins | Delaware | 37.7 | -73.0167 | 2.0
watkins:38.0,-64.0 | watkins | WHOI Watkins |  | 38.0 | -64.0 | 60.0
watkins:38.0,-71.0 | watkins | WHOI Watkins |  | 38.0 | -71.0 | 60.0
watkins:38.0,-72.0 | watkins | WHOI Watkins |  | 38.0 | -72.0 | 60.0
watkins:38.0,-73.0 | watkins | WHOI Watkins | North Atlantic | 38.0 | -73.0 | 60.0
watkins:38.0,-74.0 | watkins | WHOI Watkins |  | 38.0 | -74.0 | 60.0
watkins:38.0,12.0 | watkins | WHOI Watkins | Near Panarea, Italy | 38.0 | 12.0 | 60.0
watkins:38.0,13.0 | watkins | WHOI Watkins | SE of Ustica | 38.0 | 13.0 | 60.0
watkins:38.0,15.0 | watkins | WHOI Watkins | Near Filicudi, Italy | 38.0 | 15.0 | 60.0
watkins:39.0,-71.0 | watkins | WHOI Watkins |  | 39.0 | -71.0 | 60.0
watkins:39.0,-72.0 | watkins | WHOI Watkins |  | 39.0 | -72.0 | 60.0
watkins:39.75,-70.833 | watkins | WHOI Watkins | Western North Atlantic, between Block Canyon and Atlantis Canyon | 39.75 | -70.8333 | 2.0
watkins:39.79,-72.138 | watkins | WHOI Watkins | N of Hudson Canyon | 39.79 | -72.1383 | 2.0
watkins:40.0,-65.0 | watkins | WHOI Watkins |  | 40.0 | -65.0 | 60.0
watkins:40.0,-70.0 | watkins | WHOI Watkins | E of Stellwagen Bank | 40.0 | -70.0 | 60.0
watkins:40.0,-71.0 | watkins | WHOI Watkins |  | 40.0 | -71.0 | 60.0
watkins:40.0,8.0 | watkins | WHOI Watkins | Near Capo Caccia, Sardinia | 40.0 | 8.0 | 60.0
watkins:41.0,-66.0 | watkins | WHOI Watkins | W of Browns Bank | 41.0 | -66.0 | 60.0
watkins:41.0,-70.0 | watkins | WHOI Watkins | Menemsha Bight, Vineyard Sound, MA | 41.0 | -70.0 | 60.0
watkins:41.0,-71.0 | watkins | WHOI Watkins | Cape Cod Bay, MA | 41.0 | -71.0 | 60.0
watkins:41.525,-69.513 | watkins | WHOI Watkins | Georges Bank | 41.525 | -69.5133 | 2.0
watkins:41.642,-69.192 | watkins | WHOI Watkins | Georges Bank | 41.6417 | -69.1917 | 2.0
watkins:41.7,-69.8 | watkins | WHOI Watkins | Nauset Buoy, MA | 41.7 | -69.8 | 2.0
watkins:42.0,-61.0 | watkins | WHOI Watkins | Western North Atlantic | 42.0 | -61.0 | 60.0
watkins:42.0,-65.0 | watkins | WHOI Watkins | Off Baccaro Bank, N.S. | 42.0 | -65.0 | 60.0
watkins:42.0,-67.0 | watkins | WHOI Watkins | North Atlantic | 42.0 | -67.0 | 60.0
watkins:42.0,-70.0 | watkins | WHOI Watkins | Cape Cod Bay, MA | 42.0 | -70.0 | 60.0
watkins:42.0,-71.0 | watkins | WHOI Watkins | Vineyard Sound, Ma. | 42.0 | -71.0 | 60.0
watkins:42.217,-70.038 | watkins | WHOI Watkins | Georges Bank | 42.2167 | -70.0383 | 2.0
watkins:42.217,-70.08 | watkins | WHOI Watkins | Georges Bank | 42.2167 | -70.08 | 2.0
watkins:42.233,-70.033 | watkins | WHOI Watkins | Stellwagen Bank | 42.2333 | -70.0333 | 2.0
watkins:42.233,-70.217 | watkins | WHOI Watkins | Georges Bank, MA | 42.2333 | -70.2167 | 2.0
watkins:42.243,-70.075 | watkins | WHOI Watkins | Georges Bank | 42.2433 | -70.075 | 2.0
watkins:42.252,-70.095 | watkins | WHOI Watkins | Georges Bank | 42.2517 | -70.095 | 2.0
watkins:42.253,-70.1 | watkins | WHOI Watkins | Georges Bank | 42.2533 | -70.1 | 2.0
watkins:42.257,-69.992 | watkins | WHOI Watkins | Georges Bank | 42.2567 | -69.9917 | 2.0
watkins:42.283,-70.083 | watkins | WHOI Watkins | Georges Bank | 42.2833 | -70.0833 | 2.0
watkins:42.292,-70.042 | watkins | WHOI Watkins | Georges Bank | 42.2917 | -70.0417 | 2.0
watkins:42.292,-70.238 | watkins | WHOI Watkins | Stellwagen Bank | 42.2917 | -70.2383 | 2.0
watkins:42.3,-67.917 | watkins | WHOI Watkins | SE of Browns Bank | 42.3 | -67.9167 | 2.0
watkins:42.303,-70.103 | watkins | WHOI Watkins | Georges Bank | 42.3033 | -70.1033 | 2.0
watkins:42.322,-70.09 | watkins | WHOI Watkins | Georges Bank | 42.3217 | -70.09 | 2.0
watkins:42.333,-67.833 | watkins | WHOI Watkins | Northern edge of Georges Bank, western North Atlantic | 42.3333 | -67.8333 | 2.0
watkins:42.348,-70.073 | watkins | WHOI Watkins | Georges Bank | 42.3483 | -70.0733 | 2.0
watkins:42.36,-70.325 | watkins | WHOI Watkins | N end of Stellwagen Bank | 42.36 | -70.325 | 2.0
watkins:42.633,-61.85 | watkins | WHOI Watkins | Sable Island, Nova Scotia | 42.6333 | -61.85 | 2.0
watkins:42.65,-61.867 | watkins | WHOI Watkins | South of Sable Island, North Atlantic | 42.65 | -61.8667 | 2.0
watkins:43.0,-123.0 | watkins | WHOI Watkins | Vancouver, British Columbia | 43.0 | -123.0 | 60.0
watkins:43.0,-58.0 | watkins | WHOI Watkins | Gully, SE Sable I., Canada | 43.0 | -58.0 | 60.0
watkins:43.0,-59.0 | watkins | WHOI Watkins | Gully, SE Sable I., Canada BD | 43.0 | -59.0 | 60.0
watkins:43.0,-62.0 | watkins | WHOI Watkins | W of Browns Bank | 43.0 | -62.0 | 60.0
watkins:43.0,-65.0 | watkins | WHOI Watkins | S of Nova Scotia | 43.0 | -65.0 | 60.0
watkins:43.0,-70.0 | watkins | WHOI Watkins | Cape Porpoise, Maine | 43.0 | -70.0 | 60.0
watkins:43.0,10.0 | watkins | WHOI Watkins | Near Capraia, Italy | 43.0 | 10.0 | 60.0
watkins:43.0,8.0 | watkins | WHOI Watkins | Near San Remo, Italy | 43.0 | 8.0 | 60.0
watkins:43.017,-70.167 | watkins | WHOI Watkins | Gulf of Maine | 43.0167 | -70.1667 | 2.0
watkins:44.0,-64.0 | watkins | WHOI Watkins | Halifax, Nova Scotia | 44.0 | -64.0 | 60.0
watkins:44.0,15.0 | watkins | WHOI Watkins | Near Losinij, Yugoslavia | 44.0 | 15.0 | 60.0
watkins:45.0,-66.0 | watkins | WHOI Watkins | Bay of Fundy, near Wolves Is. | 45.0 | -66.0 | 60.0
watkins:45.0,-67.0 | watkins | WHOI Watkins | NW tip of Deer Island, New Brunswick, Canada | 45.0 | -67.0 | 60.0
watkins:47.0,-62.0 | watkins | WHOI Watkins | St. Lawrence River, Canada | 47.0 | -62.0 | 60.0
watkins:47.0,-70.0 | watkins | WHOI Watkins | Ile aux Coudres, PQ, Canada | 47.0 | -70.0 | 60.0
watkins:47.417,-70.417 | watkins | WHOI Watkins | Ile aux Coudres, PQ, Canada | 47.4167 | -70.4167 | 2.0
watkins:47.533,-53.533 | watkins | WHOI Watkins | Dildo Arm, Trinity Bay, Newfoundland, Canada | 47.5333 | -53.5333 | 2.0
watkins:48.0,-123.0 | watkins | WHOI Watkins | Saanich Inlet, Victoria, Vancouver Island, British Columbia, Canada | 48.0 | -123.0 | 60.0
watkins:48.0,-53.0 | watkins | WHOI Watkins | Trinity Bay, Newfoundland | 48.0 | -53.0 | 60.0
watkins:48.0,-69.0 | watkins | WHOI Watkins | Baie Ste. Catherine, Canada | 48.0 | -69.0 | 60.0
watkins:48.0,-70.0 | watkins | WHOI Watkins | Baie Ste. Catherine, CanadaX ; Saguenay River, Canada | 48.0 | -70.0 | 60.0
watkins:49.0,-123.0 | watkins | WHOI Watkins | Vancouver, British Columbia | 49.0 | -123.0 | 60.0
watkins:49.0,-67.0 | watkins | WHOI Watkins |  | 49.0 | -67.0 | 60.0
watkins:60.0,-148.0 | watkins | WHOI Watkins | Three to four miles N. of Crafton Is., Prince William Sound, Alaska | 60.0 | -148.0 | 60.0
watkins:60.533,-147.958 | watkins | WHOI Watkins | 1 mi. N of Crafton Island, Alaska | 60.5333 | -147.9583 | 2.0
watkins:66.0,-169.0 | watkins | WHOI Watkins | Bering Strait | 66.0 | -169.0 | 60.0
watkins:68.0,16.0 | watkins | WHOI Watkins | Kikvika, Norway | 68.0 | 16.0 | 60.0
watkins:69.0,-16.0 | watkins | WHOI Watkins | Andenes, Norway | 69.0 | -16.0 | 60.0
watkins:70.0,-78.0 | watkins | WHOI Watkins | Koluktoo Bay, N. Baffin Island | 70.0 | -78.0 | 60.0
watkins:71.0,-157.0 | watkins | WHOI Watkins | Barrow, Alaska | 71.0 | -157.0 | 60.0
watkins:71.0,-40.0 | watkins | WHOI Watkins | 80 mi. south of Martha's Vineyard, Massachusetts | 71.0 | -40.0 | 60.0
watkins:72.0,-160.0 | watkins | WHOI Watkins | W Pt. Barrow, Alaska | 72.0 | -160.0 | 60.0
watkins:73.0,-78.0 | watkins | WHOI Watkins | 2 mi. N of Pond Inlet, Baffin Island, Canada | 73.0 | -78.0 | 60.0
watkins:74.0,-105.0 | watkins | WHOI Watkins | E Cumins Inlet, Stratton Is., Canada | 74.0 | -105.0 | 60.0
watkins:74.0,-85.0 | watkins | WHOI Watkins | E Cumins Inlet, Stratton Is. | 74.0 | -85.0 | 60.0
watkins:75.0,-75.0 | watkins | WHOI Watkins | N tip of Baffin Island, N.W.T., Canada | 75.0 | -75.0 | 60.0
dclde:BarkleyCanyon | dclde | ONC | Barkley Canyon (ONC) | 48.43 | -126.17 | 1.0
dclde:BoundaryPass | dclde | JASCO_VFPA | Boundary Pass | 48.76 | -123.07 | 1.0
dclde:Cpe_Elz | dclde | SIO | Cape Elizabeth HARP | 47.36 | -124.68 | 1.0
dclde:Field_HTI | dclde | UAF_NGOS | Kenai Fjords / Prince William Sound (vessel-based) | 60.15 | -147.59 | 50.0
dclde:Field_SondTrap | dclde | UAF_NGOS | Kenai Fjords / Prince William Sound (vessel-based) | 60.15 | -147.59 | 50.0
dclde:HE_67391498 | dclde | UAF_NGOS | Hinchinbrook Entrance, PWS | 60.31 | -146.97 | 5.0
dclde:HE_67424266 | dclde | UAF_NGOS | Hinchinbrook Entrance, PWS | 60.31 | -146.97 | 5.0
dclde:HaroStraitNorth | dclde | JASCO_VFPA | Haro Strait Northbound | 48.52 | -123.19 | 1.0
dclde:HaroStraitSouth | dclde | JASCO_VFPA | Haro Strait Southbound | 48.52 | -123.21 | 1.0
dclde:KB_5354 | dclde | UAF_NGOS | Kachemak Bay | 59.88 | -151.85 | 5.0
dclde:KB_67383303 | dclde | UAF_NGOS | Kachemak Bay | 59.88 | -151.85 | 5.0
dclde:KB_67424266 | dclde | UAF_NGOS | Kachemak Bay | 59.88 | -151.85 | 5.0
dclde:LimeKiln | dclde | SMRUConsulting | Lime Kiln Point, San Juan Island | 48.51 | -123.15 | 1.0
dclde:MS_5360 | dclde | UAF_NGOS | Montague Strait, PWS | 60.18 | -147.82 | 5.0
dclde:MS_671879205 | dclde | UAF_NGOS | Montague Strait, PWS | 60.18 | -147.82 | 5.0
dclde:MS_6897 | dclde | UAF_NGOS | Montague Strait, PWS | 60.18 | -147.82 | 5.0
dclde:Quin_Can | dclde | SIO | Quinault Canyon HARP | 47.5 | -125.35 | 1.0
dclde:RB_335826997 | dclde | UAF_NGOS | Resurrection Bay | 59.73 | -149.53 | 5.0
dclde:RB_67424266 | dclde | UAF_NGOS | Resurrection Bay | 59.73 | -149.53 | 5.0
dclde:StraitofGeorgia | dclde | JASCO_VFPA_ONC | Strait of Georgia (ONC node) | 49.04 | -123.32 | 1.0
dclde:Tekteksen | dclde | SIMRES | Tekteksen, Saturna Island | 48.78 | -123.05 | 1.0
dclde:bush_point | dclde | OrcaSound | Bush Point, Whidbey Island | 48.03 | -122.61 | 1.0
dclde:orcasound_lab | dclde | OrcaSound | Orcasound Lab, Haro Strait | 48.52 | -123.16 | 1.0
dclde:port_townsend | dclde | OrcaSound | Port Townsend | 48.14 | -122.76 | 1.0
aad:BallenyIslands2015 | aad | AAD / IWC-SORP | Balleny Islands 2015 (Southern Ocean mooring) | -65.3557 | 167.9115 | 1.0
aad:ElephantIsland2013Aural | aad | AAD / IWC-SORP | Elephant Island 2013 (Southern Ocean mooring) | -61.0147 | -55.9755 | 1.0
aad:ElephantIsland2014 | aad | AAD / IWC-SORP | Elephant Island 2014 (Southern Ocean mooring) | -61.0147 | -55.9755 | 1.0
aad:Greenwich64S2015 | aad | AAD / IWC-SORP | G64 2015 (Southern Ocean mooring) | -64.0053 | 0.0037 | 1.0
aad:MaudRise2014 | aad | AAD / IWC-SORP | Maud Rise 2014 (Southern Ocean mooring) | -65.0 | 2.5 | 1.0
aad:RossSea2014 | aad | AAD / IWC-SORP | Ross sea 2014 (Southern Ocean mooring) | -75.0198 | 164.5918 | 1.0
aad:casey2014 | aad | AAD / IWC-SORP | Casey 2014 (Southern Ocean mooring) | -63.7955 | 111.7872 | 1.0
aad:casey2017 | aad | AAD / IWC-SORP | Casey 2017 (Southern Ocean mooring) | -63.7955 | 111.7872 | 1.0
aad:kerguelen2005 | aad | AAD / IWC-SORP | S Kerguelen 2005 (Southern Ocean mooring) | -62.5907 | 81.2607 | 1.0
aad:kerguelen2014 | aad | AAD / IWC-SORP | S Kerguelen 2014 (Southern Ocean mooring) | -62.3802 | 81.7968 | 1.0
aad:kerguelen2015 | aad | AAD / IWC-SORP | S Kerguelen 2015 (Southern Ocean mooring) | -62.3802 | 81.7968 | 1.0

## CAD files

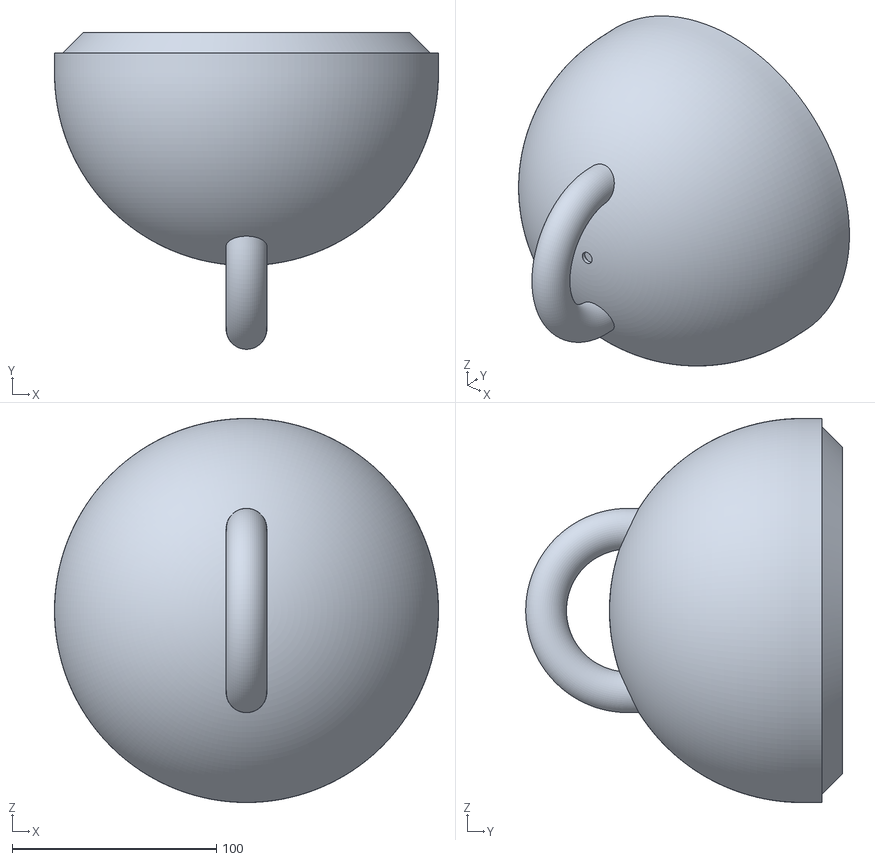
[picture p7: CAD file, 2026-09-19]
hardware/buoy-3d/bottom.stl
188.0 x 155.0 x 188.0

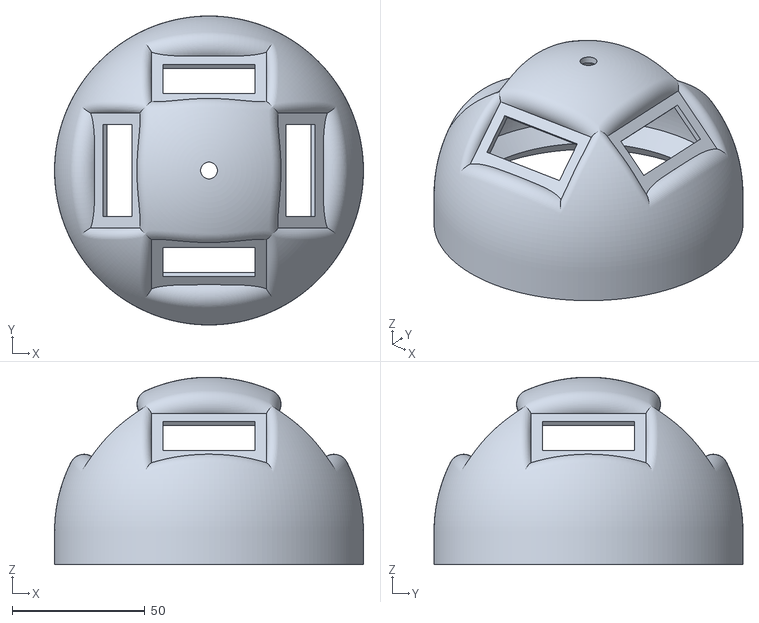
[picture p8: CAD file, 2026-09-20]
hardware/buoy-sla/top_sla.stl
116.6 x 116.6 x 70.6

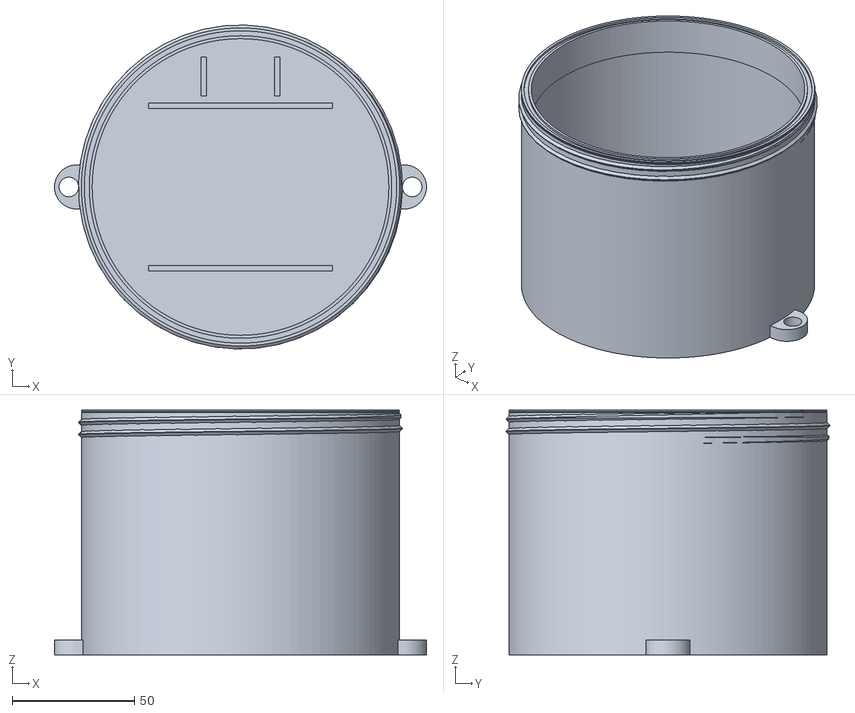
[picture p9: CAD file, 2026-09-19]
hardware/buoy-v2/hull.stl
152.0 x 132.4 x 100.0

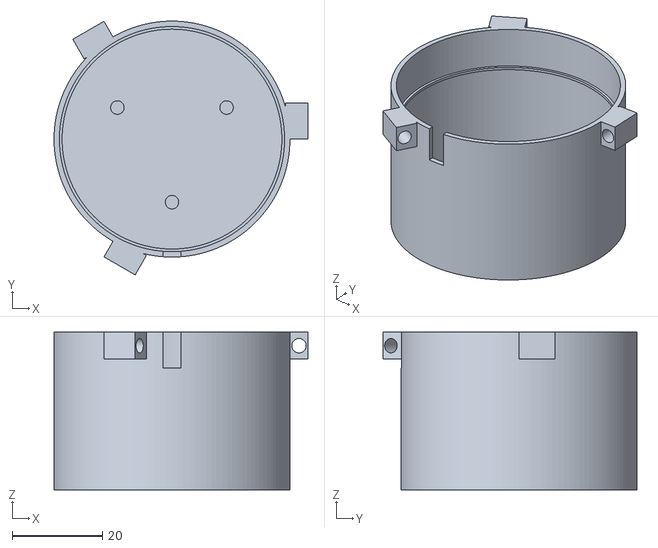
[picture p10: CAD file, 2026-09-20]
hardware/hydrophone-cup/hydrophone_cup.stl
56.4 x 56.4 x 35.0

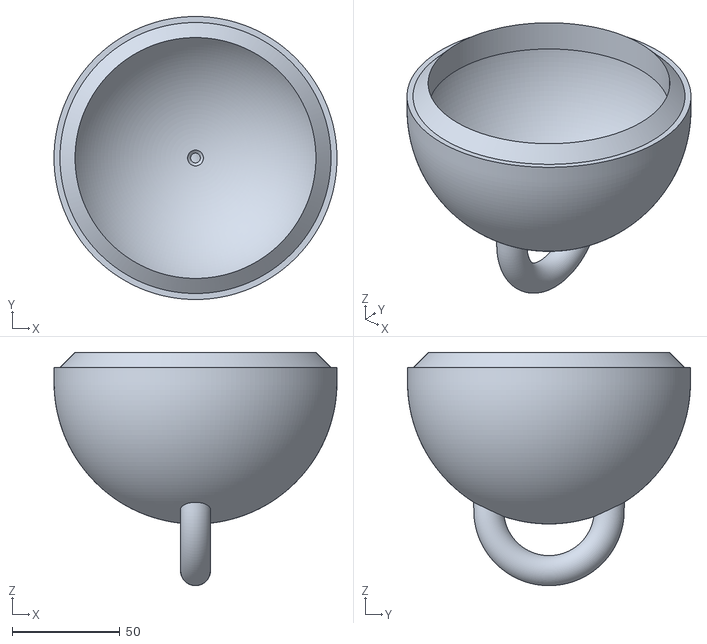
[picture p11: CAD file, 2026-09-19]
hardware/buoy-3d/bottom_zup_70pct.stl
131.6 x 131.6 x 108.5

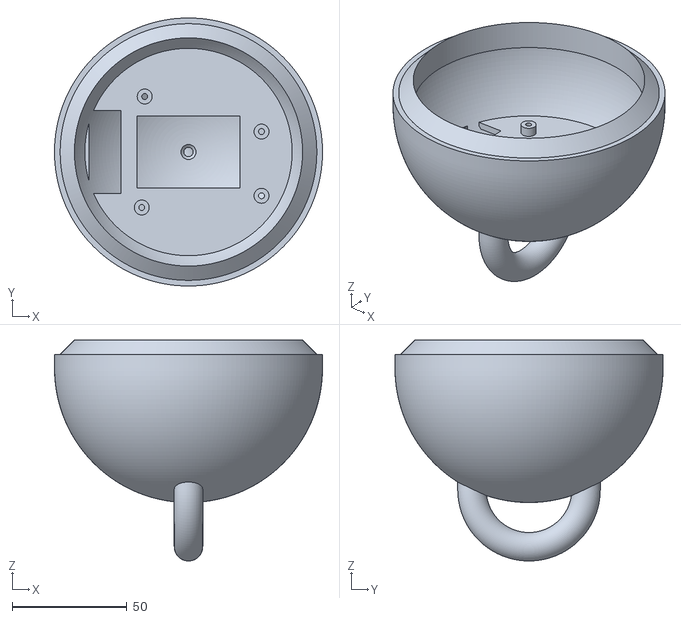
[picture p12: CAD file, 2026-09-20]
hardware/buoy-sla/bottom_sla_unoq_tray.stl
116.5 x 116.6 x 96.1

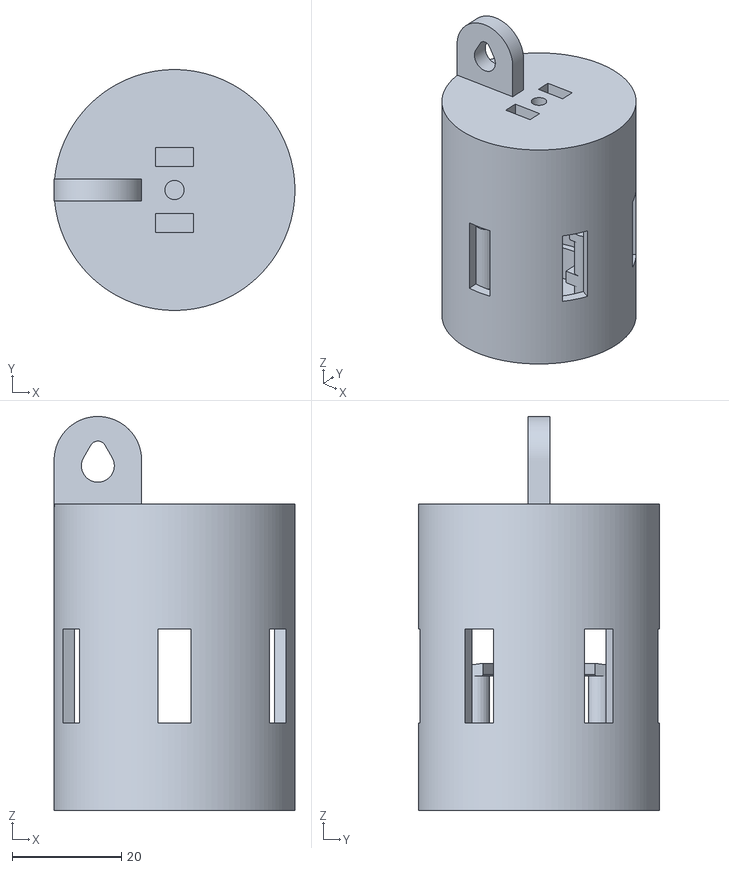
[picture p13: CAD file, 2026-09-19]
hardware/buoy-v2/head.stl
44.0 x 44.0 x 72.0

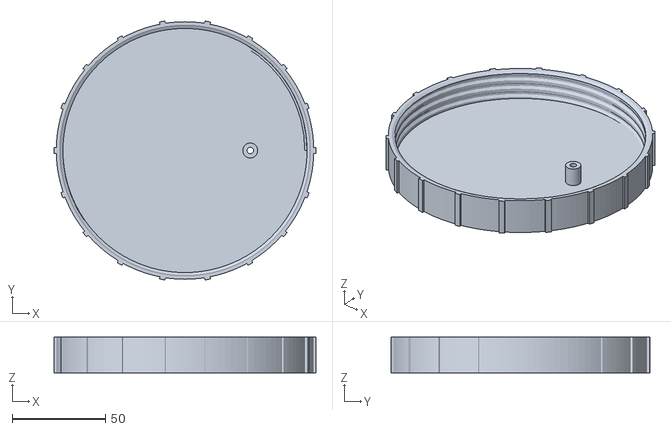
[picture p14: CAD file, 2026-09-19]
hardware/buoy-v2/lid.stl
140.5 x 138.9 x 19.2

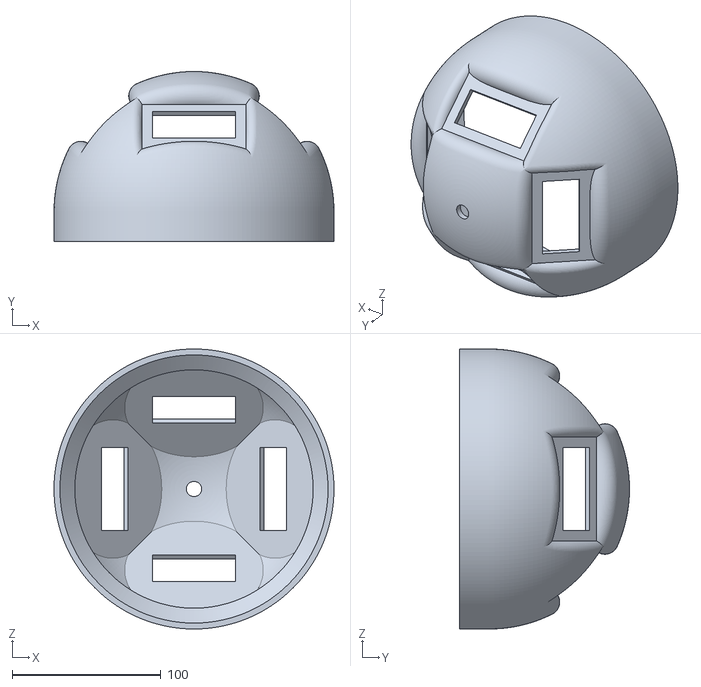
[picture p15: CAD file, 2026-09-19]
hardware/buoy-3d/top.stl
188.0 x 113.9 x 188.0

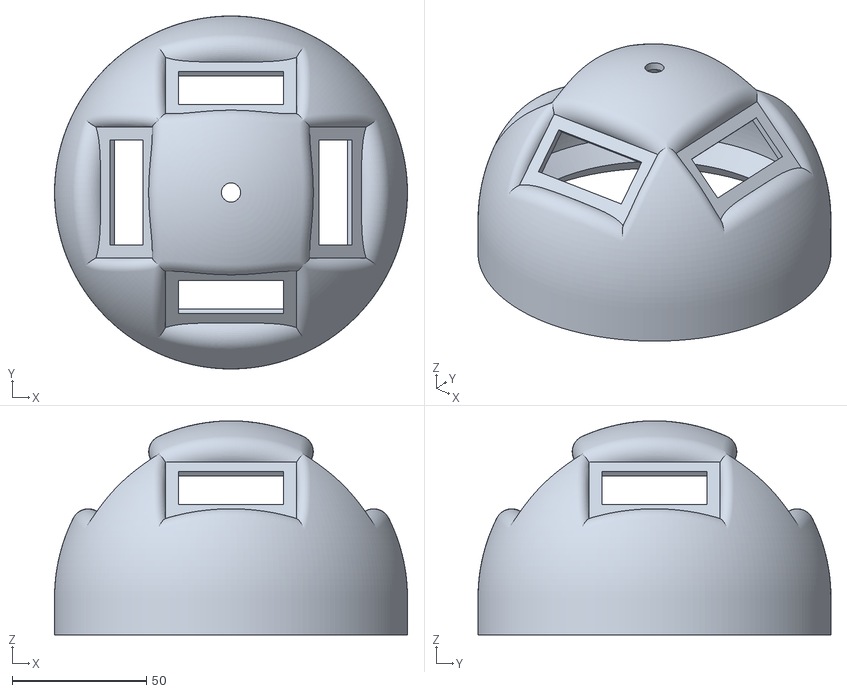
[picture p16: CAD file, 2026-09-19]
hardware/buoy-3d/top_zup_70pct.stl
131.6 x 131.6 x 79.7

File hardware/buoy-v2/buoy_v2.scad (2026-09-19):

// Charles Ear buoy v2.3 — parametric hull for one ESP32-S3 DevKitC + USB power bank,
// hydrophone on a tether below. Two Bambu/Prusa-class PLA printers, each plate ~4 h.
//
// v2.1 after Codex adversarial review: squat 130 mm hull (positive GM), power bank lies flat on
// the floor, ESP32 stands in the side crescent with its antenna above the waterline, 45° thread
// with opposite hand in the lid, gasket groove in a thickened neck land, lugs moved outboard,
// top mooring lug deleted (mooring goes to the low bridle ring), lid panel is an engraved outline
// (no 60 mm bridge), head has a 45° cone roof, connected posts, retaining tabs, parallel zip slots,
// and an eye plate that prints from the roof.
//
// part = "hull" | "lid" | "head" | "plate_b" (lid + head) | "all" (assembly preview)
part = "all";

/* ---------------- payload (measure yours) ---------------- */
bank_l = 95;   bank_w = 62;  bank_t = 15;  bank_g = 115;   // 5,000 mAh USB power bank (measure yours), lies FLAT on the floor
esp_l  = 70;   esp_w  = 26;  esp_h  = 20;  esp_g  = 12;    // ESP32-S3 DevKitC with headers, stands vertical, antenna UP
tether_eff_g = 100;      // effective (submerged) weight of head + washers + wet cable hanging from the bridle
misc_g = 60;             // cables, gasket, tape

/* ---------------- hull -------------------- */
hull_od   = 130;
wall      = 2.0;         // print as 5 lines x 0.42 mm, no infill in the shell
floor_t   = 2.4;
hull_h    = 100;         // total height incl. neck
neck_h    = 14;
land_t    = 2.4;         // extra wall thickness inside the neck so the gasket groove has material
clr       = 0.45;        // radial clearance hull thread <-> lid thread
pitch     = 5;
thread_h  = 1.2;         // radial height of the trapezoid thread
thread_b  = 2.6;         // axial base width of the thread
turns     = 2.2;
groove_w  = 2.0;  groove_d = 0.9;   // gasket groove on the neck rim; 2 mm rubber cord or two rubber bands

/* ---------------- lid --------------------- */
lid_top_t  = 3.2;
skirt_wall = 2.4;
panel_x = 50; panel_y = 50; panel_line = 1.6; panel_depth = 0.6;   // engraved outline only, prints on the bed
gland_hole = 3.5;                            // = cable_d + 0.5 (cable_d below); marine heat shrink over the boss seals it
gland_boss = 8; gland_boss_h = 10;           // INTERNAL boss (lid prints top-down)

/* ---------------- lugs -------------------- */
lug_t = 6;  lug_hole = 8;  lug_r = 9;        // two bottom lugs, opposite, for a two-leg bridle to a ring 100-150 mm below

/* ---------------- hydrophone head --------- */
head_od = 44; head_h = 56; head_wall = 2.4; head_floor = 3;
piezo_pack_d = 24;  piezo_pack_t = 8;        // SEALED disc assembly (balloon / coating), not the bare 20 mm disc
sinker_d = 25.5; sinker_h = 8;               // 1" fender washers, taped into a stack; +0.5 mm clearance
slot_w = 6; n_slots = 6;
cable_d = 3.0;   // hydrophone cable OD; head hole is cable_d + 0.5

$fn = 120;
eps = 0.01;

hull_r  = hull_od/2;
neck_r  = hull_r;
lid_bore_r = neck_r + clr;
lid_od  = 2*(neck_r + thread_h + clr + skirt_wall);
lid_skirt_h = neck_h + 2;
thread_z0 = hull_h - neck_h + 1.5;           // where the hull thread starts

// ---------- helpers ----------
module thread_slice(r, h_rad, base, extra, hscale) {
    // r-z profile: 0.3 mm root embed (inside the wall, never exposed) + 45° trapezoid tooth.
    // extruded a hair tangentially; hull-chained along the helix by helix_thread()
    hh = h_rad*hscale;
    rotate([90,0,0]) linear_extrude(0.02, center = true)
        polygon([[r - 0.3 - extra, -(base/2 + extra)],
                 [r + extra,       -(base/2 + extra)],
                 [r + hh + extra,  -(base/2 - hh) - extra],
                 [r + hh + extra,   (base/2 - hh) + extra],
                 [r + extra,        (base/2 + extra)],
                 [r - 0.3 - extra,  (base/2 + extra)]]);
}
module helix_thread(r, h_rad, base, pitch, turns, hand = 1, extra = 0, ramp = 0.35) {
    // true helical sweep: profile lives in the r-z plane, so `base` is the AXIAL width.
    // hand=+1 right-hand. ramp: fraction of a turn over which the tooth height grows from 0 at each end.
    n = ceil(turns*48);
    for (i = [0:n-1]) {
        t0 = i/n*turns; t1 = (i+1)/n*turns;
        hull() {
            rotate([0,0,hand*360*t0]) translate([0,0,pitch*t0]) thread_slice(r, h_rad, base, extra, min(1, t0/ramp, (turns - t0)/ramp));
            rotate([0,0,hand*360*t1]) translate([0,0,pitch*t1]) thread_slice(r, h_rad, base, extra, min(1, t1/ramp, (turns - t1)/ramp));
        }
    }
}
module eye_lug(z0, rot) {
    // vertical-axis loop outboard of the hull wall, bottom face at z0 (prints flat on the bed)
    rotate([0,0,rot]) translate([hull_r + 2, 0, z0])
        difference() {
            hull() { cylinder(r = lug_r, h = lug_t); translate([-lug_r - 4, -lug_r, 0]) cube([4, 2*lug_r, lug_t]); }
            translate([lug_r*0.35, 0, -eps]) cylinder(d = lug_hole, h = lug_t + 2*eps);
        }
}

// ---------- hull ----------
module hull_body() {
    slot = bank_w + 2;
    difference() {
        union() {
            cylinder(r = hull_r, h = hull_h);
            translate([0,0,thread_z0]) helix_thread(neck_r, thread_h, thread_b, pitch, turns, 1);
            eye_lug(0, 0); eye_lug(0, 180);
        }
        // cavity, stepped: thinner wall below, thicker land in the neck
        translate([0,0,floor_t]) cylinder(r = hull_r - wall, h = hull_h - neck_h - floor_t - 2 + eps);
        translate([0,0,hull_h - neck_h - 2]) cylinder(r = hull_r - wall - land_t, h = neck_h + 3);
        // gasket groove centred in the land
        gr = hull_r - (wall + land_t)/2;
        translate([0,0,hull_h - groove_d])
            difference() { cylinder(r = gr + groove_w/2, h = groove_d + eps); translate([0,0,-eps]) cylinder(r = gr - groove_w/2, h = groove_d + 3*eps); }
        // thread lead-in chamfer at the rim (outer edge)
        translate([0,0,hull_h - 1]) difference() { cylinder(r = hull_r + thread_h + 1, h = 1 + eps); cylinder(r1 = hull_r - 0.6, r2 = hull_r + 0.6, h = 1 + eps); }
    }
    // power-bank locating rails (low; bank lies FLAT, 65 mm side between the rails, 25 mm tall)
    rail_h = 8;
    for (s = [-1, 1]) translate([-bank_l/2 + 10, s*(slot/2 + 1.2) - 1.2, floor_t - eps]) cube([bank_l - 20, 2.4, rail_h]);
    // ESP32 pocket in the side crescent: two short ribs; board stands vertical, antenna up, leans on the wall
    esp_y = slot/2 + 1.2 + 12;
    for (s = [-1, 1]) translate([s > 0 ? esp_w/2 + 0.8 : -esp_w/2 - 0.8 - 2.4, esp_y - 8, floor_t - eps]) cube([2.4, 16, 12]);
}

// ---------- lid ----------
module lid_body() {
    // printed top-down: flat top on the bed, skirt up. Flipping is a rotation, so the groove keeps the
    // hull's handedness (hand = 1). The groove is the hull tooth grown by clr on every side.
    gland_r = panel_x/2 + 10;
    difference() {
        cylinder(r = lid_od/2, h = lid_skirt_h + lid_top_t);
        translate([0,0,lid_top_t]) {
            cylinder(r = lid_bore_r, h = lid_skirt_h + eps);
            translate([0,0,0.8]) helix_thread(neck_r, thread_h, thread_b, pitch, turns + 0.4, 1, clr, 0.001);
            // lead-in at the skirt mouth
            translate([0,0,lid_skirt_h - 1]) cylinder(r1 = lid_bore_r, r2 = lid_bore_r + thread_h + 0.5, h = 1 + eps);
        }
        // engraved panel outline (shallow groove, bridges nothing)
        translate([0,0,-eps]) linear_extrude(panel_depth + eps) difference() {
            square([panel_x, panel_y], center = true);
            square([panel_x - 2*panel_line, panel_y - 2*panel_line], center = true);
        }
        // cable hole, outside the outline
        translate([gland_r, 0, -eps]) cylinder(d = gland_hole, h = 50);
    }
    // internal gland boss
    translate([gland_r, 0, lid_top_t - eps]) difference() { cylinder(d = gland_boss, h = gland_boss_h); translate([0,0,-eps]) cylinder(d = gland_hole, h = gland_boss_h + 2*eps); }
    // grip ribs
    for (a = [0:20:359]) rotate([0,0,a]) translate([lid_od/2 - 0.6, -1.5, 0]) cube([1.8, 3, lid_skirt_h + lid_top_t]);
}
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

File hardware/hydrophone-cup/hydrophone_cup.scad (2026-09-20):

// Hydrophone potting cup: lost mold for 3x 20 mm piezo discs in epoxy/hot glue.
$fn = 128;
id   = 50;    // inner diameter: fits 3 discs (20 mm) in a triangle
wall = 1.2;   // 2-3 perimeters
h    = 35;    // height
floor_t = 1.2;
od = id + 2*wall;

difference() {
    union() {
        cylinder(d = od, h = h);                       // body
        // three rim tabs to tie the cable / hang the cup while curing
        for (a = [0, 120, 240]) rotate([0,0,a])
            translate([od/2 - 1, 0, h - 6]) cube([5, 8, 6], center = false);
    }
    translate([0,0,floor_t]) cylinder(d = id, h = h);   // cavity
    // zip-tie / string holes through the rim tabs
    for (a = [0, 120, 240]) rotate([0,0,a])
        translate([od/2 + 2, 4, h - 3]) rotate([90,0,0]) cylinder(d = 3.2, h = 20, center = true);
    // cable notch in rim so the tether can lie sideways while pouring
    translate([-2, -od/2 - 1, h - 8]) cube([4, wall + 2, 10]);
}
// floor standoffs: keep discs 2 mm off the floor so resin flows under them
for (a = [30, 150, 270]) rotate([0,0,a])
    translate([14, 0, floor_t - 0.01]) cylinder(d = 3, h = 2);
// pour line mark: small inner ridge 25 mm up (fill to here, then top off)
translate([0,0,25]) difference() { cylinder(d = id + 0.02, h = 0.6); translate([0,0,-1]) cylinder(d = id - 1.2, h = 3); }

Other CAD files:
hardware/hydrophone-cup/hydrophone_cup_A1.3mf
hardware/buoy-3d/bottom_zup_100pct.stl
hardware/buoy-3d/top_zup_100pct.stl

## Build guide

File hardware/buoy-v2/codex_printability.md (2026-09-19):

1. **Blocker — hydrophone posts are floating islands.** `head_body()` places each post at radius 11 mm with Ø3.5 mm (`L142`), while the sinker ring’s inner radius is 13 mm (`L140`). Each post reaches only 12.75 mm: a 0.25 mm air gap. They begin at z=11 mm over the empty sinker pocket, so the slicer will attempt to print three unsupported, disconnected columns. Fix: add radial ribs from the posts to the ring, or move/resize them to overlap it substantially; e.g. use `cylinder(d=4.5)` centered at radius 12 mm, plus a 2.4 mm-wide radial rib to the ring.

2. **Blocker — the head’s top eye begins in mid-air.** The eye is a horizontal-axis ring centered at z=50 mm (`L144`), extending down to about z=43 mm. The head’s interior is void up to z=47 mm (`L127`), so its first ~4 mm prints with nothing beneath it. The three-spoke roof also starts as a roughly 39.2 mm-diameter ceiling (`L127`, `L131–133`), which is an unreliable bridge at 0.28 mm, especially with the eye already failing below it. Fix: replace the eye with a vertical-axis annular tab built upward from the roof, and make the roof a support-free cone/spokes rising at ≤45°, or print a separate eye flat and mechanically attach it.

3. **Blocker — the lid’s 60 × 60 mm “recess” is a 60 mm bridge in its specified orientation.** The lid is intended outer-top-down (`L96`), but the solar recess removes the first 1.6 mm over a 60 mm square (`L107`). At z=1.6 mm the printer must span that whole square with no material below; the nearby cable boss does not solve it. This will sag badly or fail. Fix: delete the recessed solid panel for this print orientation and use an engraved outline/raised graphic instead; otherwise enable support and accept poor removability/finish in the recess.

4. **Blocker — the upper mooring lug does not print flat.** The two lower lugs at z=0 do (`L74`), but the third call is `eye_lug(106, 90)` (`L75`). Its 6 mm-thick horizontal lower face projects from the curved hull wall at z=106 mm, with no support below. The helper’s “prints flat” comment (`L57`) applies only to the bottom calls. Fix: print the top lug as a separate flat part and fasten it, or redesign it as a vertical fin/eye with 45° gussets from the hull.

5. **Blocker — the gasket groove removes the entire neck rim.** With `hull_r=50`, `wall=2.4`, and `groove_w=2.6`, the groove spans radii 47.5–50.1 mm (`L80–84`). The cavity already reaches radius 47.6 mm (`L78`) and the exterior ends at 50 mm. Thus the groove breaks through both sides of the 2.4 mm wall; it is not a retained groove. The exported `hull.stl` confirms its maximum z is **130.6 mm**, not 132 mm: the upper 1.4 mm of the neck wall is gone. Fix: either set `wall=3.6` mm to retain 0.5 mm lands on both sides of the 2.6 mm groove, or reduce `groove_w` to ≤1.4 mm and `groove_d` to about 0.8 mm.

6. **Major — the round helical ridge is not a support-free thread profile.** `helix_ridge()` twists a Ø3 mm circle (`L51–55`); the hull ridge starts abruptly at z=118 mm (`L72`) and produces a near-horizontal lower flank/ledge during upward printing. The matching internal groove has the corresponding difficult upper flank (`L104`). At 0.28 mm layers, a 3 mm round profile is much less forgiving than a 45° thread flank, and the start has no lead-in. Fix: replace the circular profile with a 45° triangular or trapezoidal profile, about 1.0–1.2 mm radial height with a 2.4 mm axial base; add 1–2 mm chamfered lead-ins and a thread-end relief.

7. **Major — 0.35 mm radial thread clearance is marginal for this large PLA screw lid.** The hull crest reaches radius 51.5 mm; the internal groove reaches 51.85 mm, exactly the specified 0.35 mm radial clearance (`L17–20`, `L44–48`, `L104`). That is only 0.70 mm diametral clearance before hole shrinkage, elephant-foot, seam blobs, and the round-flank overhang defects. The 5 mm pitch leaves only 2 mm nominal root-to-root axial space. Fix: use `clr=0.45`–`0.50` mm radial, keep pitch 5 mm, and use the 45° profile above. Deburr the first thread turn before relying on it.

8. **Major — the “under 4 hours” claim is not credible for the hull across Bambu/Prusa-class profiles.** The exported hull is **137.27 cm³ / 170.2 g**, consistent with the source estimate (`L157–163`). It requires a sustained, zero-overhead volumetric average of **9.53 mm³/s** just to finish in four hours:  
   `137,270 mm³ ÷ 14,400 s = 9.53 mm³/s`.  
   That excludes travel, 471-ish layers, outer-wall slowdowns, seam handling, and the thread/lug detail. A fast Bambu profile may approach four hours; a typical Prusa-quality 0.28 mm profile is likely over it. The lid plus head export to **69.07 cm³ / 85.7 g**, so Plate B is plausibly under four hours. Fix: do not schedule the hull as a guaranteed <4 h plate; reduce height/material, use a larger layer height only after thread redesign, or allocate it to the faster printer first.

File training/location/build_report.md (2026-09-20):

# build report

Generated by build_whale_locations.py. Counts are rows at each step.

| source | step | n |
|---|---|---:|
| watkins | clips in catalogue | 15,248 |
| watkins | dropped: not a cetacean (seals, sea otter, unlabeled) | 958 |
| watkins | dropped: captive recording (aquarium, tank, zoo) | 1,595 |
| watkins | dropped: no recording date | 581 |
| watkins | dropped: implausible date (outside 1940-2010) | 0 |
| watkins | position parsed from recordist note (minute precision) | 2,309 |
| watkins | note position rejected (disagrees with record by >2 deg) | 0 |
| watkins | dropped: no position at all | 889 |
| watkins | dropped: position out of range | 0 |
| watkins | clips kept | 11,225 |
| watkins | events (species x day x position) | 214 |
| dclde | annotations in Annotations.csv | 207,574 |
| dclde | dropped: not a whale (abiotic, undetermined biological) | 23,490 |
| dclde | dropped: annotator flagged killer whale as uncertain | 841 |
| dclde | dropped: hydrophone position unpublished (DFO sites) | 148,820 |
| dclde | dropped: unparseable UTC | 0 |
| dclde | annotations kept | 34,423 |
| dclde | events (site x species x ecotype x minute) | 5,537 |
| aad | annotations read from 79 Raven selection tables | 77,080 |
| aad | dropped: 'unidentified call' tables (no species) | 33,003 |
| aad | dropped: unparseable Begin Date Time | 0 |
| aad | dropped: timestamp outside deployment years | 0 |
| aad | annotations kept | 77,080 |
| aad | events (site x species x call type x minute) | 42,777 |
| all | events written to whale_locations.csv | 48,528 |
| all | site x species x day rows in whale_presence_daily.csv | 2,205 |

## events per source and species

| | events | detections | sites | first | last |
|:---|---:|---:|---:|:---|:---|
| ('aad', 'Antarctic blue whale') | 33312 | 49934 | 11 | 2005-02-05T23:38:00Z | 2017-11-06T19:49:00Z |
| ('aad', 'Fin whale') | 9465 | 27146 | 10 | 2005-02-27T23:29:00Z | 2017-05-17T11:31:00Z |
| ('dclde', 'Humpback whale') | 905 | 1193 | 5 | 2011-10-07T11:58:00Z | 2022-07-11T15:33:00Z |
| ('dclde', 'Killer whale') | 4632 | 33230 | 24 | 2011-02-10T11:40:00Z | 2023-04-28T22:04:00Z |
| ('watkins', 'Atlantic spotted dolphin') | 1 | 237 | 1 | 1961-08-06T00:00:00Z | 1961-08-06T00:00:00Z |
| ('watkins', 'Atlantic white-sided dolphin') | 4 | 498 | 3 | 1961-09-30T00:00:00Z | 1979-04-25T00:00:00Z |
| ('watkins', 'Beluga') | 6 | 108 | 5 | 1962-06-08T00:00:00Z | 1968-09-11T00:00:00Z |
| ('watkins', 'Blue whale') | 2 | 3 | 2 | 1974-08-09T00:00:00Z | 1974-08-09T00:00:00Z |
| ('watkins', 'Bowhead whale') | 8 | 85 | 3 | 1971-01-08T00:00:00Z | 1979-10-19T00:00:00Z |
| ('watkins', 'Clymene dolphin') | 2 | 328 | 2 | 1983-10-31T00:00:00Z | 1983-11-14T00:00:00Z |
| ('watkins', "Commerson's dolphin") | 1 | 1 | 1 | 1968-12-10T00:00:00Z | 1968-12-10T00:00:00Z |
| ('watkins', 'Common bottlenose dolphin') | 2 | 125 | 2 | 1951-04-06T00:00:00Z | 1992-04-27T00:00:00Z |
| ('watkins', 'Common dolphin') | 6 | 860 | 5 | 1957-07-23T00:00:00Z | 1990-06-20T00:00:00Z |
| ('watkins', 'Common/dwarf minke whale') | 2 | 24 | 2 | 1964-11-22T00:00:00Z | 1979-08-04T00:00:00Z |
| ('watkins', "Dall's porpoise") | 1 | 52 | 1 | 1979-08-05T00:00:00Z | 1979-08-05T00:00:00Z |
| ('watkins', 'Dusky dolphin') | 1 | 27 | 1 | 1964-12-13T00:00:00Z | 1964-12-13T00:00:00Z |
| ('watkins', 'False killer whale') | 2 | 508 | 2 | 1961-08-03T00:00:00Z | 1995-05-01T00:00:00Z |
| ('watkins', 'Fin whale') | 31 | 528 | 26 | 1958-08-05T00:00:00Z | 1982-10-28T00:00:00Z |
| ('watkins', "Fraser's dolphin") | 3 | 138 | 3 | 1991-10-26T00:00:00Z | 1994-05-08T00:00:00Z |
| ('watkins', 'Gray whale') | 2 | 36 | 2 | 1967-01-19T00:00:00Z | 1999-02-19T00:00:00Z |
| ('watkins', 'Harbour porpoise') | 2 | 23 | 2 | 1961-09-30T00:00:00Z | 1965-09-08T00:00:00Z |
| ('watkins', 'Humpback whale') | 13 | 537 | 11 | 1951-04-25T00:00:00Z | 1992-02-14T00:00:00Z |
| ('watkins', 'Killer whale') | 11 | 953 | 6 | 1958-02-19T00:00:00Z | 1993-06-01T00:00:00Z |
| ('watkins', 'Long-beaked common dolphin') | 2 | 69 | 1 | 1958-03-18T00:00:00Z | 1958-03-19T00:00:00Z |
| ('watkins', 'Long-finned pilot whale') | 14 | 1167 | 13 | 1953-06-11T00:00:00Z | 1988-07-26T00:00:00Z |
| ('watkins', 'Melon-headed whale') | 2 | 161 | 2 | 1991-10-27T00:00:00Z | 1994-05-12T00:00:00Z |
| ('watkins', 'Narwhal') | 4 | 70 | 4 | 1965-08-20T00:00:00Z | 1975-08-09T00:00:00Z |
| ('watkins', 'North Atlantic right whale') | 9 | 429 | 5 | 1956-04-03T00:00:00Z | 1981-09-18T00:00:00Z |
| ('watkins', 'Pantropical spotted dolphin')  | 7 | 710 | 6 | 1963-05-05T00:00:00Z | 1994-05-07T00:00:00Z |
| ('watkins', "Risso's dolphin") | 6 | 353 | 6 | 1959-07-26T00:00:00Z | 1991-07-10T00:00:00Z |
| ('watkins', 'Rough-toothed dolphin') | 1 | 98 | 1 | 1985-09-04T00:00:00Z | 1985-09-04T00:00:00Z |
| ('watkins', 'Short-finned pilot whale') | 13 | 592 | 10 | 1957-03-16T00:00:00Z | 1994-05-08T00:00:00Z |
| ('watkins', 'Sperm whale') | 36 | 1168 | 24 | 1952-04-09T00:00:00Z | 1995-04-28T00:00:00Z |
| ('watkins', 'Spinner dolphin') | 6 | 460 | 4 | 1971-05-09T00:00:00Z | 1981-11-15T00:00:00Z |
| ('watkins', 'Striped dolphin') | 10 | 681 | 8 | 1958-08-11T00:00:00Z | 1990-08-13T00:00:00Z |
| ('watkins', 'White-beaked dolphin') | 4 | 196 | 3 | 1959-02-28T00:00:00Z | 1972-05-02T00:00:00Z |

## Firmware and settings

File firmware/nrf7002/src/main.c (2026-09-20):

//
// Keiko hydrophone node — nRF7002 DK (nRF5340 + nRF7002 Wi-Fi companion).
//
// Samples the piezo front end on AIN0 at a fixed rate from a cooperative
// Zephyr thread paced by a kernel timer, and ships raw 12-bit SAADC counts to
// the pipeline as one UDP datagram per block. Same sampler/ring/sender split
// as firmware/unoq/sketch/hydro.cpp, but there is no Linux side here: the MCU
// owns the Wi-Fi link and writes the "KEIK" header itself.
//
//   magic 4s "KEIK" | ver B 1 | node B | fmt B 0=int16 raw ADC | bits B 12 |
//   fs f Hz | seq I | t_ns Q node uptime | n H | n x int16 (little-endian)
//
// fs is measured from the block timestamps on the node (same EMA the UNO Q's
// Python side uses), so a period rounded to RTC ticks still reports the real
// rate. t_ns is this node's uptime, not a shared clock — TDOA needs SNTP.
//
// Budget: Wi-Fi is not the bottleneck the UNO Q's 115200-baud Bridge was.
// 12-bit samples at 8192 Hz is 16 kB/s = 32 datagrams/s of 538 bytes.

#include <zephyr/kernel.h>
#include <zephyr/device.h>
#include <zephyr/drivers/adc.h>
#include <zephyr/drivers/gpio.h>
#include <zephyr/net/net_if.h>
#include <zephyr/net/net_mgmt.h>
#include <zephyr/net/net_event.h>
#include <zephyr/net/wifi_mgmt.h>
#include <zephyr/net/dhcpv4.h>
#include <zephyr/net/socket.h>
#include <zephyr/sys/byteorder.h>
#include <zephyr/logging/log.h>
#include <errno.h>
#include <math.h>
#include <string.h>

LOG_MODULE_REGISTER(keiko, LOG_LEVEL_INF);

// ---- configuration (Kconfig: keiko.conf / prj.conf) ------------------------
#define SAMPLE_PERIOD_TICKS CONFIG_KEIKO_SAMPLE_PERIOD_TICKS  // RTC runs at 32768 Hz: 4 ticks = 122 us = 8192 Hz
#define BLOCK               CONFIG_KEIKO_BLOCK                // samples per datagram
#define NBLOCKS             4                                 // ring depth; sender may lag by NBLOCKS-1 blocks
#define NODE_ID             CONFIG_KEIKO_NODE_ID
#define ADC_BITS            12
#define ADC_FULL_SCALE_MV   CONFIG_KEIKO_ADC_FULL_SCALE_MV    // 0.6 V ref / gain in the overlay (1/3 -> 1800 mV)

static const struct adc_dt_spec adc_ch = ADC_DT_SPEC_GET_BY_IDX(DT_PATH(zephyr_user), 0);
static const struct gpio_dt_spec led_run  = GPIO_DT_SPEC_GET_OR(DT_ALIAS(led0), gpios, {0});  // blinks once per health line
static const struct gpio_dt_spec led_wifi = GPIO_DT_SPEC_GET_OR(DT_ALIAS(led1), gpios, {0});  // on while the link is up

// ---- sampler <-> sender plumbing ------------------------------------------
static int16_t  ring[NBLOCKS][BLOCK];
static uint32_t ring_t0_us[NBLOCKS];
static uint32_t dropped_blocks;             // blocks overwritten because the sender could not keep up

K_MSGQ_DEFINE(ready_q, sizeof(uint8_t), NBLOCKS - 1, 1);  // depth NBLOCKS-1 keeps the block being filled private
K_SEM_DEFINE(tick_sem, 0, 1);                             // max 1: late ticks coalesce instead of piling up

static struct k_timer tick_timer;
static void on_tick(struct k_timer *t) { ARG_UNUSED(t); k_sem_give(&tick_sem); }

static inline uint32_t now_us(void) { return (uint32_t)k_ticks_to_us_floor64(k_uptime_ticks()); }
static inline uint64_t now_ns(void) { return k_ticks_to_ns_floor64(k_uptime_ticks()); }

K_THREAD_STACK_DEFINE(sampler_stack, 1024);
static struct k_thread sampler_thread;

static void sampler(void *a, void *b_, void *c)
{
    ARG_UNUSED(a); ARG_UNUSED(b_); ARG_UNUSED(c);
    int16_t sample;
    struct adc_sequence seq = { .buffer = &sample, .buffer_size = sizeof(sample) };
    adc_sequence_init_dt(&adc_ch, &seq);

    uint8_t b = 0;
    size_t  i = 0;
    ring_t0_us[b] = now_us();
    for (;;) {
        k_sem_take(&tick_sem, K_FOREVER);
        int raw = (adc_read_dt(&adc_ch, &seq) == 0) ? sample : (1 << (ADC_BITS - 1));  // adc error -> mid-scale, keeps timing intact
        if (raw < 0) raw = 0;                                                            // SAADC can return slightly negative counts near 0 V
        ring[b][i++] = (int16_t)raw;
        if (i == BLOCK) {
            i = 0;
            if (k_msgq_put(&ready_q, &b, K_NO_WAIT) == 0) {
                b = (b + 1) % NBLOCKS;
            } else {
                dropped_blocks++;             // sender is behind: reuse this block, keep sampling
            }
            ring_t0_us[b] = now_us();
        }
    }
}

// ---- Wi-Fi -----------------------------------------------------------------
static struct net_mgmt_event_callback wifi_cb, ipv4_cb;
static K_SEM_DEFINE(ipv4_ready, 0, 1);
static atomic_t link_up;

static void wifi_connect(struct k_work *w);
static K_WORK_DELAYABLE_DEFINE(reconnect_work, wifi_connect);

static void wifi_connect(struct k_work *w)
{
    ARG_UNUSED(w);
    struct net_if *iface = net_if_get_first_wifi();
    struct wifi_connect_req_params p = {
        .ssid        = (const uint8_t *)CONFIG_KEIKO_WIFI_SSID,
        .ssid_length = strlen(CONFIG_KEIKO_WIFI_SSID),
        .psk         = (const uint8_t *)CONFIG_KEIKO_WIFI_PSK,
        .psk_length  = strlen(CONFIG_KEIKO_WIFI_PSK),
        .security    = strlen(CONFIG_KEIKO_WIFI_PSK) ? WIFI_SECURITY_TYPE_PSK : WIFI_SECURITY_TYPE_NONE,
        .channel     = WIFI_CHANNEL_ANY,
        .band        = WIFI_FREQ_BAND_UNKNOWN,
        .mfp         = WIFI_MFP_OPTIONAL,
        .timeout     = SYS_FOREVER_MS,
    };
    LOG_INF("wifi: connecting to \"%s\"", CONFIG_KEIKO_WIFI_SSID);
    int rc = net_mgmt(NET_REQUEST_WIFI_CONNECT, iface, &p, sizeof(p));
    if (rc) {
        LOG_ERR("wifi: connect request failed (%d), retrying in 5 s", rc);
        k_work_schedule(&reconnect_work, K_SECONDS(5));
    }
}

static void on_wifi_event(struct net_mgmt_event_callback *cb, uint32_t ev, struct net_if *iface)
{
    ARG_UNUSED(iface);
    const struct wifi_status *st = cb->info;
    switch (ev) {
    case NET_EVENT_WIFI_CONNECT_RESULT:
        if (st->status) {
            LOG_ERR("wifi: connect failed (%d), retrying in 5 s", st->status);
            k_work_schedule(&reconnect_work, K_SECONDS(5));
        } else {
            LOG_INF("wifi: associated, waiting for DHCP");
            net_dhcpv4_start(net_if_get_first_wifi());
        }
        break;
    case NET_EVENT_WIFI_DISCONNECT_RESULT:
        LOG_WRN("wifi: disconnected, reconnecting in 2 s");
        atomic_set(&link_up, 0);
        if (led_wifi.port) gpio_pin_set_dt(&led_wifi, 0);
        k_work_schedule(&reconnect_work, K_SECONDS(2));
        break;
    }
}

static void on_ipv4_event(struct net_mgmt_event_callback *cb, uint32_t ev, struct net_if *iface)
{
    ARG_UNUSED(iface);
    if (ev != NET_EVENT_IPV4_ADDR_ADD) return;
    char ip[NET_IPV4_ADDR_LEN] = "?";
    if (cb->info && cb->info_length == sizeof(struct in_addr)) {   // the event carries the new address
        net_addr_ntop(AF_INET, cb->info, ip, sizeof(ip));
    }
    LOG_INF("wifi: up, ip %s", ip);
    atomic_set(&link_up, 1);
    if (led_wifi.port) gpio_pin_set_dt(&led_wifi, 1);
    k_sem_give(&ipv4_ready);
}

// ---- UDP -------------------------------------------------------------------
struct __packed keik_hdr {
    char     magic[4];
    uint8_t  ver, node, fmt, bits;
    float    fs;
    uint32_t seq;
    uint64_t t_ns;
    uint16_t n;
};
BUILD_ASSERT(sizeof(struct keik_hdr) == 26, "header must match struct.Struct('<4sBBBBfIQH')");

static int udp_open(struct sockaddr_in *dst)
{
    memset(dst, 0, sizeof(*dst));
    dst->sin_family = AF_INET;
    dst->sin_port = htons(CONFIG_KEIKO_UDP_PORT);
    if (zsock_inet_pton(AF_INET, CONFIG_KEIKO_UDP_HOST, &dst->sin_addr) != 1) {
        // not a dotted quad: resolve it (needs CONFIG_DNS_RESOLVER)
        struct zsock_addrinfo hints = { .ai_family = AF_INET, .ai_socktype = SOCK_DGRAM }, *res;
        int rc = zsock_getaddrinfo(CONFIG_KEIKO_UDP_HOST, NULL, &hints, &res);
        if (rc) {
            LOG_ERR("udp: cannot resolve \"%s\" (%d)", CONFIG_KEIKO_UDP_HOST, rc);
            return -1;
        }
        dst->sin_addr = ((struct sockaddr_in *)res->ai_addr)->sin_addr;
        zsock_freeaddrinfo(res);
    }
    int s = zsock_socket(AF_INET, SOCK_DGRAM, IPPROTO_UDP);
    if (s < 0) { LOG_ERR("udp: socket failed (%d)", errno); return -1; }
    if (dst->sin_addr.s_addr == 0xFFFFFFFFu) {             // 255.255.255.255
        int one = 1;
        zsock_setsockopt(s, SOL_SOCKET, SO_BROADCAST, &one, sizeof(one));
    }
    char ip[NET_IPV4_ADDR_LEN];
    net_addr_ntop(AF_INET, &dst->sin_addr, ip, sizeof(ip));
    LOG_INF("keiko nrf7002 node %d -> udp %s:%d (%s)", NODE_ID, ip, CONFIG_KEIKO_UDP_PORT, CONFIG_KEIKO_UDP_HOST);
    return s;
}

// ---- main: bring-up, then the sender loop (the UNO Q sketch's loop()) ------
int main(void)
{
    if (led_run.port)  { gpio_pin_configure_dt(&led_run, GPIO_OUTPUT_INACTIVE); }
    if (led_wifi.port) { gpio_pin_configure_dt(&led_wifi, GPIO_OUTPUT_INACTIVE); }

    if (!adc_is_ready_dt(&adc_ch) || adc_channel_setup_dt(&adc_ch) != 0) {
        LOG_ERR("adc: channel setup failed");
        return 0;
    }

    net_mgmt_init_event_callback(&wifi_cb, on_wifi_event, NET_EVENT_WIFI_CONNECT_RESULT | NET_EVENT_WIFI_DISCONNECT_RESULT);
    net_mgmt_add_event_callback(&wifi_cb);
    net_mgmt_init_event_callback(&ipv4_cb, on_ipv4_event, NET_EVENT_IPV4_ADDR_ADD);
    net_mgmt_add_event_callback(&ipv4_cb);
    k_work_schedule(&reconnect_work, K_NO_WAIT);
    k_sem_take(&ipv4_ready, K_FOREVER);

    struct sockaddr_in dst;
    int sock = udp_open(&dst);
    if (sock < 0) return 0;

    // sampler starts only once the socket exists, so the ring never fills with nowhere to go
    k_thread_create(&sampler_thread, sampler_stack, K_THREAD_STACK_SIZEOF(sampler_stack),
                    sampler, NULL, NULL, NULL,
                    K_PRIO_COOP(1), 0, K_NO_WAIT);   // cooperative: preempts main + net threads on every tick
    k_thread_name_set(&sampler_thread, "hydro_sampler");
    k_timer_init(&tick_timer, on_tick, NULL);
    k_timer_start(&tick_timer, K_TICKS(SAMPLE_PERIOD_TICKS), K_TICKS(SAMPLE_PERIOD_TICKS));

    static uint8_t pkt[sizeof(struct keik_hdr) + BLOCK * sizeof(int16_t)];
    struct keik_hdr *h = (struct keik_hdr *)pkt;
    memcpy(h->magic, "KEIK", 4);
    h->ver = 1; h->node = NODE_ID; h->fmt = 0; h->bits = ADC_BITS; h->n = BLOCK;

    uint32_t seq = 0, last_t0 = 0, send_err = 0;
    float fs = 0.f, dc = -1.f;
    // once-a-second health line, same fields as the UNO Q's python/main.py
    int64_t  stat_t = k_uptime_get();
    uint32_t stat_blocks = 0, stat_n = 0; float stat_sq = 0.f; int stat_peak = 0;

    for (;;) {
        uint8_t b;
        k_msgq_get(&ready_q, &b, K_FOREVER);   // blocks (not spins), so the sampler thread gets the CPU
        const int16_t *x = ring[b];
        uint32_t t0 = ring_t0_us[b];

        if (seq) {                              // sample rate from consecutive block timestamps
            uint32_t dt = t0 - last_t0;
            if (dt) { float f = BLOCK * 1e6f / dt; fs = (fs == 0.f) ? f : 0.9f * fs + 0.1f * f; }
        }
        last_t0 = t0;

        float m = 0.f;
        for (size_t i = 0; i < BLOCK; i++) m += x[i];
        m /= BLOCK;
        dc = (dc < 0.f) ? m : 0.98f * dc + 0.02f * m;   // the front end biases AIN0 to ~VDD/2; this is the number to check

        h->fs = fs; h->seq = seq++; h->t_ns = now_ns();
        memcpy(pkt + sizeof(*h), x, BLOCK * sizeof(int16_t));
        if (!atomic_get(&link_up) || zsock_sendto(sock, pkt, sizeof(pkt), 0, (struct sockaddr *)&dst, sizeof(dst)) < 0) {
            send_err++;                         // link down or pipeline unreachable; keep the sampler's timing intact
        }

        for (size_t i = 0; i < BLOCK; i++) {
            float ac = x[i] - dc;
            stat_sq += ac * ac;
            int pk = (int)fabsf(ac);
            if (pk > stat_peak) stat_peak = pk;
        }
        stat_n += BLOCK; stat_blocks++;
        int64_t now = k_uptime_get();
        if (now - stat_t >= 1000) {
            const float lsb_mv = (float)ADC_FULL_SCALE_MV / (1 << ADC_BITS);
            float rms_mv = sqrtf(stat_sq / MAX(stat_n, 1u)) * lsb_mv;
            printk("fs=%7.1fHz blocks/s=%3u dc=%.2fV rms=%6.1fmV peak=%6.1fmV mcu_drops=%u send_err=%u\n",
                   (double)fs, stat_blocks, (double)(dc * lsb_mv / 1000.f), (double)rms_mv,
                   (double)(stat_peak * lsb_mv), dropped_blocks, send_err);
            if (led_run.port) gpio_pin_toggle_dt(&led_run);
            stat_t = now; stat_blocks = 0; stat_n = 0; stat_sq = 0.f; stat_peak = 0;
        }
    }
    return 0;
}

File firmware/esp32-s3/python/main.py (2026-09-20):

#!/usr/bin/env python3
"""Keiko hydrophone node — ESP32-S3, host side.

The S3 has no Linux side, so this runs on the laptop the board is plugged into and
does what firmware/unoq/python/main.py does on the UNO Q: receives raw ADC blocks
from the MCU ("KBLK" frames over USB serial), then

  * prints a once-a-second health line (measured sample rate, DC bias, RMS, drops)
  * forwards each block as a UDP datagram to the pipeline (same KEIK packet as
    the UNO Q node, see PACKET FORMAT below)
  * optionally appends everything to a WAV file

    python3 main.py                             # auto-detect the board, stream to udp 127.0.0.1:5005
    python3 main.py --port /dev/cu.usbmodem101 --seconds 30 --wav clip.wav

Configuration (command line > environment variables > python/keiko.env next to
this file; the file is re-read every second, so editing it redirects the stream live):
  KEIKO_SERIAL_PORT  default auto          serial device, or "auto" = first Espressif USB device
  KEIKO_SERIAL_BAUD  default 921600        ignored by native USB CDC, matters for the UART port
  KEIKO_UDP_HOST     default 127.0.0.1     pipeline receiver ("auto" also means this machine)
  KEIKO_UDP_PORT     default 5005
  KEIKO_NODE_ID      default 1             node id in the packet header (the UNO Q is 0)
  KEIKO_WAV          default unset         path to append a 16-bit mono WAV log
  KEIKO_QUIET        default unset         set to silence the health line

SERIAL FRAME (little-endian), one per block, see sketch/hydro.cpp:
  magic   4s  b"KBLK"
  seq     I   MCU block counter
  t0_us   I   esp_timer_get_time() at the first sample
  dropped I   blocks the MCU overwrote because the sender fell behind
  n       H   sample count
  data    n * int16
  crc     H   CRC-16/CCITT-FALSE over everything above

PACKET FORMAT (little-endian), one datagram per block:
  magic  4s  b"KEIK"
  ver    B   1
  node   B   KEIKO_NODE_ID
  fmt    B   0 = raw ADC counts as int16
  bits   B   ADC resolution (12)
  fs     f   measured sample rate, Hz
  seq    I   MCU block counter
  t_ns   Q   host CLOCK_MONOTONIC ns when the block arrived
  n      H   sample count
  data   n * int16
"""

import argparse
import os
import struct
import socket
import sys
import time
import wave

import numpy as np

ADC_BITS = 12
VREF = 3.3
ESPRESSIF_VID = 0x303A          # native USB-Serial-JTAG on the S3
CP210X_VID = 0x10C4             # the DevKitC's "UART" port (CP2102N)

ENV_FILE = os.path.join(os.path.dirname(os.path.abspath(__file__)), "keiko.env")


def load_env_file(path=ENV_FILE):
    """KEY=VALUE lines (# comments allowed) into os.environ, without overriding what is already set."""
    try:
        with open(path) as f:
            for line in f:
                line = line.strip()
                if not line or line.startswith("#") or "=" not in line:
                    continue
                k, v = line.split("=", 1)
                os.environ.setdefault(k.strip(), v.strip().strip("\"'"))
    except OSError:
        pass


def resolve_udp_host(value):
    """'auto' / 'host' -> this machine (the pipeline runs here unless told otherwise)."""
    if value.strip().lower() in ("", "auto", "host"):
        return "127.0.0.1"
    return value.strip()


_REAL_ENV = dict(os.environ)          # what was set outside the file; the file never overrides these
load_env_file()
UDP_HOST = resolve_udp_host(os.environ.get("KEIKO_UDP_HOST", "auto"))
UDP_PORT = int(os.environ.get("KEIKO_UDP_PORT", "5005"))
NODE_ID = int(os.environ.get("KEIKO_NODE_ID", "1"))
WAV_PATH = os.environ.get("KEIKO_WAV")
QUIET = bool(os.environ.get("KEIKO_QUIET"))

HDR = struct.Struct("<4sBBBBfIQH")
FRAME_HDR = struct.Struct("<4sIIIH")
FRAME_MAGIC = b"KBLK"


def crc16_ccitt(data, crc=0xFFFF):
    for byte in data:
        crc ^= byte << 8
        for _ in range(8):
            crc = ((crc << 1) ^ 0x1021) & 0xFFFF if crc & 0x8000 else (crc << 1) & 0xFFFF
    return crc


def read_env_file(path=ENV_FILE):
    out = {}
    try:
        with open(path) as f:
            for line in f:
                line = line.strip()
                if line and not line.startswith("#") and "=" in line:
                    k, v = line.split("=", 1)
                    out[k.strip()] = v.strip().strip("\"'")
    except OSError:
        pass
    return out


def reload_settings(path=ENV_FILE):
    """Re-read keiko.env and apply UDP host/port/node id (keys set in the real environment win).
    Returns True if anything changed."""
    global UDP_HOST, UDP_PORT, NODE_ID
    f = read_env_file(path)
    get = lambda k, d: _REAL_ENV.get(k, f.get(k, d))
    host = resolve_udp_host(get("KEIKO_UDP_HOST", "auto"))
    port = int(get("KEIKO_UDP_PORT", "5005"))
    node = int(get("KEIKO_NODE_ID", "1"))
    changed = (host, port, node) != (UDP_HOST, UDP_PORT, NODE_ID)
    UDP_HOST, UDP_PORT, NODE_ID = host, port, node
    return changed


def watch_settings(period=1.0):
    """Daemon thread: poll keiko.env and apply changes."""
    import threading

    def run():
        last = read_env_file()
        while True:
            time.sleep(period)
            cur = read_env_file()
            if cur != last:
                last = cur
                if reload_settings():
                    print(f"settings reloaded: udp -> {UDP_HOST}:{UDP_PORT} node {NODE_ID}", flush=True)

    threading.Thread(target=run, name="keiko-env-watch", daemon=True).start()
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

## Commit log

2026-09-19 Add SLA buoy hull STLs (top + bottom with UNO Q tray)
    [bottom_sla_unoq_tray.stl, top_sla.stl]
2026-09-19 Add buoy hardware designs (moved from HackMIT-plan)
    Brings hardware/buoy-3d and hardware/buoy-v2 (OpenSCAD source, STLs,
    print previews, design review notes) into the code repo alongside the
    firmware and pipeline.
    [bottom.stl, bottom_zup_100pct.stl, bottom_zup_70pct.stl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]
2026-09-19 Add UNO Q hydrophone monitor app and potting cup print files
    [hydrophone_cup.scad, hydrophone_cup.stl, hydrophone_cup_A1.3mf]
2026-09-20 Add open-source/ website draft: one buoy on synthetic data
    Static Leaflet site showing a single Keiko buoy on Stellwagen Bank with
    a synthetic stream of telemetry, spectrogram frames, and whale
    detections. The UI reads four event types (hello, telemetry, audio,
    detection) so a real WebSocket feed can replace synthetic-stream.js
    without touching app.js.
2026-09-20 Add marine animal sound dataset (95k clips → 59 species) under training/dataset
    SQLite DB + CSV catalog matching ocean animal sounds to species, built from
    Watkins (WHOI), ReefSet v1.0, ToadFishFinder, Orcasound Pod.Cast and Zenodo
    fish sets, plus a 75-dataset catalog and 122 call-type descriptions from a
    2015–2026 marine bioacoustics literature sweep. Audio (16 GB) is excluded;
    fetch_data.sh re-downloads sources and rebuilds it via scripts/build_db.py.
    [datasets.csv, datasets_fish_invertebrates.csv, datasets_marine_mammals.csv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]
2026-09-20 Add Cornell/Marinexplore right whale upcall set (12,896 clips) to training/dataset
    North Atlantic right whale upcall vs noise, 2 s @ 2 kHz, from the Kaggle 2013
    Whale Detection Challenge via the timeseriesclassification.com RightWhaleCalls
    mirror (no login needed). DB now 108,246 clips / ~78 h. fetch_data.sh updated.
    [datasets.csv, species.csv]
2026-09-20 Full 30k North Atlantic right whale set + BEANS minke boings in training/dataset
    Replaces the 12,896-clip mirror subset with the complete Kaggle Whale Detection
    Challenge training set (30,000 clips, 7,027 NARW upcalls / 22,973 noise, 2 s @
    2 kHz) via the HF monster-monash mirror, and adds the BEANS hiceas minke boing
    set (680 boings + 533 negatives). DB now 126,563 clips. fetch_data.sh updated;
    loaders for DCLDE 2027 and the AAD Antarctic library are included but their
    audio is still downloading.
    [datasets.csv, species.csv]
2026-09-20 Add whale log-mel feature extractor + manifest/split to training/dataset
    scripts/extract_whale_features.py builds features/whales_32k_mel128_3s/
    (47,253 x 128 x 301 float16 windows) from the whale clips with a stratified
    recording-group split (24 classes). manifest.csv and labels.json are committed;
    windows.npy (3.4 GB) is regenerated by running the script.
    [manifest.csv]
2026-09-20 Rebuild open-source/ site: white, Helvetica, three panels
    Start over with a minimal page: live map (OSM), buoy status
    (position, battery, temp, uptime), live hydrophone (waveform +
    30 s spectrogram). One buoy in the Charles River basin off MIT on
    synthetic data. No dependencies beyond Leaflet from CDN.
2026-09-20 Trim site: drop waveform, battery, temp, uptime, subtitle; position on one line
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2026-09-20 Dataset v3: DCLDE 2027 killer whale ecotypes + AAD Antarctic blue/fin library (332k clips)
    Adds 97,914 DCLDE 2027 clips (killer whale boxes by ecotype: TKW/NRKW/SRKW/OKW/SAR,
    plus humpback) from a 23 GB subset of the 1.6 TB set, and 136,158 clips from the
    IWC-SORP Antarctic blue/fin library (Z-calls, D-calls, fin 20 Hz/downsweeps, minke
    bio-duck). DB is now 332,391 clips / ~315 h / 61 species. sqlite and clips.csv are
    shipped gzipped (GitHub 100 MB limit).
    [datasets.csv, species.csv]
2026-09-20 Whale CNN v2: genus-level dolphins, no-whale classes, bandwidth-mask aug, abstain rule
    - dataset: extract_features_v2.py builds features/v2_32k_mel128_3s (71,522 windows,
    22 classes) from the v3 DB: species/genus labels, other_baleen/other_toothed,
    no_whale_noise + no_whale_biophony, per-recording normalization, per-class caps
    across recording groups. manifest/labels committed.
    - train.py: random bandwidth masking, mixup, dropout 0.5, early stopping,
    hierarchy accuracy + false-alarm metrics, --noise_weight.
    - predict.py: abstain rule (--min_conf/--margin), defaults to v2 model.
    - models/whale_cnn_v2.{pt,onnx,json}: test macro-F1 0.45 (v1 0.41), hierarchy
    acc 0.87, false-alarm 0.36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
    [manifest.csv]
2026-09-20 Add GitHub-hosted detection database and wire the site to it
    data/: detections.csv (source of truth) + detections.json, buoys.csv,
    schema.json, one WAV clip and one PNG mel spectrogram per detection,
    README with pandas/R loading. Seeded with 24 synthetic detections.
    tools/keiko_data.py: add a detection from a WAV, rebuild the JSON,
    or generate synthetic rows. Database tab loads the archive and stacks
    live detections on top, with CSV download and GitHub links.
    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
2026-09-20 Track open-source/data (detection database) despite root data/ and *.wav ignores
    [buoys.csv, detections.csv]
2026-09-20 Redesign the site UI
    Live: full-bleed satellite map with hydrophone range ring, scale bar,
    map key, sightings that fade with age; instrument rail with buoy
    details, a today / last call / level stat strip, and a gridded mel
    spectrogram. Database: summary strip, detections-per-day bar chart
    with hover, filter chips, sortable time and confidence, custom play
    buttons, row hover highlights the sighting on the map. Blue-black ink,
    whale-call orange accent, Helvetica throughout, white ground.
2026-09-20 Add cleaned whale location table for presence modelling
    Triage of every data source in the repo for a whale-location model. The
    open-source/data detection DB is entirely synthetic (random positions in
    the Charles River) and is excluded. Three real sources survive: Watkins
    (WHOI), DCLDE 2027 killer whales, and the AAD/IWC-SORP Antarctic blue &
    fin library. build_whale_locations.py normalises six coordinate notations
    and four date formats, drops captive recordings, non-cetaceans, uncertain
    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
    [sites.csv, whale_locations.csv, whale_presence_daily.csv]
2026-09-20 UNO Q node: record via UDP capture, Makefile over adb by default
    - make record captures the stream on the board host with udp_listen.py --wav
    (no app restart: restarts re-flash the MCU and can wedge the router's serial link)
    - udp_listen.py: --wav/--seconds/--port, DC removal, stdlib only
    - Makefile: drop adb push --sync (board clock skew), record target, exclude recordings/
    - README: manual MVP loop (record -> predict.py -> keiko_data.py add)
2026-09-20 Add Kaggle whale-detection zip -> grayscale spectrogram tensor converter
    Replaces the TFRecord notebook flow (glob over /kaggle/input, separate
    255x255 RGB PNG dataset, PNG bytes inside TFRecords) with one script that
    reads data/train/*.aiff straight out of ~/Downloads/whale-detection-challenge.zip
    and writes a single single-channel tensor:
    features/cornell_2k_spec/X.npy uint8 (30000, 129, 251) log-power STFT, 0..255
    features/cornell_2k_spec/y.npy int8 (30000,) 1 = right whale upcall
    manifest.csv / meta.json clip <-> row mapping, STFT config, class counts
    STFT: 2 kHz, n_fft 256, hop 16 (7.8 Hz x 8 ms). Whole set builds in ~13 s on
    8 cores. The nested whale_data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
    [manifest.csv]
2026-09-20 site: Esri Dark Gray basemap tinted to the navy theme
    Replaces the satellite imagery with Esri's keyless Dark Gray Canvas, split
    into a base layer (tinted via CSS filter) and an untinted labels layer.
2026-09-20 Move the website from open-source/ to site/ and drop the public/data symlink
    open-source/ is being repurposed, so the Next.js site, its detection database
    and tools now live in site/. Every path reference (root README, firmware and
    training docs, Pages workflow, GitHub links, raw data URL) follows.
    public/data was a symlink to ../data, which broke Vercel's build: it copied
    the link into .next/output/static and then failed to mkdir through it
    (ENOENT). The dev and build scripts now copy data/ into public/data
    (gitignored) instead, and the static export ships it in out/data.
    [buoys.csv, detections.csv]
2026-09-20 Automate the live demo: make live / make demo / make test, node hot-reloads keiko.env
    pipeline/: make live finds this machine's IP on the board's subnet (netinfo.py, via adb),
    retargets the node's UDP stream at it, starts the app if needed, and runs the pipeline.
    make demo loops a public-domain NPS humpback recording (samples/humpback_nps.mp3) through
    replay_wav.py into the pipeline; make test is an offline regression (white noise -> 0 events,
    humpback -> humpback event). replay_wav.py reads mp3/flac via soundfile; the pipeline says
    where packets come from and hints when none arrive.
    firmware/unoq: python/main.py re-reads keiko.env every second and applies UDP host/port/node
    id, so `make re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
    [main.py, test_node.py]
2026-09-20 Simplify the Kaggle tensor to one npz; add Moby two-branch right-whale detector
    training/dataset:
    - cornell_kaggle_to_tensor.py now writes a single features/cornell_2k_spec.npz
    (X uint8 (30000,129,251), y int8). Dropped manifest.csv and meta.json: row i
    is always train{i+1}, so they carried nothing. whale_data.zip is cached in
    ~/.cache instead of the features dir. *.npz ignored like *.npy.
    - README: section for the two right-whale-only feature files.
    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
    [manifest.csv]
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2026-09-20 site: landing — one centered sentence, drifting waves
    Copy speaks to conservationists. Smaller type, centered. Three low-opacity
    accent-colour wave layers drift across the bottom (off under reduced motion).
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2026-09-20 Moby right-whale ensemble: trained 2-fold model, evaluation fix, results
    - train.py: evaluation compared batch-sorted predictions against labels in
    fold order (AUROC pinned at 0.50 while train loss fell). probs() now scores
    in np.sort(idx) order and evaluate() uses the same order. Defaults cut to
    2 folds / 12 epochs / patience 3 (fold 0 plateaued by epoch 10); ONNX export
    uses the TorchScript exporter (dynamo one needs onnxscript).
    - models/moby_narw.{pt,json,onnx}: 2 fold models + normalization stats,
    ensemble test AUROC 0.9766 (single models 0.9737 +/- 0.0004), acc 0.923,
    F1 0.846 on 4,500 held-out clips. Poster: 0.977 +/- 0.002.
    - README: results table, 2-fold default document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
2026-09-20 pipeline: stream over USB by default, add the usb_relay.py that make live already expected
    Venue Wi-Fi (MIT GUEST) puts the board behind a captive portal and isolates
    clients, and the phone hotspot would not show up in the board's scans, so
    the node's UDP stream now rides the USB cable: usb_relay.py wraps each
    datagram in a length prefix over `adb reverse tcp:5006` and unwraps it onto
    UDP 5005 on this machine. Verified 14 pkts/s, missing=0, clean teardown.
    VIA=wifi keeps the network path. The relay script was missing from the
    commit that brought the VIA switch, so VIA=usb was broken on main.
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2026-09-20 boston bay
    [buoys.csv, detections.csv]
2026-09-20 no idea wtf is going on:
    [buoys.csv, detections.csv]
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2026-09-20 firmware/esp32-s3: host side -- serial relay into the KEIK UDP stream, WAV log, offline test
    python/main.py is firmware/unoq/python/main.py with the transport swapped: the
    Node class (rate measurement from MCU timestamps, DC tracker, health line, KEIK
    packing, WAV log, keiko.env hot reload) is unchanged; the App Lab / router-socket
    transports are replaced by a pyserial reader and a FrameParser that resyncs on
    the KBLK magic and drops frames whose CRC-16 fails (counted as crc_bad on the
    health line). Runs on the laptop the board is plugged into, since the S3 has no
    Linux side. Board auto-detected by USB VID (Espressif native USB, then CP210x).
    - --port / --seconds / --wav flags so `make reco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
    [main.py, test_node.py, udp_listen.py]
2026-09-20 firmware/esp32-s3: Wi-Fi mode -- stream KEIK datagrams straight from the board
    What the ESP32-S3 is in the architecture for: a buoy in the water has no USB
    cable. If sketch/wifi_config.h exists (copy of the .example, gitignored) the
    sketch joins that network and sends each block as a ready-made KEIK datagram to
    the pipeline, with fs measured on the board from consecutive block timestamps
    (same estimator as main.py) and t_ns = esp_timer us since boot x 1000. The
    pipeline needs no change; it already keys streams by the node id in the header.
    Serial frames still go out whenever a host is attached (health line during
    setup), but the sender skips serial when HWCDC reports no host, so a
    backpress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
    [hydro.cpp]
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2026-09-20 training/voloridge: train on Voloridge AWS GPU + join NOAA ISD to the buoy noise floor
    Scaffold for the Voloridge "Signal in the Noise" track:
    - infra/: check, bootstrap (AL2023 + torch cu124 + their dataset tools), rsync up/down, detached tmux runs
    - train/: pretrain.sh (whale_cnn from a JSON config, width 64) and finetune.py (transfer to Charles classes,
    frozen stem + blocks, exports in whale_cnn's checkpoint format so the pipeline can load it)
    - data/: their noaa_isd/fetch.py as-is, ISD fixed-width -> hourly parser, NWS KBOS live obs in the same schema
    (public ISD archive ends 2025-08-27), Charles wav manifest + v2 feature extraction
    - analysis/: hourly noise floor x Logan weather ->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
    [charles_labels.csv]
2026-09-20 site: archive the 16 replayed humpback events, species in the detail dialog, landing subtitle + stats; elastic: fix --anomalies on ES 9
    - site/data: new source value `replay` (a real recording played through the pipeline, classified by the
    CNN) alongside field/synthetic; 16 NPS humpback events from pipeline/out archived with clips + spectrograms
    - keiko_data.py: peak_hz ignores < 20 Hz (rumble was winning the argmax); spectrogram floor at the 70th
    percentile so a real noise floor stays transparent and calls read; all 40 re-rendered
    - DetectionDetail: Species row (it was the one thing the dialog did not say)
    - Landing: one-line explanation, database link, at-a-glance stats; OpenGraph/Twit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
    [detections.csv]
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
